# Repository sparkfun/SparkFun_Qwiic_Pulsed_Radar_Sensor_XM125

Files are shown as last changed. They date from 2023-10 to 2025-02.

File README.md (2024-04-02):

SparkFun Pulsed Coherent Radar Sensor - Acconeer XM125 (Qwiic)
========================================

SparkFun Pulsed Coherent Radar Sensor – Acconeer XM125 (Qwiic) (https://www.sparkfun.com/products/24540)

[*SparkFun Pulsed Coherent Radar Sensor – Acconeer XM125 (Qwiic) (SEN-24540)*](https://www.sparkfun.com/products/24540)

Forget ultrasonic and infrared sensors; the SparkFun Qwiic Pulsed Coherent Radar Sensor - Acconeer XM125 brings powerful 60 GHz radar technology to your projects. This sensor isn't limited to surface detection; it can see through walls, cabinets, and even pockets (depending on the material), making it perfect for unique applications. Measure distances with millimeter precision, detect motion, the speed of an object, or even gestures!

The XM125 boasts an impressive range of up to 20 meters, allowing you to create long-range sensing projects. The actual measurable distance is dependent on the object size, shape, dielectric properties, and lens (e.g. water level measurements up to 20 meters with lens utilization, human presence detection up to 7 meters with lens-free utilization). Despite its power, the sensor has remarkably low in power consumption, which is ideal for battery-powered applications. The real magic lies in the sensor's ability to do more than measure distance; the XM125 can differentiate between stationary objects and moving targets using pulsed coherent radar. This means you can sense an object's presence and how fast something is moving!

We've included a USB type-C connector, ESD protection diodes on the USB data lines, and a CH340C USB-to-serial converter to connect the XM125 directly to your computer's COM port. Power is regulated down for the XM125 with the AP2112K 3.3V/600mA and RT9080 1.8V/600mA voltage regulators. Buttons for reset and boot are included when resetting the module or setting the board into bootloader mode. Utilizing our handy Qwiic system, no soldering is required to connect it to the rest of your system. However, we still have broken out 0.1in.-spaced pins if you prefer a breadboard.

We've written an Arduino library when the I<sup>2</sup>C presence or distance detection firmware is loaded onto the XM125 module. With the I<sup>2</sup>C presence detection firmware, you can sense when an object is moving in an environment and how far away it is from the sensor. You can detect slow and fast movements with the inter-presence and intra-presence scores, respectively. The I<sup>2</sup>C distance detection firmware is similar to the presence detector by providing distance measurements. However, distance detection will provide information when it detects objects within range. The distance detection firmware can also adjust the sensor's threshold and sensitivity. The read range can also be configured to a certain distance away with either firmware.

Acconeer has also developed a visualization tool written in Python that demonstrates data collection in real time. The [Acconeer Exploration Tool](https://github.com/acconeer/acconeer-python-exploration) is an incredible resource, especially when starting out with the XM125 module to debug and explore the sensor's capabilities. This allows you to fine-tune the sensor for your application. For example, it will graph distance or presence sensing, giving you a count of the number of sweeps, which communication port data is being sent through, and much more. It will also guide you to the optimal sensor settings and help you fine-tune the data processing for your final product implementation. The tool supports Windows and Linux and requires Python version 3.8 or later. This tool is available through their GitHub Repository. Head on over and take a look!

With the SparkFun Qwiic Pulsed Coherent Radar Sensor, a world of new project possibilities opens up. Imagine creating presence detection systems for smart homes and security applications, parking space occupancy detection, gesture recognition interfaces for unique user control, level measurement (for example, in tanks or waste containers), through-wall imaging systems for search and rescue, or even advanced robotics with object avoidance and navigation.

Repository Contents
-------------------

* **.github/workflows** - YAML files used for GitHub Actions and GitHub Pages/mkdocs
* **/Firmware** - Firmware for the XM125 module
* **/Hardware** - Eagle design files (.brd, .sch)
  * **/Production** - Production panel files (.brd)
* **/docs** - Online documentation files
  * **/assets** - Folder containing all the file assets used for product documentation
    * **/board_files** - Copy of design files used for product documentation
    * **/component_documentation** - Datasheets and manuals for hardware components
    * **/img** - Images for product documentation
  * **/github** - Files stating how to contribute and filing issues used for product documentation
  * **/javascript** - Folder containing custom javascript used for product documentation
  * **/stylesheet** - Folder containing CSS files used for product documentation
* **/overrides** - Customization files used for product documentation
  * **/.icons** - Icons used for GitHub used for product documentation
  * **./partials** - Used for product documentation

Documentation
--------------
* **[Library](https://github.com/sparkfun/SparkFun_Qwiic_XM125_Arduino_Library)** - Arduino library for the SparkFun Qwiic Pulsed Coherent Radar Sensor - XM125.
* **[Hookup Guide](https://docs.sparkfun.com/SparkFun_Qwiic_Pulsed_Radar_Sensor_XM125)** - Basic hookup guide for the SparkFUn Qwiic Pulsed Coherent Radar Sensor - XM125.

Product Versions
----------------
* [SEN-24540](https://www.sparkfun.com/products/24540) - Initial Release

Version History
---------------
* V1.0 - Intial Release

License Information
-------------------

This product is _**open source**_! 

Please review the LICENSE.md file for license information. 

If you have any questions or concerns on licensing, please contact technical support on our [SparkFun forums](https://forum.sparkfun.com/viewforum.php?f=152).

Distributed as-is; no warranty is given.

- Your friends at SparkFun.

_<COLLABORATION CREDIT>_

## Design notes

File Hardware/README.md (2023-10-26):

SparkFun <PRODUCT NAME> Design Files
=====================================

The .sch and .brd files hare are Eagle CAD schematic and PCB design files from SparkFun Electronics.
A freeware version of Autodesk Eagle can be found [here](https://www.autodesk.com/products/eagle/free-download).

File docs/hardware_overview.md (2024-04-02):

In this section, we will highlight the hardware and pins that are broken out on the SparkFun Pulsed Coherent Radar Sensor - XM125 (Qwiic). For more information, check out our [Resources and Going Further](../resources/) for the XM125 Module and the A121 Pulsed Coherent Radar Sensor.

<div style="text-align: center;">
  <table>
    <tr style="vertical-align:middle;">
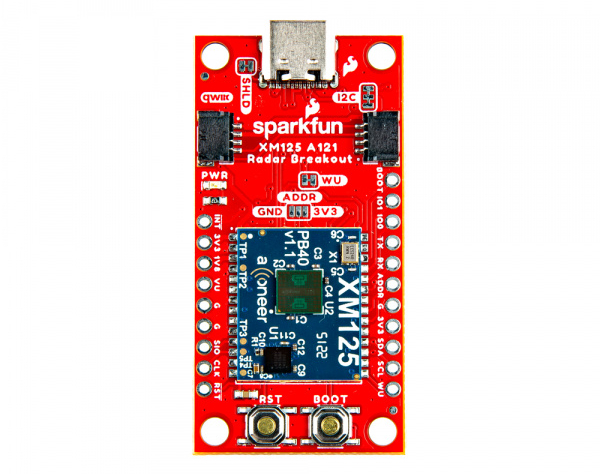
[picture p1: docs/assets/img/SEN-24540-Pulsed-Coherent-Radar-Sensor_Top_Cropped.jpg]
Top View
     <td style="text-align: center; vertical-align: middle; border: solid 1px #cccccc;"></td>
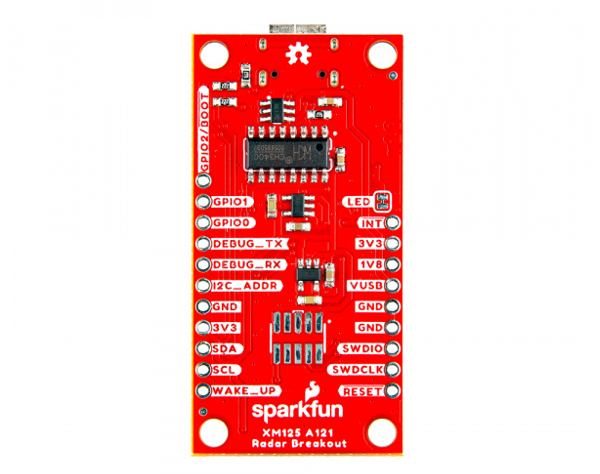
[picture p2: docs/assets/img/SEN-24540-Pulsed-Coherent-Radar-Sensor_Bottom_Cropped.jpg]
Bottom View
     <td style="text-align: center; vertical-align: middle; border: solid 1px #cccccc;"></td>
    </tr>
    <tr style="vertical-align:middle;">
     <td style="text-align: center; vertical-align: middle; border: solid 1px #cccccc;"><i>Top View</i></td>
     <td style="text-align: center; vertical-align: middle; border: solid 1px #cccccc;"><i>Bottom View</i></td>
    </tr>
  </table>
</div>

### XM125 Module

The board breaks out the Acconeer XM125 module with some application circuits.

<div style="text-align: center;">
  <table>
    <tr style="vertical-align:middle;">
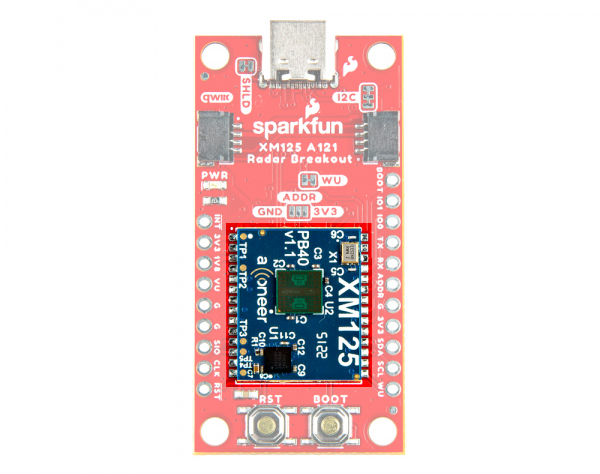
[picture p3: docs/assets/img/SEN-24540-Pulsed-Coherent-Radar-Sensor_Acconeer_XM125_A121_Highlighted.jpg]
Acconeer XM125 Module
     <td style="text-align: center; vertical-align: middle; border: solid 1px #cccccc;"></td>
    </tr>
    <tr style="vertical-align:middle;">
     <td style="text-align: center; vertical-align: middle; border: solid 1px #cccccc;"><i>Acconeer XM125 Module</i></td>
    </tr>
  </table>
</div>

Below are a few specifications from the datasheet.

* Acconeer XM125 Module
    * A121
        * 60GHz Pulsed Coherent Radar (PCR)
        * Integrated Baseband, RF Front-End and Antenna in Package
        * Detect Distance, Speed, Motion, and Objects up to 20 Meters**&#42;** Away
        * Millimeter Precise Readings
        * Low Power Consumption
    * STMicroelectronics STM32L431CBY6
        * 32-bit Arm&reg; Cortex&reg; M4 MCU
        * Clock Speed: 80 MHz
        * Flash: 128kB
        * RAM: 68kB

!!! note "*Note"
    The actual measurable distance is dependent on the object size, shape, dielectric properties, and lens (e.g. water level measurements up to 20 meters with lens utilization, human presence detection up to 7 meters with lens-free utilization).

For users using the XM125 module to detect objects through a material (especially for those placing the board in an enclosure), you may want to check out [Acconeer's Hardware and Physical Integration Guideline PCR Sensors A111 & A121 User Guide](../assets/component_documentation/Hardware-integration-guideline.pdf).

<div style="text-align: center"><a href="../assets/component_documentation/Hardware-integration-guideline.pdf" class="md-button">Acconeer's Hardware and Physical Integration Guideline PCR Sensors A111 & A121 User Guide</a></div>

!!! note
    Due to the higher frequencies, pulsed coherent radar sensors may be regulated in certain countries. Be sure to check local regulations before use.

### Power

There are a variety of power and power-related nets broken out to the USB connector, Qwiic connectors and plated through holes. **5V** power from the USB C Connector or PTH is regulated down to _3.3V_ with the AP2112K 3.3V/600mA voltage regulator. The voltage is further regulated down to _1.8V_ with the RT9080 1.8V/600mA voltage regulator. The logic levels for the XM125 is **3.3V** for the I/O pins.

* **VU** / **VUSB** &mdash; Power from the USB C connector's VBUS provides power to the V_BUS. The V_USB net is also connected to the edge PTH pin labeled as **VU** on the top of the board and **VUSB** on the bottom of the board. This is also connected to the input of the 3.3V voltage regulator. Make sure that power you provide to this pin does not exceed 6 volts.
* **3V3** &mdash; This connects to the 3.3V net. Both sides of the board includes a 3.3V pin (labeled as 3V3). The output of the AP2112K 3.3V voltage regulator and input of the RT9080 1.8V voltage regulator are connected to this net. 3.3V net can also be accessed through one of the Qwiic connector's pins. You should only provide a clean 3.3V power signal to those pins.
* **G** / **GND** &mdash; Of course, is the common, ground voltage (0V reference) for the system.

<div style="text-align: center;">
  <table>
    <tr style="vertical-align:middle;">
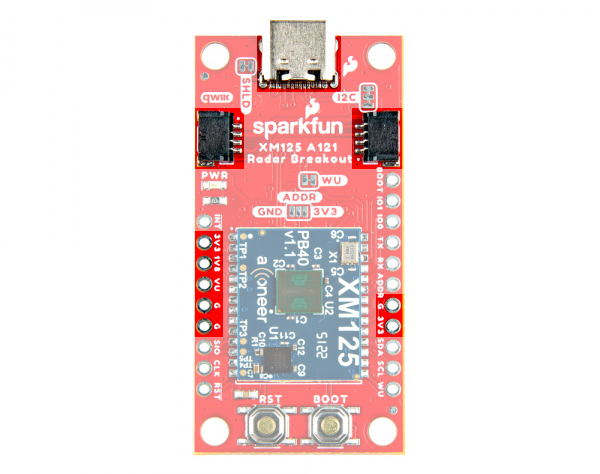
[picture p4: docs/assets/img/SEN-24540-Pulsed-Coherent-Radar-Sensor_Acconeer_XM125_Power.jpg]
Power from USB, Qwiic, and PTHs, Top View
     <td style="text-align: center; vertical-align: middle; border: solid 1px #cccccc;"></td>
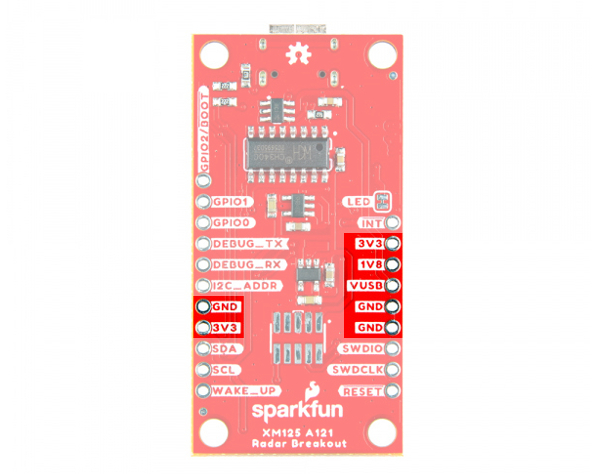
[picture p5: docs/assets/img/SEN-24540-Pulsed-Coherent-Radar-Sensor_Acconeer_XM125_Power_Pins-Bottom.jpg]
Power from PTHs, Bottom View
     <td style="text-align: center; vertical-align: middle; border: solid 1px #cccccc;"></td>
    </tr>
    <tr style="vertical-align:middle;">
     <td style="text-align: center; vertical-align: middle; border: solid 1px #cccccc;"><i>Power from USB, Qwiic, and PTHs <br />(Top View)</i></td>
     <td style="text-align: center; vertical-align: middle; border: solid 1px #cccccc;"><i>Power from PTHs <br />(Bottom View)</i></td>
    </tr>
  </table>
</div>

### CH340C USB-to-Serial Converter

ON the back of the board is a built-in CH340 USB-to-serial converter to connect the XM125's primary UART to a computer's USB port. This is useful for users viewing data, configuring the XM125, or updating firmware. ESD protection diodes are included between the USB C and the CH340C's USB data lines.

<div style="text-align: center;">
  <table>
    <tr style="vertical-align:middle;">
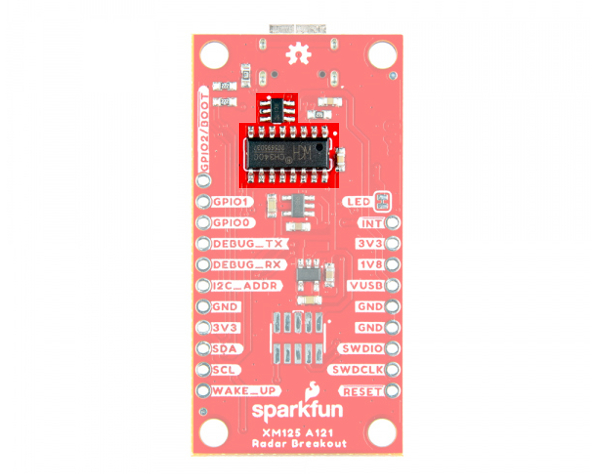
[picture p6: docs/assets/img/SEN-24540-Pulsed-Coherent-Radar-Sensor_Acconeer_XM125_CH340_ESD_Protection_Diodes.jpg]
CH340C Highlighted
     <td style="text-align: center; vertical-align: middle; border: solid 1px #cccccc;"></td>
    </tr>
    <tr style="vertical-align:middle;">
     <td style="text-align: center; vertical-align: middle; border: solid 1px #cccccc;"><i>TVS Diodes, and CH340 Highlighted</i></td>
    </tr>
  </table>
</div>

### UARTs

The board has two UARTs. The primary UART (not highlighted in the image below) is connected internally to the CH340C USB-to-Serial converter. There is also a debugging UART that is broken out on the edge of the board.

* **TX** / **DEBUG_TX** &mdash; TX out for debugging
* **RX** / **DEBUG_RX** &mdash; RX in for debugging

<div style="text-align: center;">
  <table>
    <tr style="vertical-align:middle;">
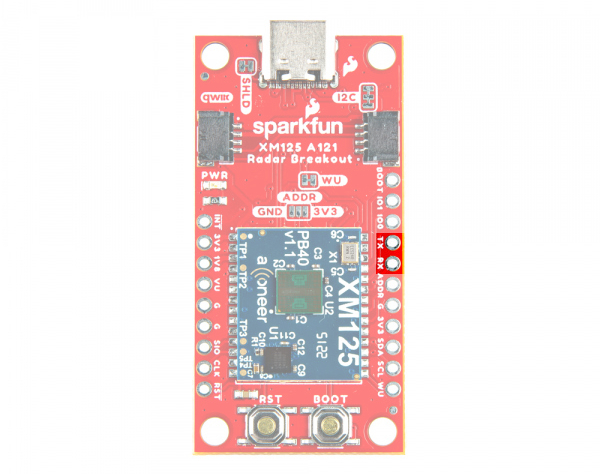
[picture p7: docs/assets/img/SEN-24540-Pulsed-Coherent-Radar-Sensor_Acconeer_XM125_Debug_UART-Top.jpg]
Debugging UART Pins, Top View
     <td style="text-align: center; vertical-align: middle; border: solid 1px #cccccc;"></td>
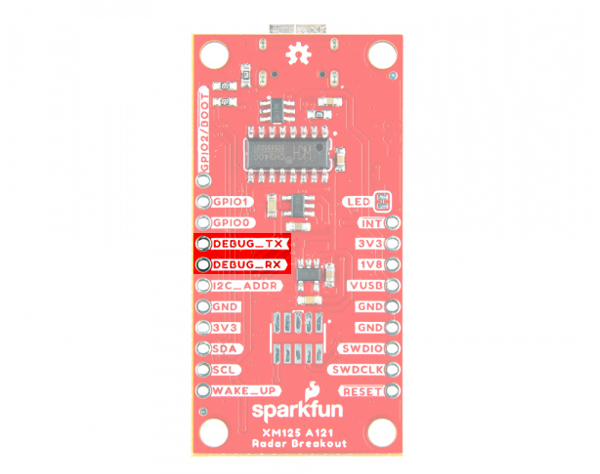
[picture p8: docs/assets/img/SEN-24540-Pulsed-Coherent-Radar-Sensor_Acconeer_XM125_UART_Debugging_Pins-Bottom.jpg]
Debugging UART Pins, Bottom View
     <td style="text-align: center; vertical-align: middle; border: solid 1px #cccccc;"></td>
    </tr>
    <tr style="vertical-align:middle;">
     <td style="text-align: center; vertical-align: middle; border: solid 1px #cccccc;"><i>Debugging UART Pins <br />(Top View)</i></td>
     <td style="text-align: center; vertical-align: middle; border: solid 1px #cccccc;"><i>Debugging UART Pins <br />(Bottom View)</i></td>
    </tr>
  </table>
</div>

!!! note
    To enable or disable UART logging, you will need to call the function after resetting the XM125 in the `setup()` function (i.e. `radarSensor.setPresenceCommand(SFE_XM125_PRESENCE_RESET_MODULE);`). Make sure to call the `distanceEnableUartLogs()`, `distanceDisableUartLogs()`, `presenceEnableUartLogs()`, or `presenceDisableUartLogs()` function before applying the configuration using the `radarSensor.setPresenceCommand(SFE_XM125_PRESENCE_APPLY_CONFIGURATION)`. The functions correspond the firmware for the presence and distance detection firmware, respectively.

### Qwiic and I<sup>2</sup>C

There are two PTHs labeled **SDA** and **SCL** on one side of the board. These are the I<sup>2</sup>C data and clock lines and are connected to two 2.2k&ohm; pull-up resistors. We also conveniently added a GND and 3.3V pin on one side should you decide to daisy chain additional I<sup>2</sup>C devices to the PTH. Similarly, you can use either of the Qwiic connectors to provide power and send data through I<sup>2</sup>C. The [Qwiic ecosystem](https://www.sparkfun.com/qwiic) is made for fast prototyping by removing the need for soldering. All you need to do is plug a Qwiic cable into the Qwiic connector and voila!

* **SDA** &mdash; I<sup>2</sup>C data
* **SCL** &mdash; I<sup>2</sup>C clock

<div style="text-align: center;">
  <table>
    <tr style="vertical-align:middle;">
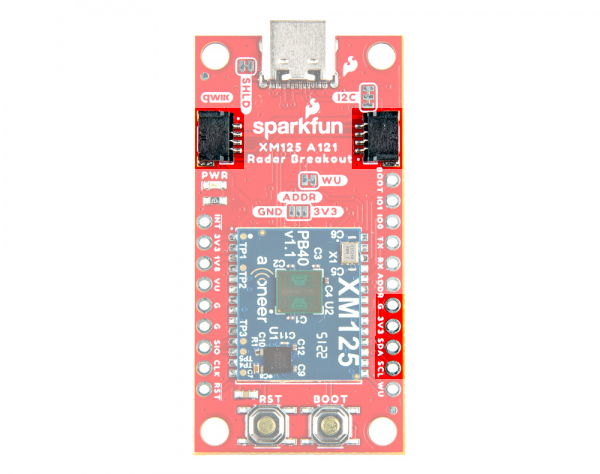
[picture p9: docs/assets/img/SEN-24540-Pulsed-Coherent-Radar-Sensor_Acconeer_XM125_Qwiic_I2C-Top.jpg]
I2C Pins and Qwiic Connectors, Top View
     <td style="text-align: center; vertical-align: middle; border: solid 1px #cccccc;"></td>
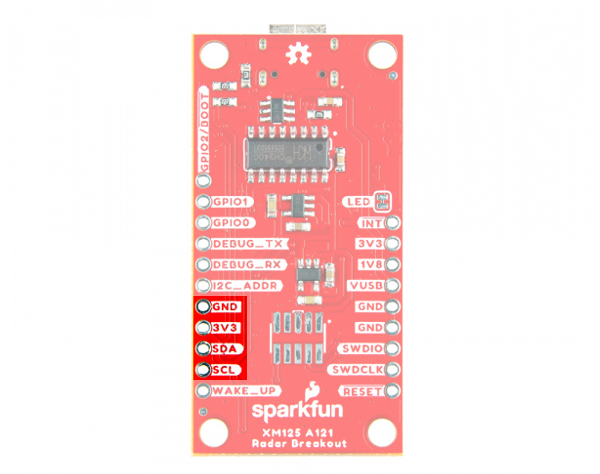
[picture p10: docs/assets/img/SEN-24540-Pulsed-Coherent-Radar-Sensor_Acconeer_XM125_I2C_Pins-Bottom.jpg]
I2C Pins, Bottom View
     <td style="text-align: center; vertical-align: middle; border: solid 1px #cccccc;"></td>
    </tr>
    <tr style="vertical-align:middle;">
     <td style="text-align: center; vertical-align: middle; border: solid 1px #cccccc;"><i>I2C and Qwiic Connectors <br />(Top View)</i></td>
     <td style="text-align: center; vertical-align: middle; border: solid 1px #cccccc;"><i>I2C Pins <br />(Bottom View)</i></td>
    </tr>
  </table>
</div>

The default address of the XM125 is set to **0x52**.

### Reset and Boot Buttons

We included two low profile buttons for reset and bootloader.

* **RST** / <b><span STYLE="text-decoration:overline">RST</span></b> / <b><span STYLE="text-decoration:overline">RESET</span></b> &mdash; Pressing down on the reset button will connect the pin to ground and reset the XM125. This is also broken out to a PTH on the edge of the board.
* **BOOT** / <b>GPIO2/<span STYLE="text-decoration:overline">BOOT</span></b> &mdash; Pressing down on the boot button will connect the pin to 3.3V. This will put it into bootloader mode when the XM125 is starting up. This is also broken out to a PTH on the edge of the board.  The alternative function of this pin is also used as a general purpose I/O. This can be configurable for different functions. At the time of writing, GPIO2 is not functional with the current firmware. The functionality is to be implemented in the future.

<div style="text-align: center;">
  <table>
    <tr style="vertical-align:middle;">
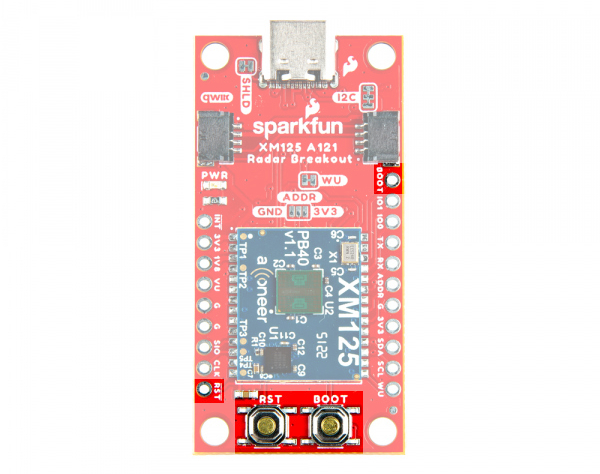
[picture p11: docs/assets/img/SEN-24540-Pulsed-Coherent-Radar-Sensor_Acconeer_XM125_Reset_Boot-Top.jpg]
Reset and Boot Pins and Buttons, Top View
     <td style="text-align: center; vertical-align: middle; border: solid 1px #cccccc;"></td>
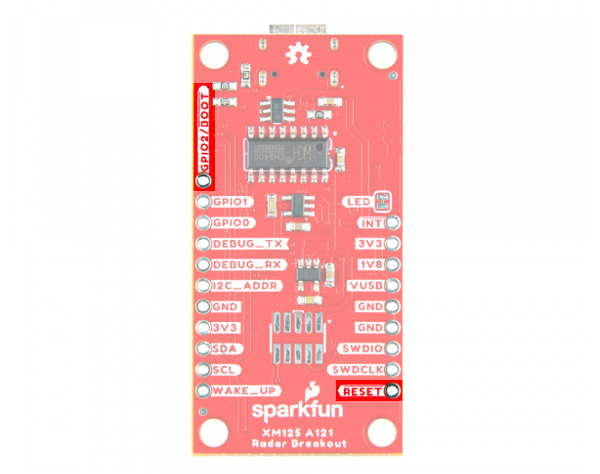
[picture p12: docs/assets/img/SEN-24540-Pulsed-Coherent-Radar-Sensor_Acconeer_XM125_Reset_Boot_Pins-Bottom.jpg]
Reset and Boot Pins , Bottom View
     <td style="text-align: center; vertical-align: middle; border: solid 1px #cccccc;"></td>
    </tr>
    <tr style="vertical-align:middle;">
     <td style="text-align: center; vertical-align: middle; border: solid 1px #cccccc;"><i>Reset and Boot Pins and Buttons <br />(Top View)</i></td>
     <td style="text-align: center; vertical-align: middle; border: solid 1px #cccccc;"><i>Reset and Boot Pins <br />(Bottom View)</i></td>
    </tr>
  </table>
</div>

!!! note
    We included low profile buttons on the board to reduce the amount of reflections when using the XM125.

### SWD Pins

The edge of the board includes the SWDIO and SWDCLK programming pins. On the back of the board, there is a 2x5 SWD footprint to solder a [SMD 2x5 header](https://www.sparkfun.com/products/22890). This is available for users that want to debug and flash the XM125's STM32L431 using a programmer.

* **SWDIO** &mdash; Serial wire debug I/O.
* **SWDCLK** &mdash; Serial wire debug clock.

<div style="text-align: center;">
  <table>
    <tr style="vertical-align:middle;">
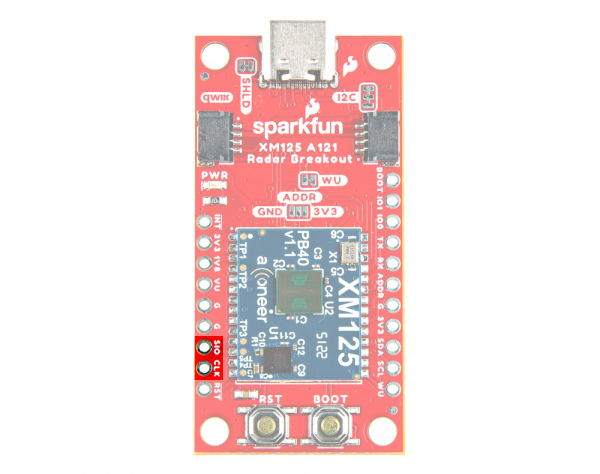
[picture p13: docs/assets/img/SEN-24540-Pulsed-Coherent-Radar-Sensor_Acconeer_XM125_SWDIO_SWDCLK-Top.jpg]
     <td style="text-align: center; vertical-align: middle; border: solid 1px #cccccc;"></td>
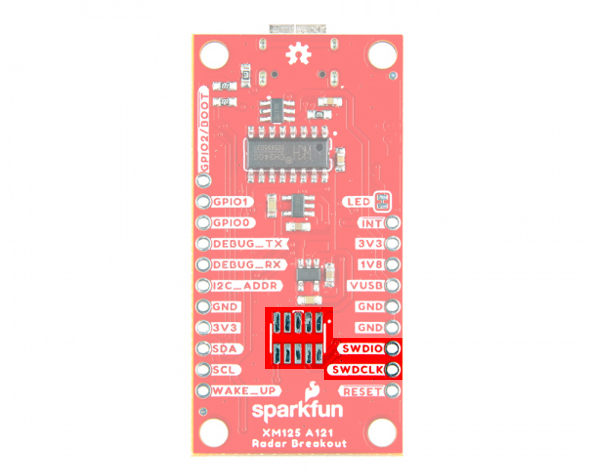
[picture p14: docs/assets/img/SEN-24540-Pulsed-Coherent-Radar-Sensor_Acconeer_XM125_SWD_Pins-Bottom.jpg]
SWD Pins, Bottom View
     <td style="text-align: center; vertical-align: middle; border: solid 1px #cccccc;"></td>
    </tr>
    <tr style="vertical-align:middle;">
     <td style="text-align: center; vertical-align: middle; border: solid 1px #cccccc;"><i>SWD Pins <br />(Top View)</i></td>
     <td style="text-align: center; vertical-align: middle; border: solid 1px #cccccc;"><i>SWD Pins <br />(Bottom View)</i></td>
    </tr>
  </table>
</div>

### Broken Out Pins

Below are the other pins broken out:

* **<span STYLE="text-decoration:overline">INT</span>** &mdash; Interrupt output pin. This pin could be used to send an interrupt from the XM125 to a host microcontroller.
* **GPIO1** &mdash; General purpose I/O. This can be configurable for different functions. At the time of writing, GPIO1 are not functional with the current firmware. The functionality is to be implemented in the future.
* **GPIO0** &mdash; General purpose I/O. This can be configurable for different functions. This pin is currently only functional with the presence detector firmware, specifically the _i2c_presence_detector.bin_ .
* **I2C_ADDR** &mdash; This pin is used to configure the I<sup>2</sup>C Address. This is also connected to the three way jumper labeled as ADDR. The functionality is to be implemented in the future.
* **WU** / **WAKE_UP** &mdash; This pin is used to set the XM125 in low power mode. This is connected to the WU jumper and 3.3V. To toggle low power mode using a microcotrller, you will need to cut the WU jumper and solder the pin to a microcontroller's GPIO pin. Setting the pin high will wake the XM125 up from low power mode.

<div style="text-align: center;">
  <table>
    <tr style="vertical-align:middle;">
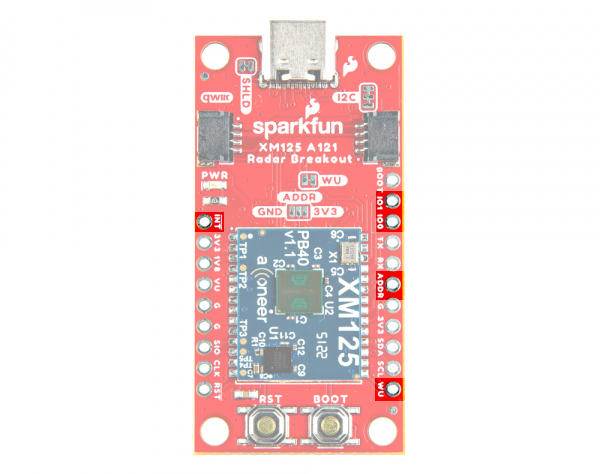
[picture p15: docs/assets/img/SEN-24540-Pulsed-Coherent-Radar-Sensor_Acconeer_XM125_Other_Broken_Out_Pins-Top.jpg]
SWD Pins, Top View
     <td style="text-align: center; vertical-align: middle; border: solid 1px #cccccc;"></td>
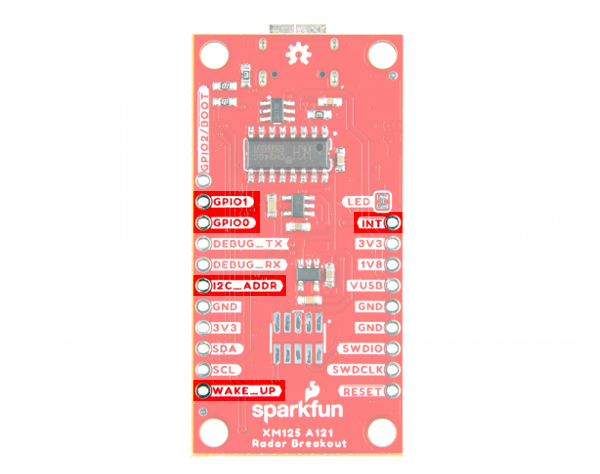
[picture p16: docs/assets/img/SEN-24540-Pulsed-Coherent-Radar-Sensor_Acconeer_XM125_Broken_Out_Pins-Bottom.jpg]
SWD Pins, Bottom View
     <td style="text-align: center; vertical-align: middle; border: solid 1px #cccccc;"></td>
    </tr>
    <tr style="vertical-align:middle;">
     <td style="text-align: center; vertical-align: middle; border: solid 1px #cccccc;"><i>SWD Pins <br />(Top View)</i></td>
     <td style="text-align: center; vertical-align: middle; border: solid 1px #cccccc;"><i>SWD Pins <br />(Bottom View)</i></td>
    </tr>
  </table>
</div>

### LED

The board includes the following status LED as indicated in the image below.

* **PWR** &mdash; Indicates when there is 3.3V available.

<div style="text-align: center;">
  <table>
    <tr style="vertical-align:middle;">
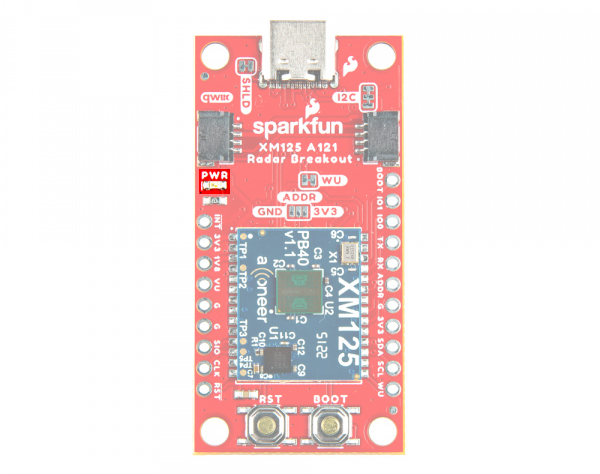
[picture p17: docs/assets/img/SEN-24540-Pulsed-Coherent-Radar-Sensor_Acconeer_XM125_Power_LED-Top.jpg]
LED Highlighted
     <td style="text-align: center; vertical-align: middle; border: solid 1px #cccccc;"></td>
    </tr>
    <tr style="vertical-align:middle;">
     <td style="text-align: center; vertical-align: middle; border: solid 1px #cccccc;"><i>LED Highlighted</i></td>
    </tr>
  </table>
</div>

### Jumpers

!!!note
    If this is your first time working with jumpers, check out the [How to Work with Jumper Pads and PCB Traces](https://learn.sparkfun.com/tutorials/how-to-work-with-jumper-pads-and-pcb-traces/all) tutorial for more information.

There are jumper pads on the top and bottom of the board.

* **SHLD** &mdash; This jumper is located on the top of the board and connects the USB Type C connector's shield pin to GND. By default, this is closed. Cut this to isolate the USB Type C connector's shield pin.
* **I2C** &mdash; This three way jumper is located on the top of the board and labeled **I2C**. By default, this three way jumper is closed. This jumper is connected to two pull-up resistors on the I<sup>2</sup>C data and clock lines. For users that have multiple Qwiic-enabled devices with pull-up resistors enabled, the parallel equivalent resistance will create too strong of a pull-up for the bus to operate correctly. As a general rule of thumb, [disable all but one pair of pull-up resistors](https://learn.sparkfun.com/tutorials/i2c/all#i2c-at-the-hardware-level) if multiple devices are connected to the bus.
* **WU** &mdash; This jumper is located on the top of the board. By default, this jumper is closed. This jumper connects 3.3V with the wake up pin. Cut this trace to enter low power mode.
* **ADDR** &mdash; This three way jumper is located on the top of the board and labeled **ADDR**. By default, this three-way jumper is open. This jumper is used to adjust the I<sup>2</sup>C address of the XM125 module. Adding a solder blob between the center and the pad on either side will change the default address. The functionality is to be implemented in the future.
* **LED** &mdash; This jumper is located on the bottom of the board and connects the LED to 3.3V. Cut this jumper to disable the LED.

<div style="text-align: center;">
  <table>
    <tr style="vertical-align:middle;">
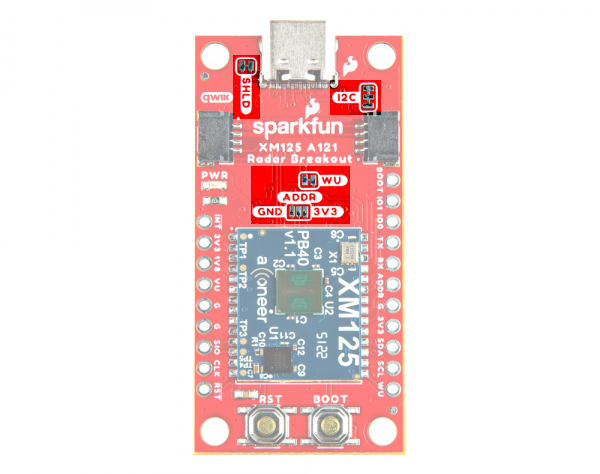
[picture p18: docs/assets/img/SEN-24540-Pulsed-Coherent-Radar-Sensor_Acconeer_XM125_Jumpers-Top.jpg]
Jumpers Highlighted, Top Side
     <td style="text-align: center; vertical-align: middle; border: solid 1px #cccccc;"></td>
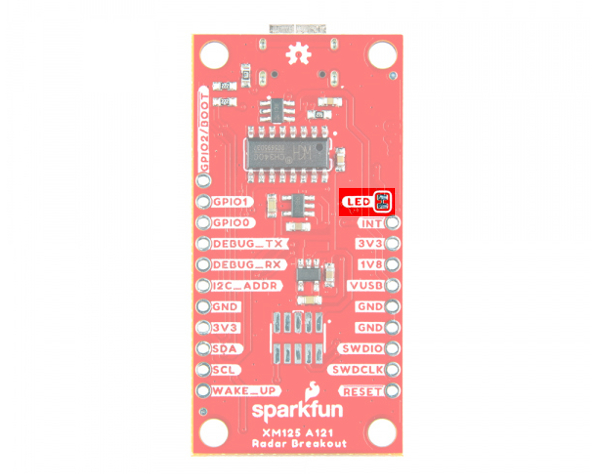
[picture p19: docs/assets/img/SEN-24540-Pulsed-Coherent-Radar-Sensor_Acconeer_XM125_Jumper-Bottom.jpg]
Jumpers Highlighted, Bottom Side
     <td style="text-align: center; vertical-align: middle; border: solid 1px #cccccc;"></td>
    </tr>
    <tr style="vertical-align:middle;">
     <td style="text-align: center; vertical-align: middle; border: solid 1px #cccccc;"><i>MEAS PTH Highlighted - Top View</i></td>
     <td style="text-align: center; vertical-align: middle; border: solid 1px #cccccc;"><i>Jumpers Highlighted Highlighted - Bottom View</i></td>
    </tr>
  </table>
</div>

### Board Dimensions

The board is 1.0" x 2.0" (25.4mm x 50.8mm). There are 4x mounting holes by each corner of the board for 4-40 screws and standoffs.

<div style="text-align: center;">
  <table>
    <tr style="vertical-align:middle;">
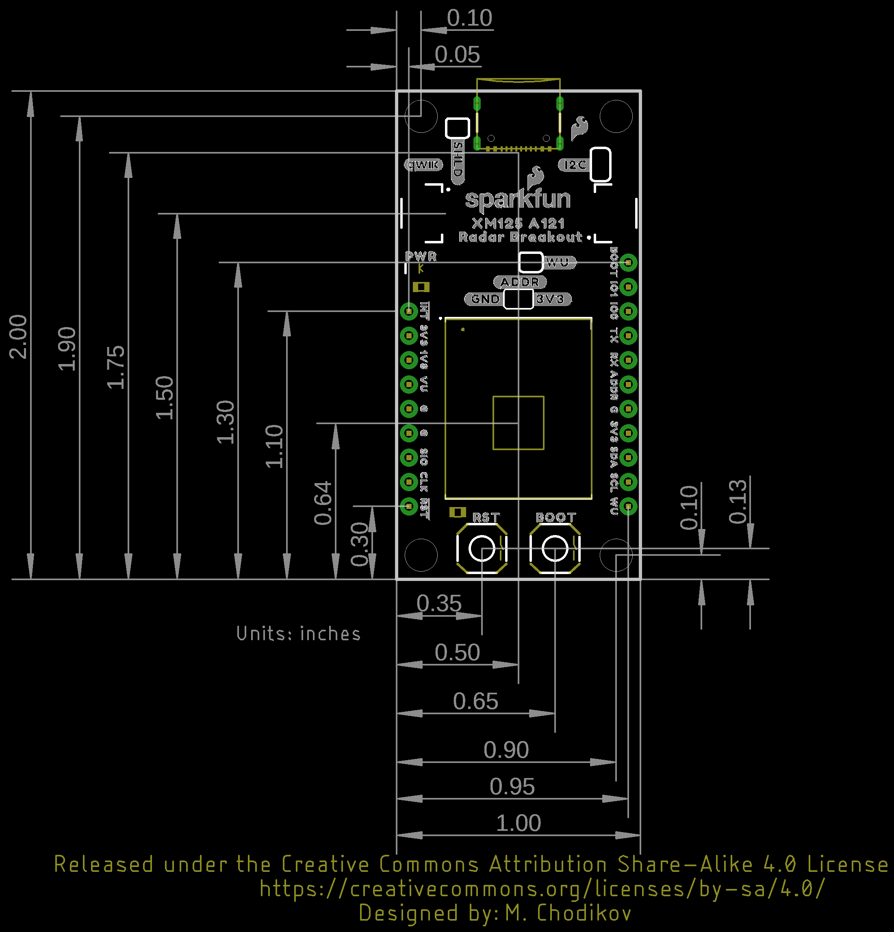
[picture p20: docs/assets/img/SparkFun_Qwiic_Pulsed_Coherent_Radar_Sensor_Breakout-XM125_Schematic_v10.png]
Board Dimensions
     <td style="text-align: center; vertical-align: middle; border: solid 1px #cccccc;"></td>
    </tr>
    <tr style="vertical-align:middle;">
     <td style="text-align: center; vertical-align: middle; border: solid 1px #cccccc;"><i>Board Dimensions</i></td>
    </tr>
  </table>
</div>

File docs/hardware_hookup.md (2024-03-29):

In this section, we'll go over how to connect to the SparkFun Pulsed Coherent Radar Sensor - Acconeer XM125 (Qwiic). Depending on your application, you can connect the board directly to your computer.  For embedded application, you can also connect the board to the IoT RedBoard - ESP32.

### USB to SparkFun Pulsed Coherent Radar Sensor

For users that simply want to connect to the board via USB, you will just need to insert a USB C cable into the USB connector. Then connect the other end to your computer's USB port.

<div style="text-align: center;">
  <table>
    <tr style="vertical-align:middle;">
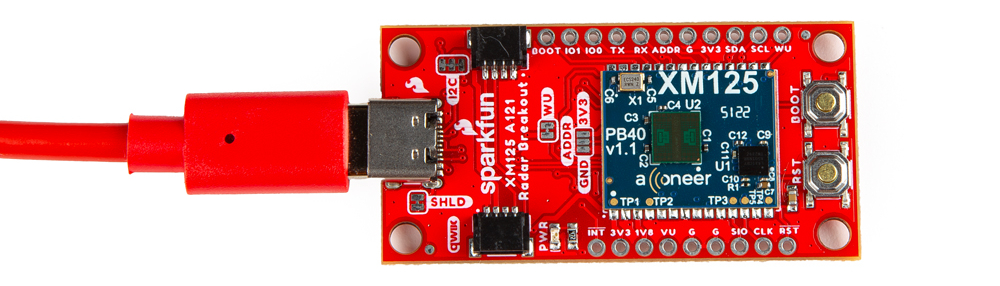
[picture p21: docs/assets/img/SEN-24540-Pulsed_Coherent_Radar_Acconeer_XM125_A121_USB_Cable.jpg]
USB Cable Inserted into Pulsed Coherent Radar Sensor
     <td style="text-align: center; vertical-align: middle;"></td>
    </tr>
  </table>
</div>

### Connecting a USB and Qwiic Cable

!!! note
    We recommend using the IoT RedBoard - ESP32 for the scope of this tutorial.

For this example, we will use the IoT RedBoard - ESP32 and its associated cable. Connecting the boards with a Qwiic cable is very simple. Plug a Qwiic cable between the RedBoard IoT and the SparkFun Pulsed Coherent Radar Sensor. If you're going to be soldering to the through hole pins, then just attach lines to power, ground, and the I<sup>2</sup>C data lines to the microcontroller of your choice. To power and program the IoT RedBoard - ESP32, users will just need to insert the Type C side of the cable to the development board. The other end will connect to a computer's USB port.

<div style="text-align: center;">
  <table>
    <tr style="vertical-align:middle;">
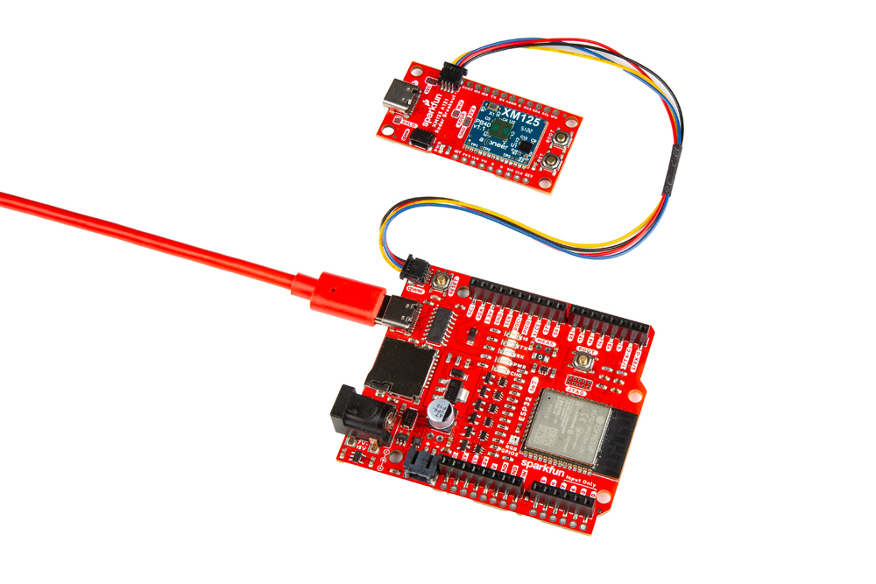
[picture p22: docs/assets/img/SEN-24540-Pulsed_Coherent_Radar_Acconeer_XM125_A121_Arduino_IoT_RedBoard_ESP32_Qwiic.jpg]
USB Cable Inserted into IoT RedBoard - ESP32 and Qwiic cable between the IoT RedBoard and SparkFun Pulsed Coherent Radar Sensor
     <td style="text-align: center; vertical-align: middle;"></td>
    </tr>
  </table>
</div>

!!! note
    For users that are testing the XM125 to detect objects from across the room, you may want to consider using a [3rd hand](https://www.sparkfun.com/products/19944) to hold the board up.

### Connecting via PTH

For temporary connections to the PTHs, you could use IC hooks to test out the pins. However, you'll need to solder headers or wires of your choice to the board for a secure connection. You can choose between a combination of [header pins and jumper wires](https://learn.sparkfun.com/tutorials/how-to-solder-through-hole-soldering/all), or [stripping wire and soldering the wire](https://learn.sparkfun.com/tutorials/working-with-wire/all) directly to the board.

<div class="grid cards hide col-4" markdown>

-   <a href="https://learn.sparkfun.com/tutorials/how-to-solder-through-hole-soldering/all">
      <figure markdown>
        How to Solder: Through Hole Soldering
      </figure>
    </a>

    ---

    <a href="https://learn.sparkfun.com/tutorials/how-to-solder-through-hole-soldering/all">
      <b>How to Solder: Through Hole Soldering</b>
    </a>
<!-- ----------WHITE SPACE BETWEEN GRID CARDS---------- -->

-   <a href="https://learn.sparkfun.com/tutorials/working-with-wire/all">
      <figure markdown>
        Working with Wire
      </figure>
    </a>

    ---

    <a href="https://learn.sparkfun.com/tutorials/working-with-wire/all">
      <b>Working with Wire</b>
    </a>
<!-- ----------WHITE SPACE BETWEEN GRID CARDS---------- -->
</div>

It is recommended to have a low profile when connecting headers or wires to the SparkFun Pulsed Coherent Radar Sensor to limit the amount of reflections. For users connecting IC hooks, we recommend placing them flush with the board or hooking them from the bottom side. Below is an example of the IC hooks connected from the sides when measuring GPIO0.

<div style="text-align: center;">
  <table>
    <tr style="vertical-align:middle;">
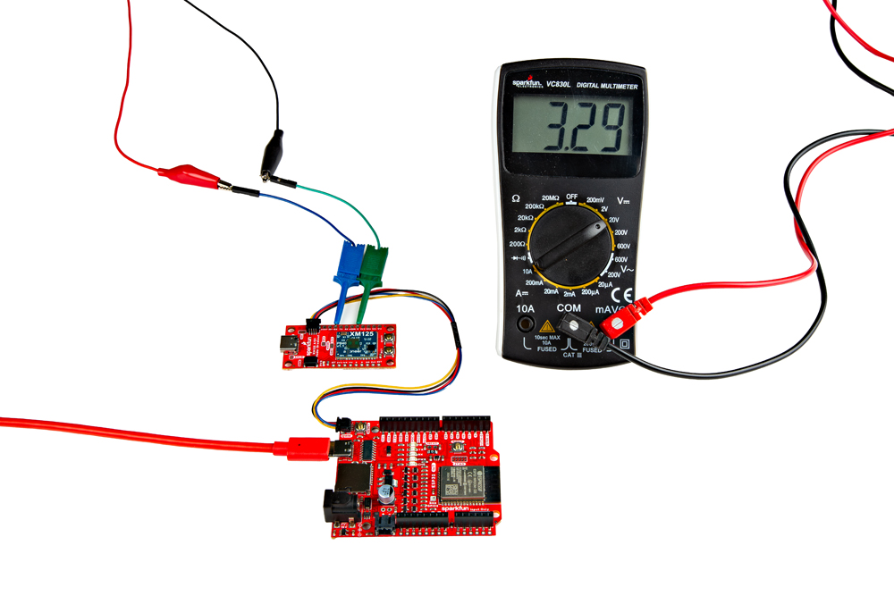
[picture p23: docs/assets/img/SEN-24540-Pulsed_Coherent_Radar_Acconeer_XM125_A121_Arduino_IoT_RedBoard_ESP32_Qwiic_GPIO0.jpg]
IC Hooks Connected to PTH from the Side
     <td style="text-align: center; vertical-align: middle;"></td>
    </tr>
  </table>
</div>

For users soldering to the board, make sure that there are no headers or wires protruding in front of the sensor. The image below shows straight header pins being soldered to the PTHs. For users that are using the breadboard, we recommend using [jumper wires](https://www.sparkfun.com/products/124) that are close to the board rather than having them protruding in front of the sensor.

<div style="text-align: center;">
  <table>
    <tr style="vertical-align:middle;">
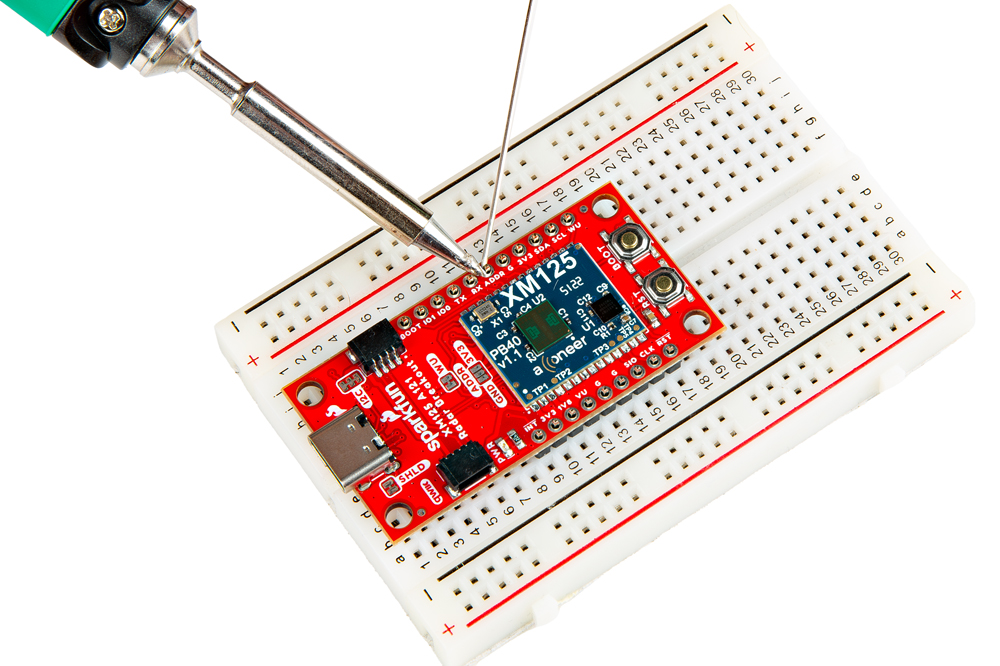
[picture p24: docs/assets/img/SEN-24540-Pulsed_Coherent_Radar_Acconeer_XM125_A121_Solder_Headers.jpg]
Soldering Headers to Board
     <td style="text-align: center; vertical-align: middle;"></td>
    </tr>
  </table>
</div>

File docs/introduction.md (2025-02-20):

The [SparkFun Qwiic Pulsed Coherent Radar Sensor features Acconeer's XM125 module](https://www.sparkfun.com/products/24540) and adds powerful 60 GHz radar technology to your projects. This sensor isn't limited to surface detection; it can see through walls, cabinets, and even pockets (depending on the material), making it perfect for unique applications. Measure distances with millimeter precision, detect motion, the speed of an object, or even gestures!

<center>
<div class="grid cards" style="width:500px;" markdown>

-   <a href="https://www.sparkfun.com/products/24540">
      <figure markdown>
        SparkFun Qwiic Pulsed Coherent Radar Sensor - Acconeer XM125
      </figure>
    </a>

    ---

    <a href="https://www.sparkfun.com/products/24540">
      <b>SparkFun Qwiic Pulsed Coherent Radar Sensor - Acconeer XM125</b>
      <br />
      SEN-24540
      <br />
      <center>[Purchase from SparkFun :fontawesome-solid-cart-plus:](https://www.sparkfun.com/products/24540){ .md-button .md-button--primary }</center>
    </a>
</div>
</center>

<div style="text-align: center;">
  <iframe width="560" height="315" src="https://www.youtube.com/embed/BdbWGezCCSg?si=iPh1UjlKv02k81HY" title="YouTube video player" frameborder="0" allow="accelerometer; autoplay; clipboard-write; encrypted-media; gyroscope; picture-in-picture; web-share" referrerpolicy="strict-origin-when-cross-origin" allowfullscreen></iframe>
</div>

The XM125 boasts an impressive range of up to 20 meters, allowing you to create long-range sensing projects. The actual measurable distance is dependent on the object size, shape, dielectric properties, and lens (e.g. water level measurements up to 20 meters with lens utilization, human presence detection up to 7 meters with lens-free utilization). Despite its power, the sensor has remarkably low in power consumption, which is ideal for battery-powered applications. The real magic lies in the sensor's ability to do more than measure distance. The XM125 can differentiate between stationary objects and moving targets using pulsed coherent radar. This means you can sense an object's presence and how fast it is moving.

In this tutorial, we'll go over the hardware and how to hookup the breakout board. We will also go over a few basic Arduino examples to get started!

### Required Materials

To follow along with this tutorial, you will need the following materials at a minimum. You may not need everything though depending on what you have. Add it to your cart, read through the guide, and adjust the cart as necessary.

* 1x [Reversible USB A to C Cable - 0.8m [CAB-15425]](https://www.sparkfun.com/products/15425)
* 1x [SparkFun IoT RedBoard - ESP32 Development Board [WRL-19177]](https://www.sparkfun.com/products/19177)
* 1x [Flexible Qwiic Cable - 100mm [PRT-17259]](https://www.sparkfun.com/products/17259)
* 1x [SparkFun Pulsed Coherent Radar Sensor - Acconeer XM125 (Qwiic) [SEN-24540]](https://www.sparkfun.com/products/24540)

<div class="grid cards hide col-4" markdown>

<!-- ----------WHITE SPACE BETWEEN PRODUCTS---------- -->
-   <a href="https://www.sparkfun.com/products/15425">
      <figure markdown>
        Reversible USB A to C Cable - 0.8m
      </figure>
    </a>

    ---

    <a href="https://www.sparkfun.com/products/15425">
      <b>Reversible USB A to C Cable - 0.8m</b>
      <br />
      CAB-15425
    </a>
<!-- ----------WHITE SPACE BETWEEN PRODUCTS---------- -->
-   <a href="https://www.sparkfun.com/products/19177">
      <figure markdown>
        SparkFun IoT RedBoard - ESP32 Development Board
      </figure>
    </a>

    ---

    <a href="https://www.sparkfun.com/products/19177">
      <b>SparkFun IoT RedBoard - ESP32 Development Board</b>
      <br />
      WRL-19177
    </a>
<!-- ----------WHITE SPACE BETWEEN PRODUCTS---------- -->
-   <a href="https://www.sparkfun.com/products/17259">
      <figure markdown>
        Flexible Qwiic Cable - 100mm
      </figure>
    </a>

    ---

    <a href="https://www.sparkfun.com/products/17259">
      <b>Flexible Qwiic Cable - 100mm</b>
      <br />
      PRT-17259
    </a>
<!-- ----------WHITE SPACE BETWEEN PRODUCTS---------- -->
-   <a href="https://www.sparkfun.com/products/24540">
      <figure markdown>
        SparkFun Qwiic Pulsed Coherent Radar Sensor - Acconeer XM125 (Qwiic)
      </figure>
    </a>

    ---

    <a href="https://www.sparkfun.com/products/24540">
      <b>SparkFun Qwiic Pulsed Coherent Radar Sensor - Acconeer XM125 (Qwiic)</b>
      <br />
      SEN-24540
    </a>
<!-- ----------WHITE SPACE BETWEEN PRODUCTS---------- -->
</div>

### Tools &nbsp;_(Optional)_

You will need a soldering iron, solder, and [general soldering accessories](https://www.sparkfun.com/categories/49) for a secure connection when using the plated through holes. You may also need a hobby knife to modify the jumpers.

<!--
* [PINECIL Soldering Iron Kit [TOL-24063]](https://www.sparkfun.com/products/24063)
* [Solder Lead Free - 15-gram Tube [TOL-9163]](https://www.sparkfun.com/products/9163)
* [Flush Cutters - Xcelite [TOL-14782]](https://www.sparkfun.com/products/14782)
* [Hook-Up Wire - Assortment (Stranded, 22 AWG) [PRT-11375]](https://www.sparkfun.com/products/11375)
* [Wire Stripper - 20-30 AWG Solid (22-32 AWG Stranded) [TOL-22263]](https://www.sparkfun.com/products/22263)
* [Magnetic Third-Hand Kit [TOL-19944](https://www.sparkfun.com/products/19944)]
* [Hobby Knife [TOL-09200]](https://www.sparkfun.com/products/9200)
* [Multimeter [TOL-12966]](https://www.sparkfun.com/products/12966)
* [Banana to Alligator Cable [CAB-00509](https://www.sparkfun.com/products/509)
* [Segger J-Link EDU Mini [PGM-24078]](https://www.sparkfun.com/products/24078)
-->

<div class="grid cards hide col-4" markdown>

-   <a href="https://www.sparkfun.com/products/24063">
      <figure markdown>
        PINECIL Soldering Iron Kit
      </figure>
    </a>

    ---

    <a href="https://www.sparkfun.com/products/24063">
      <b>PINECIL Soldering Iron Kit</b>
      <br />
      TOL-24063
    </a>
<!-- ----------WHITE SPACE BETWEEN PRODUCTS---------- -->
-   <a href="https://www.sparkfun.com/products/9163">
      <figure markdown>
        Solder Lead Free - 15-gram Tube
      </figure>
    </a>

    ---

    <a href="https://www.sparkfun.com/products/9163">
      <b>Solder Lead Free - 15-gram Tube</b>
      <br>
      TOL-09163
    </a>
<!-- ----------WHITE SPACE BETWEEN PRODUCTS---------- -->
-   <a href="https://www.sparkfun.com/products/11375">
      <figure markdown>
        Hook-Up Wire - Assortment (Stranded, 22 AWG)
      </figure>
    </a>

    ---

    <a href="https://www.sparkfun.com/products/11375">
      <b>Hook-Up Wire - Assortment (Stranded, 22 AWG)</b>
      <br />
      PRT-11375
    </a>
<!-- ----------WHITE SPACE BETWEEN PRODUCTS---------- -->
-   <a href="https://www.sparkfun.com/products/24771">
      <figure markdown>
        Wire Strippers - 20-30 AWG
      </figure>
    </a>

    ---

    <a href="https://www.sparkfun.com/products/24771">
      <b>Wire Strippers - 20-30 AWG</b>
      <br />
      TOL-24771
    </a>
<!-- ----------WHITE SPACE BETWEEN PRODUCTS---------- -->
-   <a href="https://www.sparkfun.com/products/14782">
      <figure markdown>
        Flush Cutters - Xcelite
      </figure>
    </a>

    ---

    <a href="https://www.sparkfun.com/products/14782">
      <b>Flush Cutters - Xcelite</b>
      <br />
      TOL-14782
    </a>
<!-- ----------WHITE SPACE BETWEEN PRODUCTS---------- -->

-   <a href="https://www.sparkfun.com/products/19944">
      <figure markdown>
        Magnetic Third-Hand Kit
      </figure>
    </a>

    ---

    <a href="https://www.sparkfun.com/products/19944">
      <b>Magnetic Third-Hand Kit</b>
      <br />
      TOL-19944
    </a>
<!-- ----------WHITE SPACE BETWEEN PRODUCTS---------- -->

-   <a href="https://www.sparkfun.com/products/9200">
      <figure markdown>
        Hobby Knife
      </figure>
    </a>

    ---

    <a href="https://www.sparkfun.com/products/9200">
      <b>Hobby Knife</b>
      <br />
      TOL-09200
    </a>
<!-- ----------WHITE SPACE BETWEEN PRODUCTS---------- -->

-   <a href="https://www.sparkfun.com/products/12966">
      <figure markdown>
        Digital Multimeter - Basic
      </figure>
    </a>

    ---

    <a href="https://www.sparkfun.com/products/12966">
      <b>Digital Multimeter - Basic</b>
      <br />
      TOL-12966
    </a>
<!-- ----------WHITE SPACE BETWEEN PRODUCTS---------- -->

-   <a href="https://www.sparkfun.com/products/509">
      <figure markdown>
        Banana to Alligator Cable
      </figure>
    </a>

    ---

    <a href="https://www.sparkfun.com/products/509">
      <b>Banana to Alligator Cable</b>
      <br />
      CAB-00509
    </a>
<!-- ----------WHITE SPACE BETWEEN PRODUCTS---------- -->

-   <a href="https://www.sparkfun.com/products/24078">
      <figure markdown>
        Segger J-Link EDU Mini
      </figure>
    </a>

    ---

    <a href="https://www.sparkfun.com/products/24078">
      <b>Segger J-Link EDU Mini</b>
      <br />
      PGM-24078
    </a>
<!-- ----------WHITE SPACE BETWEEN PRODUCTS---------- -->
</div>

!!! note
    For advanced users, the [Acconeer's XM125 Software User Guide](../assets/component_documentation/XM125%20Software%20User%20Guide.pdf) recommends using a Segger J-Link debug probe. They list the J-Link BASE Compact or an ST-Link debugger. For users that are using the XM125 module for hobby or educational use, you can also use the Segger J-Link EDU Mini. The J-Link EDU Mini is a stripped-down, budget-friendly model of the J-Link debug probe created for educational use. Even with its reduced size, it maintains the J-Link features.

### Prototyping Accessories &nbsp;_(Optional)_

For users connecting to the PTHs, you will need the following prototyping accessories. You could use IC hooks for a temporary connection depending on your setup and what you have available. Of course, you will want to the solder header pins for a secure connection. Below are a few prototyping accessories that you may want to consider.

<!--
* [Breadboard - Self-Adhesive (White) [PRT-12002]](https://www.sparkfun.com/products/12002)
* [IC Hook with Pigtail [CAB-09741]](https://www.sparkfun.com/products/9741)
* [Break Away Headers - Straight [PRT-00116]](https://www.sparkfun.com/products/116)
* [Female Headers [PRT-00115]](https://www.sparkfun.com/products/115)
* [Jumper Wires Premium 6" M/M Pack of 10 [PRT-08431]](https://www.sparkfun.com/products/8431)
* [Jumper Wire Kit - 140pcs [PRT-00124](https://www.sparkfun.com/products/124)
-->

<div class="grid cards hide col-4" markdown>
<!-- ----------WHITE SPACE BETWEEN PRODUCTS---------- -->
-   <a href="https://www.sparkfun.com/products/12002">
      <figure markdown>
        Breadboard - Self-Adhesive (White)
      </figure>
    </a>

    ---

    <a href="https://www.sparkfun.com/products/12002">
      <b>Breadboard - Self-Adhesive (White)</b>
      <br />
      PRT-12002
    </a>
<!-- ----------WHITE SPACE BETWEEN PRODUCTS---------- -->
-   <a href="https://www.sparkfun.com/products/9741">
      <figure markdown>
        IC Hook with Pigtail
      </figure>
    </a>

    ---

    <a href="https://www.sparkfun.com/products/9741">
      <b>IC Hook with Pigtail</b>
      <br>
      CAB-09741
    </a>
<!-- ----------WHITE SPACE BETWEEN PRODUCTS---------- -->
-   <a href="https://www.sparkfun.com/products/116">
      <figure markdown>
        Break Away Headers - Straight
      </figure>
    </a>

    ---

    <a href="https://www.sparkfun.com/products/116">
      <b>Break Away Headers - Straight</b>
      <br />
      PRT-00116
    </a>
<!-- ----------WHITE SPACE BETWEEN PRODUCTS---------- -->
-   <a href="https://www.sparkfun.com/products/115">
      <figure markdown>
        Female Headers
      </figure>
    </a>

    ---

    <a href="https://www.sparkfun.com/products/115">
      <b>Female Headers</b>
      <br />
      PRT-00115
    </a>
<!-- ----------WHITE SPACE BETWEEN PRODUCTS---------- -->
-   <a href="https://www.sparkfun.com/products/22890">
      <figure markdown>
        Header - 2x5 Pin 1.27mm SMD Unshrouded (JTAG)
      </figure>
    </a>

    ---

    <a href="https://www.sparkfun.com/products/22890">
      <b>Header - 2x5 Pin 1.27mm SMD Unshrouded (JTAG)</b>
      <br />
      PRT-22890
    </a>
<!-- ----------WHITE SPACE BETWEEN PRODUCTS---------- -->
-   <a href="https://www.sparkfun.com/products/8431">
      <figure markdown>
        Jumper Wires Premium 6
      <br />
      PRT-08431
    </a>
<!-- ----------WHITE SPACE BETWEEN PRODUCTS---------- -->
-   <a href="https://www.sparkfun.com/products/124">
      <figure markdown>
        Jumper Wire Kit - 140pcs
      </figure>
    </a>

    ---

    <a href="https://www.sparkfun.com/products/124">
      <b>Jumper Wire Kit - 140pcs</b>
      <br />
      PRT-00124
    </a>
<!-- ----------WHITE SPACE BETWEEN PRODUCTS---------- -->
</div>

### Suggested Reading

If you aren't familiar with the Qwiic Connection System, we recommend reading [here for an overview](https://www.sparkfun.com/qwiic).

<div style="text-align: center">
  <table style="border-style:none">
    <tr>
     <td style="text-align: center; vertical-align: middle;">
     <div style="text-align: center"><a href="https://www.sparkfun.com/qwiic">Qwiic Connection System Click to learn more about the Qwiic Connection System!</a>
     </div>
    </td>
    </tr>
    <tr>
      <td style="text-align: center; vertical-align: middle;"><div style="text-align: center"><i><a href="https://www.sparkfun.com/qwiic">Qwiic Connection System</a></i></div></td>
    </tr>
  </table>
</div>

If you aren’t familiar with the following concepts, we also recommend checking out a few of these tutorials before continuing.

<div class="grid cards hide col-4" markdown>
<!-- ----------WHITE SPACE BETWEEN GRID CARDS---------- -->
-   <a href="https://learn.sparkfun.com/tutorials/i2c">
      <figure markdown>
        I2C
      </figure>
    </a>

    ---

    <a href="https://learn.sparkfun.com/tutorials/i2c">
      <b>I2C</b>
    </a>
<!-- ----------WHITE SPACE BETWEEN GRID CARDS---------- -->
-   <a href="https://learn.sparkfun.com/tutorials/how-to-work-with-jumper-pads-and-pcb-traces/introduction">
      <figure markdown>
        How to Work with Jumper Pads and PCB Traces
      </figure>
    </a>

    ---

    <a href="https://learn.sparkfun.com/tutorials/how-to-work-with-jumper-pads-and-pcb-traces/introduction">
      <b>How to Work with Jumper Pads and PCB Traces</b>
    </a>
<!-- ----------WHITE SPACE BETWEEN GRID CARDS---------- -->
-   <a href="https://learn.sparkfun.com/tutorials/how-to-solder-through-hole-soldering">
      <figure markdown>
        How to Solder: Through-Hole Soldering
      </figure>
    </a>

    ---

    <a href="https://learn.sparkfun.com/tutorials/how-to-solder-through-hole-soldering">
      <b>How to Solder: Through-Hole Soldering</b>
    </a>
<!-- ----------WHITE SPACE BETWEEN GRID CARDS---------- -->
-   <a href="https://learn.sparkfun.com/tutorials/installing-arduino-ide">
      <figure markdown>
        Installing Arduino IDE
      </figure>
    </a>

    ---

    <a href="https://learn.sparkfun.com/tutorials/installing-arduino-ide">
      <b>Installing Arduino IDE</b>
    </a>
<!-- ----------WHITE SPACE BETWEEN GRID CARDS---------- -->
-   <a href="https://learn.sparkfun.com/tutorials/installing-board-definitions-in-the-arduino-ide">
      <figure markdown>
        Installing Board Definitions in the Arduino IDE
      </figure>
    </a>

    ---

    <a href="https://learn.sparkfun.com/tutorials/installing-board-definitions-in-the-arduino-ide">
      <b>Installing Board Definitions in the Arduino IDE</b>
    </a>
<!-- ----------WHITE SPACE BETWEEN GRID CARDS---------- -->
-   <a href="https://learn.sparkfun.com/tutorials/iot-redboard-esp32-development-board-hookup-guide">
      <figure markdown>
        IoT RedBoard ESP32 Development Board Hookup Guide
      </figure>
    </a>

    ---

    <a href="https://learn.sparkfun.com/tutorials/iot-redboard-esp32-development-board-hookup-guide">
      <b>IoT RedBoard ESP32 Development Board Hookup Guide</b>
    </a>
<!-- ----------WHITE SPACE BETWEEN GRID CARDS---------- -->
</div>

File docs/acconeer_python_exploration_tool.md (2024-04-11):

Before you are able to use the Exploration Tool with the XM125, you will also need to flash the appropriate firmware (e.g. the **acc_exploration_server_a121.bin**). You can use the [instructions outlined earlier with the STM32CubeProgrammer](../flashing_firmware_xm125). You can also use Acconeer's Exploration Tool to flash firmware as well.

### Installing XM125 Firmware with the Exploration Tool

As explained earlier, each application requires a specific firmware to be flashed on the XM125. By default, the presence detection firmware (i.e. _i2c_presence_detector.bin_) is loaded on the SparkFun Pulsed Coherent Radar Sensor - Acconeer XM125 (Qwiic). For users that are interested in loading other firmware, we recommend heading over Acconeer's developer site to download the latest firmware. At the time of writing, this should be located under **Developer Tools & Support** > **A121 Docs & Software** > **XM125 / XE125** > **Acconeer XM125 A121 (SDK for XM125)**.

<div style="text-align: center"><a href="https://developer.acconeer.com/home/a121-docs-software/xm125-xe125/" class="md-button">Download the XM125 Firmware!</a></div>

!!! note
    You will need an account to download the firmware.  Make sure to register for an account and sign in to download the XM125 firmware.

### Flashing Firmware

Open the Acconeer Exploration Tool. You'll be presented with two options. For the scope of this tutorial, you will select the **A121**.

<div style="text-align: center;">
  <table>
    <tr style="vertical-align:middle;">
     <td style="text-align: center; vertical-align: middle; border: solid 1px #cccccc;"><a href="../assets/img/Python_Exploration_Tool_Select_A121.JPG">Select A121 on the Acconeer Exploration Tool</a></td>
    </tr>
  </table>
</div>

Connect a USB between the SparkFun Pulsed Coherent Radar Sensor - Acconeer XM125 (Qwiic) and your computer.

<div style="text-align: center;">
  <table>
    <tr style="vertical-align:middle;">
     <td style="text-align: center; vertical-align: middle; border: solid 1px #cccccc;"><a href="../assets/img/SEN-24540-Pulsed_Coherent_Radar_Acconeer_XM125_A121_USB_Cable.jpg">USB Cable Inserted into Pulsed Coherent Radar Sensor</a></td>
    </tr>
  </table>
</div>

Select the **Flash** tab from the side navigation bar.  

<div style="text-align: center;">
  <table>
    <tr style="vertical-align:middle;">
     <td style="text-align: center; vertical-align: middle; border: solid 1px #cccccc;"><a href="../assets/img/Acconeer_Exploration_Tool_Flash_Firmware_Tab.JPG">Flash Firmware Tab</a></td>
    </tr>
  </table>
</div>

Select the firmware to flash to the SparkFun Pulsed Coherent Radar Sensor - Acconeer XM125 by clicking on the **Browse** button. In this case, you will need to head to: .. > **acconeer_xm125_a121-v1_5_0** > **xm125** > **out**. The version number will change depending on when you downloaded the firmware. Select **acc_exploration_server_a121.bin**.

<div style="text-align: center;">
  <table>
    <tr style="vertical-align:middle;">
     <td style="text-align: center; vertical-align: middle; border: solid 1px #cccccc;"><a href="../assets/img/Select_XM125_Firmware_acc_exploration_server_a121.JPG">Select Acconeer Exploration Server A121 Firmware</a></td>
    </tr>
  </table>
</div>

Select **Serial**. Then select the COM port that the SparkFun Pulsed Coherent Radar Sensor - Acconeer XM125 enumerated to. In this case it was **COM22 ()**. The COM port with the parenthesis will most likely be the COM port. From the drop down menu, select **XM125**.

<div style="text-align: center;">
  <table>
    <tr style="vertical-align:middle;">
     <td style="text-align: center; vertical-align: middle; border: solid 1px #cccccc;"><a href="../assets/img/Flash_XM125_Firmware_acc_exploration_server_a121_Python_Exploration_Tool.JPG">Flash Acconeer Exploration Server A121 Firmware</a></td>
    </tr>
  </table>
</div>

You will need to set the XM125 in bootloader mode.

- Press and hold the BOOT button.
- Press the RST button while still holding down the BOOT button.
- Release the RST button.
- After a short moment, release the BOOT button.

<div style="text-align: center;">
  <table>
    <tr style="vertical-align:middle;">
     <td style="text-align: center; vertical-align: middle; border: solid 1px #cccccc;"><a href="../assets/img/SEN-24540-Pulsed_Coherent_Radar_Acconeer_XM125_A121_Boot_Mode-1.jpg">Press and hold BOOT Button</a></td>
     <td style="text-align: center; vertical-align: middle; border: solid 1px #cccccc;"><a href="../assets/img/SEN-24540-Pulsed_Coherent_Radar_Acconeer_XM125_A121_Boot_Mode-2.jpg">Press Reset Button</a></td>
     <td style="text-align: center; vertical-align: middle; border: solid 1px #cccccc;"><a href="../assets/img/SEN-24540-Pulsed_Coherent_Radar_Acconeer_XM125_A121_Boot_Mode-1.jpg">Keep Holding Down BOOT Button</a></td>
     <td style="text-align: center; vertical-align: middle; border: solid 1px #cccccc;"><a href="../assets/img/SEN-24540-Pulsed_Coherent_Radar_Acconeer_XM125_A121_Boot_Mode-3.jpg">After a Short Moment, Release Boot Button</a></td>
   </tr>
  </table>
</div>

!!! note
    You will want to wait a short moment before releasing the BOOT button to give the XM125 a moment to recognize that the BOOT button is being held low. Releasing the RST button too fast after the XM125 resets may prevent the module from properly entering bootloader mode.

Click the **Flash** button to flash the firmware. After a few seconds, you should get a message: "Flashing done!"

<div style="text-align: center;">
  <table>
    <tr style="vertical-align:middle;">
     <td style="text-align: center; vertical-align: middle; border: solid 1px #cccccc;"><a href="../assets/img/Flash_XM125_Firmware_acc_exploration_server_a121_Python_Exploration_Tool_Done.JPG">Flashed Acconeer Exploration Server A121 Firmware</a></td>
    </tr>
  </table>
</div>

### Getting Started with the Exploration Tool

Click on **Stream** from the side navigation bar. Select **Serial**. Then select the COM port that the board enumerated to. In this case, it was **COM22 ()** just like when the board was flashed earlier with the Exploration Tool.

<div style="text-align: center;">
  <table>
    <tr style="vertical-align:middle;">
     <td style="text-align: center; vertical-align: middle; border: solid 1px #cccccc;"><a href="../assets/img/Acconeer_Exploratoin_Tool_A121_Connect_XM125_SparkFun.JPG">Connect to COM Port on the Acconeer Exploration Tool</a></td>
    </tr>
  </table>
</div>

Configure the COM port by clicking on the gear between the COM port and Connect button. A small window will pop up to configure the COM port. Make sure to deselect the **Auto-connect** and manually enter the baud rate: **115200**. You may get an error when starting a measurements. Close the window by clicking the **X** button. Then click the **Connect** button.

<div style="text-align: center;">
  <table>
    <tr style="vertical-align:middle;">
     <td style="text-align: center; vertical-align: middle; border: solid 1px #cccccc;"><a href="../assets/img/Acconeer_Exploration_Tool_XM125_Baud_Rate.JPG">Configure COM Port on the Acconeer Exploration Tool</a></td>
    </tr>
  </table>
</div>

There are several demos available with the Acconeer Exploration Tool. Let&apos;s check out the presence detector example. Click on the **Presence detector** button. Then click on the **Start Measurement** button. Try placing your hand over the sensor and then moving it away

<div style="text-align: center;">
  <table>
    <tr style="vertical-align:middle;">
     <td style="text-align: center; vertical-align: middle; border: solid 1px #cccccc;"><a href="../assets/img/SEN-24540-Pulsed_Coherent_Radar_Acconeer_XM125_A121_Hand_Near.jpg">Hand in front of XM125 and Close</a></td>
     <td style="text-align: center; vertical-align: middle; border: solid 1px #cccccc;"><a href="../assets/img/SEN-24540-Pulsed_Coherent_Radar_Acconeer_XM125_A121_Hand_Farther_Away.jpg">Hand in front of XM125 and Farther Away</a></td>
    </tr>
  </table>
</div>

You should see the presence distance values increase in the plot. From the history, I had moved my hand quickly away from the sensor resulting in the intra-presence score to increase. Then I moved it back and slowly moved it away resulting in the inter-presence score to increase. The  presence distance values would also be displayed in the bottom plot.

<div style="text-align: center;">
  <table>
    <tr style="vertical-align:middle;">
     <td style="text-align: center; vertical-align: middle; border: solid 1px #cccccc;"><a href="../assets/img/SparkFun_Acconeer_XM125_Exploration_Tool_Presense_Detector_Output.png">Output from XM125 with Presence Detector Example on Acconeer Exploration Tool</a></td>
    </tr>
  </table>
</div>

Let&apos;s check out the distance detector example. Click on the **Distance detector** button. Then click on the **Start Measurement** button. Placing my hand over the sensor and then moving it away, you should see the distance values increase in the plot. This was indicated by the four orange dots on the bottom graph.

<div style="text-align: center;">
  <table>
    <tr style="vertical-align:middle;">
     <td style="text-align: center; vertical-align: middle; border: solid 1px #cccccc;"><a href="../assets/img/SparkFun_Acconeer_XM125_Exploration_Tool_Distance_Detector_Output.png">Output from XM125 with Distance Detector Example on Acconeer Exploration Tool</a></td>
    </tr>
  </table>
</div>

Try checking out Acconeer's documentation for the Exploration tool and adjusting each value for your application. Or even place the sensor behind a wooden door or glass window to see if the sensor can detect your presence or distance from the sensor. There are also applications to measure breathing rate, detect parked cars, adjust the range of the presence detection into zones, measure tank levels, and measure speed!

<div style="text-align: center"><a href="https://docs.acconeer.com/en/latest/exploration_tool/algo/a121/index.html" class="md-button">Click Here to Browse Acconeer's Documentation for the Exploration Tool</a></div>

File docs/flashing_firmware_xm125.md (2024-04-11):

The XM125 uses different firmware for different applications. You will need to program the XM125 when using presence detection or distance detection. For users using the Arduino examples for presence detection, you can skip this section. Otherwise, follow the steps to flash the firmware for the distance detection or for those that are re-flashing the presence detection firmware.

### Downloading Firmware

!!! note
    Arduino examples 1-5 with the default firmware (i.e. _i2c_presence_detector.bin_) that is loaded on the SparkFun Pulsed Coherent Radar Sensor - Acconeer XM125 (Qwiic). For Arduino examples 6-9, you will need to load the distance detection firmware (i.e. _i2c_distance_detector.bin_)

Each application requires a specific firmware to be flashed on the XM125. By default, the presence detection firmware (i.e. _i2c_presence_detector.bin_) is loaded on the SparkFun Pulsed Coherent Radar Sensor - Acconeer XM125 (Qwiic). For users that are interested in loading other firmware, we recommend heading over Acconeer's developer site to download the latest firmware. At the time of writing, this should be located under **Developer Tools & Support** > **A121 Docs & Software** > **XM125 / XE125** > **Acconeer XM125 A121 (SDK for XM125)**.

<div style="text-align: center"><a href="https://developer.acconeer.com/home/a121-docs-software/xm125-xe125/" class="md-button">Download the XM125 Firmware!</a></div>

!!! note
    You will need an account to download the firmware.  Make sure to register for an account and sign in to download the XM125 firmware.

### Flashing Firmware

Open the STM32CubeProgrammer software.

<div style="text-align: center;">
  <table>
    <tr style="vertical-align:middle;">
     <td style="text-align: center; vertical-align: middle;"><a href="../assets/img/Open_STM32CubeProgrammer.JPG">screenshot SFM32CubeProgrammer</a></td>
    </tr>
  </table>
</div>

Connect a USB between the SparkFun Pulsed Coherent Radar Sensor - Acconeer XM125 (Qwiic) and your computer.

<div style="text-align: center;">
  <table>
    <tr style="vertical-align:middle;">
     <td style="text-align: center; vertical-align: middle;"><a href="../assets/img/SEN-24540-Pulsed_Coherent_Radar_Acconeer_XM125_A121_USB_Cable.jpg">USB Cable Inserted into Pulsed Coherent Radar Sensor</a></td>
    </tr>
  </table>
</div>

You will need to set the XM125 in bootloader mode.

- Press and hold the BOOT button.
- Press the RST button while still holding down the BOOT button.
- Release the RST button.
- After a short moment, release the BOOT button.

<div style="text-align: center;">
  <table>
    <tr style="vertical-align:middle;">
     <td style="text-align: center; vertical-align: middle; border: solid 1px #cccccc;><a href="../assets/img/SEN-24540-Pulsed_Coherent_Radar_Acconeer_XM125_A121_Boot_Mode-1.jpg">Press and hold BOOT Button</a></td>
     <td style="text-align: center; vertical-align: middle; border: solid 1px #cccccc;><a href="../assets/img/SEN-24540-Pulsed_Coherent_Radar_Acconeer_XM125_A121_Boot_Mode-2.jpg">Press Reset Button</a></td>
     <td style="text-align: center; vertical-align: middle; border: solid 1px #cccccc;><a href="../assets/img/SEN-24540-Pulsed_Coherent_Radar_Acconeer_XM125_A121_Boot_Mode-1.jpg">Keep Holding Down BOOT Button</a></td>
     <td style="text-align: center; vertical-align: middle; border: solid 1px #cccccc;><a href="../assets/img/SEN-24540-Pulsed_Coherent_Radar_Acconeer_XM125_A121_Boot_Mode-3.jpg">After a Short Moment, Release Boot Button</a></td>
   </tr>
  </table>
</div>

!!! note
    You will want to wait a short moment before releasing the BOOT button to give the XM125 a moment to recognize that the BOOT button is being held low. Releasing the RST button too fast after the XM125 resets may prevent the module from properly entering bootloader mode.

Select the COM port that the board enumerated to. In this case, it was COM10. The default UART configuration should already be set to the following:

    - 115200 baud
    - even parity
    - 8 data bits
    - 1 stop bit
    - no flow control

When ready, hit the **Connect** button.

<div style="text-align: center;">
  <table>
    <tr style="vertical-align:middle;">
     <td style="text-align: center; vertical-align: middle;"><a href="../assets/img/STM32CubeProgrammer_Connected.JPG">screenshot STM32CubeProgrammer Connected to board</a></td>
    </tr>
  </table>
</div>

Click the **Download** button (the second button on the left navigation bar). Then click on the **Browse** button to select the firmware that you would like to flash to the board.

<div style="text-align: center;">
  <table>
    <tr style="vertical-align:middle;">
     <td style="text-align: center; vertical-align: middle;"><a href="../assets/img/STM-32CubeProgrammer_Download_Button.JPG">screenshot STM32CubeProgrammer Download Tab</a></td>
    </tr>
  </table>
</div>

Since the firmware for the presence detection is already flashed to the board, we will flash the firmware for the distance detection (i.e. **i2c_distance_detector.bin**). Head to the folder where you downloaded and unzipped the firmware. In this case, you will need to head to: .. > **acconeer_xm125_a121-v1_5_0** > **xm125** > **out**. The version number will change depending on when you downloaded the firmware. Select **i2c_distance_detector.bin**.

<div style="text-align: center;">
  <table>
    <tr style="vertical-align:middle;">
     <td style="text-align: center; vertical-align: middle;"><a href="../assets/img/Select_XM125_Firmware.JPG">screenshot file selected</a></td>
    </tr>
  </table>
</div>

Enter the start address **0x8000000** to flash the firmware. Click on the **Start Programming** button to begin flashing the firmware. Once flashed, you should an output after a few seconds: "File Download Complete" with the progress bar filled to 100%.

<div style="text-align: center;">
  <table>
    <tr style="vertical-align:middle;">
     <td style="text-align: center; vertical-align: middle;"><a href="../assets/img/STM32CubeProgrammer_Flashed_Binary_SparkFun_Acconeer_XM125.JPG">screenshot successfully uploaded</a></td>
    </tr>
  </table>
</div>

!!! note
    Using the STM125CubeProgrammer is only one way to flash firmware to the XM125 using! You can also use the Acconeer Python Exploration Tool as well. For more information, check out the section on [Flashing Firmware with the Acconeer Exploration Tool](..\acconeer_python_exploration_tool\#flashing-firmware).

    <div style="text-align: center"><a href="..\acconeer_python_exploration_tool\#flashing-firmware" class="md-button">Flashing Firmware using the Acconeer Exploration Tool</a></div>

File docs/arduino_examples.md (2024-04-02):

Now that we have our library and board add-on installed, we can get start experimenting with the breakout board. For the scope of this tutorial, we will highlight one of the examples to get started. From there we will be able to build our own custom code to integrate the development board into a project.

## I<sup>2</sup>C Presence Detection Arduino Examples

The following examples will go over the presence detection examples over I<sup>2</sup>C . By default, the firmware for the I<sup>2</sup>C  presence detection will be loaded on the SparkFun Pulsed Coherent Radar Sensor. If you decide you uploaded a different firmware to the XM125 and decide to use the Presence Detection Arduino Examples, make sure to follow the [steps to reflash the **i2c_presence_detector.bin** back on the module](../flashing_firmware_xm125).

For more information about the Presence Detector over I<sup>2</sup>C, we recommend referring to Acconeer's documentation and the User Guide.

<div style="text-align: center"><a href="../assets/component_documentation/I2C%20Presence%20Detector%20User%20Guide.pdf" class="md-button">I2C Presence Detector User Guide</a></div>

### Example 1: Presence Basic Readings

This example reads the output from the XM125 when the presence sensing firmware is loaded to the module. Once the sensor is initialized, the example outputs the presence distance values (in millimeters) to a Serial Terminal. Head to the examples in the folder (located in **File** > **Examples** > **SparkFun XM125 Arduino Library** > **Example01PresenceBasicReadings**).

If you have not already, select your Board (in this case the **SparkFun ESP32 IoT RedBoard**), and associated COM port. Upload the code to the board and set the [Arduino Serial Monitor](https://learn.sparkfun.com/tutorials/terminal-basics/all#arduino-serial-monitor-windows-mac-linux) to **115200** baud.

You should see an output similar to the image below. When presence is detected, the sensor will provide presnce distance values in millimeters.

<div style="text-align: center;">
  <table>
    <tr style="vertical-align:middle;">
     <td style="text-align: center; vertical-align: middle; border: solid 1px #cccccc;"><a href="../assets/img/Arduino_Ex1_Output_Presence_Basic_Readings.JPG">Arduino Example 1 Output</a></td>
    </tr>
  </table>
</div>

In this case, I placed my hand in front of the sensor and moved it away.

<div style="text-align: center;">
  <table>
    <tr style="vertical-align:middle;">
     <td style="text-align: center; vertical-align: middle; border: solid 1px #cccccc;"><a href="../assets/img/SEN-24540-Pulsed_Coherent_Radar_Acconeer_XM125_A121_Hand_Near.jpg">Hand in front of XM125 and Close</a></td>
     <td style="text-align: center; vertical-align: middle; border: solid 1px #cccccc;"><a href="../assets/img/SEN-24540-Pulsed_Coherent_Radar_Acconeer_XM125_A121_Hand_Farther_Away.jpg">Hand in front of XM125 and Farther Away</a></td>
    </tr>
  </table>
</div>

Try placing something like a piece of cardboard in front of the sensor to see if the XM125 can still detect your presence. Or aim the sensor facing down toward a table and wave your arm or leg under the table to see if it can sense your movement. [Some materials are semi-transparent to 60GHz signals](https://docs.acconeer.com/en/latest/handbook/radar_principles.html#). Thus, it is possible to [detect reflecting objects behind a material such as an enclosure](https://docs.acconeer.com/en/latest/handbook/physical_integration.html), or sensing other objects behind walls or clothing!

<div style="text-align: center;">
  <table>
    <tr style="vertical-align:middle;">
     <td style="text-align: center; vertical-align: middle; border: solid 1px #cccccc;"><a href="../assets/img/SEN-24540-Pulsed_Coherent_Radar_Acconeer_XM125_A121_Sensing_Hand_Through_Glass-edit.jpg">Glass between the XM125 and a Hand</a></td>
    </tr>
  </table>
</div>

!!! note
    The XM125 is set to a minimum range of 30mm. You can adjust the range in Example 5: Presence Advanced Settings.

### Example 2: Presence GPIO0 Usage

This example reads the output from the XM125 when the presence sensing firmware is loaded to the module. Once the sensor is initialized, the example outputs the presence distance values (in millimeters) to a Serial Terminal similar to the first example. However, the SparkFun Pulsed Coherent Radar Sensor's GPIO0 will also be set HIGH whenever there is a presence detected. Head to the examples in the folder (located in **File** > **Examples** > **SparkFun XM125 Arduino Library** > **Example02_PresenceGPIO0Usage**).

If you have not already, select your Board (in this case the **SparkFun ESP32 IoT RedBoard**), and associated COM port. Upload the code to the board and set the [Arduino Serial Monitor](https://learn.sparkfun.com/tutorials/terminal-basics/all#arduino-serial-monitor-windows-mac-linux) to **115200** baud.

You should see an output similar to the image below. In this case, I placed my hand in front of the sensor and moved it away just like the previous example. However, GPIO0 will also be set HIGH whenever a presence is detected.

<div style="text-align: center;">
  <table>
    <tr style="vertical-align:middle;">
     <td style="text-align: center; vertical-align: middle; border: solid 1px #cccccc;"><a href="../assets/img/Arduino_Ex2_Output_Presence_GPIO0_Usage.JPG">Output Example 2</a></td>
    </tr>
  </table>
</div>

Try using IC hooks or soldering to the PTHs to connect to GPIO0 and GND. Then use a multimeter to measure the pin whenever a pin is HIGH. You should see a voltage of about 3.3V whenever the pin is HIGH and 0V whenever the pin is LOW.

<div style="text-align: center;">
  <table>
    <tr style="vertical-align:middle;">
     <td style="text-align: center; vertical-align: middle;"><a href="../assets/img/SEN-24540-Pulsed_Coherent_Radar_Acconeer_XM125_A121_Arduino_IoT_RedBoard_ESP32_Qwiic_GPIO0_Hand_Detected.jpg">Multimeter Connected to GPIO0 and GND measuring about 3.3V indicating that the presence of my hand is detected</a></td>
    </tr>
  </table>
</div>

!!! note
    It is recommended to have a low profile when connecting to the GPIO SparkFun Pulsed Coherent Radar Sensor to limit the amount of reflections. For users connecting IC hooks, we recommend placing them flush with the board or hooking them from the bottom side. For users soldering to the board, make sure that there are no wires protruding in front of the sensor.

### Example 3: Presence Serial Plotter

This example reads the output from the XM125 when the presence sensing firmware is loaded to the module. Once the sensor is initialized, the example outputs the presence distance values (in millimeters) to a Serial Terminal similar to the first example. However, only the values are printed for each line. This makes it easier for the Arduino Serial Plotter to graph the values. Head to the examples in the folder (located in **File** > **Examples** > **SparkFun XM125 Arduino Library** > **Example03_PresenceSerialPlotter**).

If you have not already, select your Board (in this case the **SparkFun ESP32 IoT RedBoard**), and associated COM port. Upload the code to the board. Then open the [Arduino Serial Monitor](https://learn.sparkfun.com/tutorials/terminal-basics/all#arduino-serial-monitor-windows-mac-linux) at **115200** baud, you should see only the values printed. When opening the Arduino Serial Plotter at **115200** baud, you should see the values plotted in the window.

You should see an output similar to the images below. In this case, I placed my hand in front of the sensor and moved it away just like the previous examples.

<div style="text-align: center;">
  <table>
    <tr style="vertical-align:middle;">
     <td style="text-align: center; vertical-align: middle; border: solid 1px #cccccc;"><a href="../assets/img/Arduino_Ex3_Output_Presence_Serial_Plotter_Values.jpg">Output Example 3 through Serial Monitor</a></td>
     <td style="text-align: center; vertical-align: middle; border: solid 1px #cccccc;"><a href="../assets/img/Arduino_Ex3_Output_Presence_Serial_Plotter.JPG">Output Example 3 through Serial Plotter</a></td>
    </tr>
  </table>
</div>

### Example 4: Presence Advanced Readings

This example reads the output from the XM125 when the presence sensing firmware is loaded to the module. Once the sensor is initialized, the example outputs the presence distance values (in millimeters) to a Serial Terminal similar to the first example. However, you will also get the intra-presence score and the inter-presence score. The intra-presence score measures the amount of fast motion detected. The inter-presence score measures the amount of slow motion detected. Head to the examples in the folder (located in **File** > **Examples** > **SparkFun XM125 Arduino Library** > **Example04_PresenceAdvancedReadings**).

If you have not already, select your Board (in this case the **SparkFun ESP32 IoT RedBoard**), and associated COM port. Upload the code to the board. Then open the [Arduino Serial Monitor](https://learn.sparkfun.com/tutorials/terminal-basics/all#arduino-serial-monitor-windows-mac-linux) at **115200** baud.

You should see an output similar to the image below. You should see the three different values printed. In this case, I placed my hand in front of the sensor and moved it quickly away from the sensor. Notice that the intra-presence score was higher than the inter-presence score since my hand was moving quickly away from the sensor.

<div style="text-align: center;">
  <table>
    <tr style="vertical-align:middle;">
     <td style="text-align: center; vertical-align: middle; border: solid 1px #cccccc;"><a href="../assets/img/Arduino_Ex4_Output_Presence_Advanced_Readings_Intra-Presence_Fast_Motion.jpg">Output Example 4 with Intra-Presence Score High</a></td>
    </tr>
  </table>
</div>

Moving my hand back in front of the sensor, let's try moving it slowly away from the sensor. You should see an output similar to the image below. Notice that the inter-presence score was higher this time since my hand was moving slowly away.

<div style="text-align: center;">
  <table>
    <tr style="vertical-align:middle;">
     <td style="text-align: center; vertical-align: middle; border: solid 1px #cccccc;""><a href="../assets/img/Arduino_Ex4_Output_Presence_Advanced_Readings_Inter-Presence_Slow_Motion.jpg">Output Example 4 with Inter-Presence Score High</a></td>
    </tr>
  </table>
</div>

### Example 5: Presence Advanced Settings

This example reads the output from the XM125 when the presence sensing firmware is loaded to the module. Once the sensor is initialized, the example outputs the presence distance values (in millimeters) to a Serial Terminal similar to the first example. However, the range for presence sensing can be adjusted in this example. Head to the examples in the folder (located in **File** > **Examples** > **SparkFun XM125 Arduino Library** > **Example05_PresenceAdvancedSettings**).

If you have not already, select your Board (in this case the **SparkFun ESP32 IoT RedBoard**), and associated COM port. Upload the code to the board. Then open the [Arduino Serial Monitor](https://learn.sparkfun.com/tutorials/terminal-basics/all#arduino-serial-monitor-windows-mac-linux) at **115200** baud.

You should see an output similar to the image below. To test the presence detection over a longer range, I had a friend stand in front of the sensor before moving away. The difference between this and the first example is the ability to configure the ranges for the minimum and maximum presence distance, respectively `beginReading` and `endReading`. By default, the "start" presence distance range is set to **300mm** while the "end" presence distance range is set to **2500mm**. This example sets the range between `300` mm and `7000` mm.

<div style="text-align: center;">
  <table>
    <tr style="vertical-align:middle;">
     <td style="text-align: center; vertical-align: middle; border: solid 1px #cccccc;"><a href="../assets/img/Arduino_Ex5_Output_Presence_Advanced_Settings_300mm_7000mm.jpg">Output Example 5</a></td>
    </tr>
  </table>
</div>

Try adjusting the values `beginReading` and `endReading`. After uploading, try moving outside of the range. You will notice that the values change to a certain value when a presence is not detected.

!!! note
    The A121 sensor on the XM125 is advertised as measuring up to 20 meters. The actual measurable distance is dependent on the object size, shape, dielectric properties, and lens (e.g. water level measurements up to 20 meters with lens utilization, human presence detection up to 7 meters with lens-free utilization).

## I<sup>2</sup>C  Distance Detection Arduino Examples

The following examples will go over the distance detection examples over I<sup>2</sup>C . The firmware for the I<sup>2</sup>C  distance detection is not loaded on the SparkFun Pulsed Coherent Radar Sensor. Make sure to follow the steps to flash the **i2c_distance_detector.bin** before proceeding to Arduino Example 6-9.

<div style="text-align: center"><a href="../flashing_firmware_xm125" class="md-button">Install the XM125 Firmware!</a></div>

For more information about the  Distance Detector over I<sup>2</sup>C, we recommend referring to Acconeer's documentation and the User Guide.

<div style="text-align: center"><a href="../assets/component_documentation/I2C%20Distance%20Detector%20User%20Guide.pdf" class="md-button">I2C Distance Detector User Guide</a></div>

### Example 6: Distance Basic Readings

This example reads the output from the XM125 when the distance sensing firmware is loaded to the module. Once the sensor is initialized, the example outputs the distance values (in millimeters) and their estimated reflective strengths to a Serial Terminal. Head to the examples in the folder (located in **File** > **Examples** > **SparkFun XM125 Arduino Library** > **Example06_DistanceBasicReadings**).

If you have not already, select your Board (in this case the **SparkFun ESP32 IoT RedBoard**), and associated COM port. Upload the code to the board. Then open the [Arduino Serial Monitor](https://learn.sparkfun.com/tutorials/terminal-basics/all#arduino-serial-monitor-windows-mac-linux) at **115200** baud.

You should see an output similar to the image below. Similar to the presence examples, the following outputs the distance and strength of an object that is detected within the peaks. Again, a hand was placed close to the sensor before moving away from the XM125.

<div style="text-align: center;">
  <table>
    <tr style="vertical-align:middle;">
     <td style="text-align: center; vertical-align: middle; border: solid 1px #cccccc;"><a href="../assets/img/Arduino_Ex6_Output_Distance_Basic_Readings.jpg">Output Example 6</a></td>
    </tr>
  </table>
</div>

### Example 7: Distance Threshold Settings

This example reads the output from the XM125 when the distance sensing firmware is loaded to the module. Once the sensor is initialized, the example outputs the distance values (in millimeters) and their estimated reflective strengths to a Serial Terminal similar to example 6. The example goes further by setting the XM125's distance amplitude, strength, fixed amplitude, and sensitivity thresholds. Head to the examples in the folder (located in **File** > **Examples** > **SparkFun XM125 Arduino Library** > **Example07_DistanceThresholdSettings**).

If you have not already, select your Board (in this case the **SparkFun ESP32 IoT RedBoard**), and associated COM port. Upload the code to the board. Then open the [Arduino Serial Monitor](https://learn.sparkfun.com/tutorials/terminal-basics/all#arduino-serial-monitor-windows-mac-linux) at **115200** baud.

You should see an output similar to the image below. The output will be similar to the example 6.

<div style="text-align: center;">
  <table>
    <tr style="vertical-align:middle;">
     <td style="text-align: center; vertical-align: middle; border: solid 1px #cccccc;"><a href="../assets/img/Arduino_Ex7_Output_Distance_Threshold_Settings.jpg">Output Example 7</a></td>
    </tr>
  </table>
</div>

### Example 8: Distance Serial Plotter

This example reads the output from the XM125 when the distance sensing firmware is loaded to the module. Once the sensor is initialized, the example outputs the distance values (in millimeters) from peak 0 and peak 1 onto the Arduino Serial Plotter. Head to the examples in the folder (located in **File** > **Examples** > **SparkFun XM125 Arduino Library** > **Example08_DistanceSerialPlotter**).

If you have not already, select your Board (in this case the **SparkFun ESP32 IoT RedBoard**), and associated COM port. Upload the code to the board. Then open the [Arduino Serial Monitor](https://learn.sparkfun.com/tutorials/terminal-basics/all#arduino-serial-monitor-windows-mac-linux) at **115200** baud.

You should see an output similar to the image below. In this case, the XM125 detected a mesh chair with a coat.

<div style="text-align: center;">
  <table>
    <tr style="vertical-align:middle;">
     <td style="text-align: center; vertical-align: middle; border: solid 1px #cccccc;"><a href="../assets/img/Arduino_Ex8_Output_Distance_Serial_Plotter_Chair-1.jpg">Output Example 8 through Serial Monitor</a></td>
     <td style="text-align: center; vertical-align: middle; border: solid 1px #cccccc;"><a href="../assets/img/Arduino_Ex8_Output_Distance_Serial_Plotter_Chair-2.jpg">Output Example 8 through Serial Plotter</a></td>
    </tr>
  </table>
</div>

Walking behind the chair, the XM125 was able to detect both the chair and when I was standing behind it.

<div style="text-align: center;">
  <table>
    <tr style="vertical-align:middle;">
     <td style="text-align: center; vertical-align: middle; border: solid 1px #cccccc;"><a href="../assets/img/Arduino_Ex8_Output_Distance_Serial_Plotter_Chair_Person-1.jpg">Output Example 8 through Serial Monitor with Sensor Detecting Chair and Person</a></td>
     <td style="text-align: center; vertical-align: middle; border: solid 1px #cccccc;"><a href="../assets/img/Arduino_Ex8_Output_Distance_Serial_Plotter_Chair_Person-2.jpg">Output Example 8 through Serial Plotter with Sensor Detecting Chair and Person</a></td>
    </tr>
  </table>
</div>

!!! note
    For those that are interested in viewing more than `distancePeak0` and `distancePeak1`, you will need to create the distance variables, read the PeakX distance, and add a `Serial.print();` for each distance variable similar to Arduino example 6. Make sure to also add a comma between each distance value so that the comma separated value (CSV) can be graphed on the Arduino Serial Plotter. Make sure to also have the last distance value printed as `Serial.println();`

### Example 9: Distance Advanced Settings

This example reads the output from the XM125 when the distance sensing firmware is loaded to the module. Once the sensor is initialized, the example outputs the distance values (in millimeters) and their estimated reflective strengths to a Serial Terminal similar to example 6. However, the range for distance sensing can be adjusted in this example. Head to the examples in the folder (located in **File** > **Examples** > **SparkFun XM125 Arduino Library** > **Example09_DistanceAdvancedSettings**).

If you have not already, select your Board (in this case the **SparkFun ESP32 IoT RedBoard**), and associated COM port. Upload the code to the board. Then open the [Arduino Serial Monitor](https://learn.sparkfun.com/tutorials/terminal-basics/all#arduino-serial-monitor-windows-mac-linux) at **115200** baud.

You should see an output similar to the image below. The difference between this and the example 6 is the ability to configure the ranges for the minimum and maximum distance, respectively `beginReading` and `endReading`. This is similar to example 5, but for the distance detection firmware. By default, the "start" distance range is set to **300mm** while the "end" distance range is set to **2500mm**. This example sets the range between `300` mm and `7000` mm.

<div style="text-align: center;">
  <table>
    <tr style="vertical-align:middle;">
     <td style="text-align: center; vertical-align: middle; border: solid 1px #cccccc;"><a href="../assets/img/Arduino_Ex9_Output_Distance_Advanced_Settings.jpg">Output Example 9</a></td>
    </tr>
  </table>
</div>

!!! note
    The A121 sensor on the XM125 is advertised as measuring up to 20 meters. The actual measurable distance is dependent on the object size, shape, dielectric properties, and lens (e.g. water level measurements up to 20 meters with lens utilization, human presence detection up to 7 meters with lens-free utilization).

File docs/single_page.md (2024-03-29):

---
hide:
  - navigation
  - toc
icon: fontawesome/solid/scroll
---

# Introduction
--8<-- "./docs/introduction.md"

# Hardware Overview
--8<-- "./docs/hardware_overview.md"

# Hardware Hookup
--8<-- "./docs/hardware_hookup.md"

# Installing the Arduino Library
--8<-- "./docs/arduino_library.md"

# Installing the STM32CubeProgrammer
--8<-- "./docs/installing_stm32cubeprogrammer.md"

# Flashing Firmware to the XM125
--8<-- "./docs/flashing_firmware_xm125.md"

# Arduino Examples
--8<-- "./docs/arduino_examples.md"

# Installing the Acconeer Python Exploration Tool
--8<-- "./docs/installing_acconeer_python_exploration_tool.md"

# Getting Started with the Acconeer Python Exploration Tool
--8<-- "./docs/acconeer_python_exploration_tool.md"

# Troubleshooting
--8<-- "./docs/troubleshooting.md"

# Resources
--8<-- "./docs/resources.md"

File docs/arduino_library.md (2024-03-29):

!!! arduino
    This example assumes you are using the latest version of the Arduino IDE on your desktop. If this is your first time using the Arduino IDE, library, or board add-on, please review the following tutorials.

    - [Installing the Arduino IDE](https://learn.sparkfun.com/tutorials/installing-arduino-ide)
    - [Installing Board Definitions in the Arduino IDE](https://learn.sparkfun.com/tutorials/installing-board-definitions-in-the-arduino-ide)
    - [Installing an Arduino Library](https://learn.sparkfun.com/tutorials/installing-an-arduino-library)

!!! note
    If you've never connected an CH340 device to your computer before, you may need to install drivers for the USB-to-serial converter. Check out our section on "[How to Install CH340 Drivers](https://learn.sparkfun.com/tutorials/how-to-install-ch340-drivers)" for help with the installation.

    - [How to Install CH340 Drivers](https://learn.sparkfun.com/tutorials/how-to-install-ch340-drivers/all)

SparkFun has written a library to work with the Acconeer XM125. You can obtain this library through the Arduino Library Manager by searching for "**SparkFun XM125**". Find the one written by SparkFun Electronics and install the latest version. Users who prefer to manually install the library can get it from the [GitHub Repository](https://github.com/sparkfun/SparkFun_Qwiic_XM125_Arduino_Library) or download the .ZIP by clicking the button below:

<div style="text-align: center"><a href="https://github.com/sparkfun/SparkFun_Qwiic_XM125_Arduino_Library/archive/refs/heads/main.zip" class="md-button">SparkFun XM125 A121 Arduino Library (ZIP)</a></div>

!!! note
    The SparkFun Qwiic XM125 Arduino Library uses the [SparkFun Toolkit](https://github.com/sparkfun/SparkFun_Toolkit) as a dependency. This should automatically download when installing  the library using the Arduino Library Manager. For users that are installing the XM125 library manually, make sure to download the SparkFun Toolkit as well. At the time of writing, we were using the following Arduino Libraries, firmware binaries, board add-ons.

     * Arduino Libraries
        * **SparkFun Qwiic XM125 Arduino Library v1.0.1**
        * **SparkFun Toolkit v0.9.1**
    * **Acconeer XM125 A121 v1.5.0** (i.e. SDK for XM125)
        * **i2c_presence_detector.bin**
        * **i2c_distance_detector.bin**
     * Board Definitions
        * **esp32 by Espressif v2.0.14** for the IoT RedBoard - ESP32.

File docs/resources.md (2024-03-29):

Now that you've successfully got your SparkFun Qwiic Pulsed Coherent Radar Sensor - XM125 up and running, it's time to incorporate it into your own project! With the SparkFun Qwiic Pulsed Coherent Radar Sensor, a world of [new project possibilities opens up](https://www.youtube.com/playlist?list=PLBXaD001iDmso2nj85R1iG7AShSYgcL0D). Imagine creating [presence detection systems](https://youtu.be/FttqEQLtVjQ?si=3scS9GtrTXE14HRb) for smart homes and security applications, [parking space occupancy detection](https://youtu.be/eNrfKaf3-3M?si=Vd9gIerkROAwhe-8), [gesture recognition interfaces](https://youtu.be/B3PrZ9erRug?si=0yjV2oetz_55DQW8) for [unique user control](https://youtu.be/bdTiTBzNvdQ?si=IpGVmbYIA616S8G5), [level measurement](https://youtu.be/MOlUlXCcesk?si=11bgIfvXdHoJx8F3) (for example, in tanks or [waste containers](https://youtu.be/uCZ_tKMUFNY?si=QVmMA5Gs1RwXbH9k)), [through-wall](https://youtu.be/RMisp_MbW-A?si=3XWUdU5shkHbTw4M) imaging systems for search and rescue, or even [advanced robotics with object avoidance and navigation](https://youtu.be/6Q1rqRHQ6BA?si=JSd-GgLQ1UCQuRe_).

For more information, check out the resources below:

**SparkFun Resources**

* [Schematic (PDF)](../assets/board_files/SparkFun_Qwiic_Pulsed_Coherent_Radar_Sensor_Breakout-XM125_Schematic_v10.pdf)
* [Eagle Files (ZIP)](../assets/board_files/SparkFun_Qwiic_Pulsed_Coherent_Radar_Sensor_Breakout-XM125_v10.zip)
* [Board Dimensions (PNG)](../assets/img/SparkFun_Qwiic_Pulsed_Coherent_Radar_Sensor_Breakout-XM125_Schematic_v10.png)
* [Arduino Library](https://github.com/sparkfun/SparkFun_Qwiic_XM125_Arduino_Library)
* [GitHub Hardware Repo](https://github.com/sparkfun/SparkFun_Qwiic_Pulsed_Radar_Sensor_XM125)
* [SFE Product Showcase](https://www.youtube.com/watch?v=BdbWGezCCSg)

**Acconeer Resources**

* Datasheets
    * [XM125](../assets/component_documentation/XM125_datasheet-3133248.pdf)
    * [A121](../assets/component_documentation/A121%20datasheet.pdf)
* User Guides
    * [Hardware and Physical Integration Guideline PCR Sensors A111 & A121](../assets/component_documentation/Hardware-integration-guideline.pdf)
    * [A121 Presence Detector](../assets/component_documentation/A121%20Presence%20Detector%20User%20Guide.pdf)
    * [I2C Presence Detector](../assets/component_documentation/I2C%20Presence%20Detector%20User%20Guide.pdf)
    * [A121 Distance Detector](../assets/component_documentation/A121%20Distance%20Detector%20User%20Guide.pdf)
    * [I2C Distance Detector](../assets/component_documentation/I2C%20Distance%20Detector%20User%20Guide.pdf)
    * [XM125 Software](../assets/component_documentation/XM125%20Software%20User%20Guide.pdf)
* [Acconeer Getting Started Guide](https://docs.acconeer.com/en/latest/)
    * [Handbook](https://docs.acconeer.com/en/latest/handbook/index.html)
    * [Exploration Tool](https://docs.acconeer.com/en/latest/exploration_tool/index.html)
* [Acconeer Python Exploration Tool](https://github.com/acconeer/acconeer-python-exploration)
* [STMicroelectronics STM32CubeProgrammer Software](https://www.st.com/en/development-tools/stm32cubeprog.html)
* [XM125 Firmware](https://developer.acconeer.com/home/a121-docs-software/xm125-xe125/)

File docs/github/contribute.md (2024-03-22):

# Contribute: Help Fix our Mistake!
Spot something wrong? Feel free to contribute our open-source design and documentation. 

## Improve our Documentation
All of this documentation can be modified by you! Please help us make it better.

* These pages are contained in the [`docs` folder of the SparkFun Qwiic Pulsed Coherent Radar Sensor - XM125 repository](https://github.com/sparkfun/SparkFun_Qwiic_Pulsed_Radar_Sensor_XM125/tree/main/docs).

### Submit a Correction
1. Fork this repo
2. Add your corrections or improvements to the markdown file
3. File a pull request with your changes, and enjoy making the ~~words~~ ~~worlds~~ world a better place.
    * Once received, the documentation specialist will automatically be notified.
    * We will review your suggested improvements to make sure they are correct and fit within our documentation standards.

## Improve our Hardware Design
All of our designs are open-source! Please help us make it better.

* Our board design files are contained in the [`Hardware` folder of the SparkFun Qwiic Pulsed Coherent Radar Sensor - XM125](https://github.com/sparkfun/SparkFun_Qwiic_Pulsed_Radar_Sensor_XM125/tree/main/Hardware).

### Submit a Design Improvement
1. Fork this repo
2. Add your design improvements
3. File a pull request with your changes, and enjoy making the ~~words~~ ~~worlds~~ world a better place.
    * Once received, the engineer in charge of the original design will automatically be notified.
    * We will review your suggested improvements, if they are within our board design standards and meet our product design requirements, we will flag these changes for our next board revision. *(Please note, that even if your suggestion is accepted, these changes may not be immediate. We may have to cycle through our current product inventory first.)*

## Contributors
Let's provided some recognition to the contributors for this project!

GitHub Contributors Image
<br>


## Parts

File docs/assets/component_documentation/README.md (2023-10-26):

SparkFun Documentation
=======================

This directory should include any necessary datasheets, example number crunching, etc.

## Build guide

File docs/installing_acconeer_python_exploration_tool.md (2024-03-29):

Acconeer has developed a GUI called the Exploration Tool to test the XM125 and fine-tune its settings for your project needs. The tool supports Windows and Linux and requires Python version 3.8 or later. The Acconeer's Exploration Tool is located in the [GitHub repository](https://github.com/acconeer/acconeer-python-exploration) below.

<div style="text-align: center"><a href="https://github.com/acconeer/acconeer-python-exploration" class="md-button">GitHub Repo: Acconeer Exploration Tool</a></div>

For more information about the Exploration Tool with the XM125 module, we recommend checking out [Acconeer's documentation](https://docs.acconeer.com/en/latest/exploration_tool/index.html). You will find information about installing the python tool for your OS, configuring the XM125 module, and reference applications for the A121. In this tutorial, we will briefly go over how to get started with the Exploration Tool.

<div style="text-align: center"><a href="https://docs.acconeer.com/en/latest/exploration_tool/index.html" class="md-button">Acconeer Docs: Exploration Tool</a></div>

!!! note
    The SparkFun Pulsed Coherent Radar Sensor - Acconeer XM125 uses the CH340 USB-to-serial converter as opposed to the CP210x that is linked in Acconeer's tutorials. You may need to install drivers for the USB-to-serial converter. Check out our section on "[How to Install CH340 Drivers](https://learn.sparkfun.com/tutorials/how-to-install-ch340-drivers)" for help with the installation.

!!! note
    The Acconeer Exploration Tool may run slower than expected when using the SparkFun Pulsed Coherent Radar Sensor - Acconeer XM125 with the software.

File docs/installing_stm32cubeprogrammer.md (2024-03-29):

In addition to the Arduino IDE, you may need to install the STM32CubeProgrammer as well. This software is needed to flash different firmware on the XM125.

Head over to STMicroelectronics, click on the **Get Software** button. This will scroll down to the bottom of the page. Select the STM32CubeProgrammer for your OS to install. After downloading, unzip the STM32CubeProgrammer and click on the installer. Follow the prompts to install the software.

<div style="text-align: center"><a href="https://www.st.com/en/development-tools/stm32cubeprog.html" class="md-button">Download the STM32Cube Programmer Here!</a></div>

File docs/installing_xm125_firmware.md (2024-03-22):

The XM125 uses different firmware for different applications. You will need to program the XM125 when using presence detection or distance detection. For users using the Arduino examples for presence detection, you can skip this section. Otherwise, follow the steps to flash the firmware for the distance detection or for those that are re-flashing the presence detection firmware.

### Installing STM32CubeProgrammer

Head over to STMicroelectronics, click on the **Get Software** button. This will scroll down to the bottom of the page. Select the STM32CubeProgrammer for your OS to install. After downloading, unzip the the STM32CubeProgrammer and click on the installer. Follow the prompts to install the software.

<div style="text-align: center"><a href="https://www.st.com/en/development-tools/stm32cubeprog.html" class="md-button">Download the STM32Cube Programmer Here!</a></div>

### Downloading Firmware

!!! note
    Arduino examples 1-5 with the default firmware (i.e. _i2c_presence_detector.bin_) that is loaded on the SparkFun Pulsed Coherent Radar Sensor - Acconeer XM125 (Qwiic). For Arduino examples 6-9, you will need to load the distance detection firmware (i.e. _i2c_distance_detector.bin_)

Each application requires a specific firmware to be flashed on the XM125. By default, the presence detection firmware (i.e. _i2c_presence_detector.bin_) is loaded on the SparkFun Pulsed Coherent Radar Sensor - Acconeer XM125 (Qwiic). For users that are interested in loading other firmware, we recommend heading over Acconeer's developer site to download the latest firmware. At the time of writing, this should be located under **Developer Tools & Support** > **A121 Docs & Software** > **XM125 / XE125**> **Acconeer XM125 A121 (SDK for XM125)**.

<div style="text-align: center"><a href="https://developer.acconeer.com/home/a121-docs-software/xm125-xe125/" class="md-button">Download the XM125 Firmware!</a></div>

!!! note
    You will need an account to download the firmware.  Make sure to register for an account and sign in to download the XM125 firmware.

### Flashing Firmware

Open the STM32CubeProgrammer software.

<div style="text-align: center;">
  <table>
    <tr style="vertical-align:middle;">
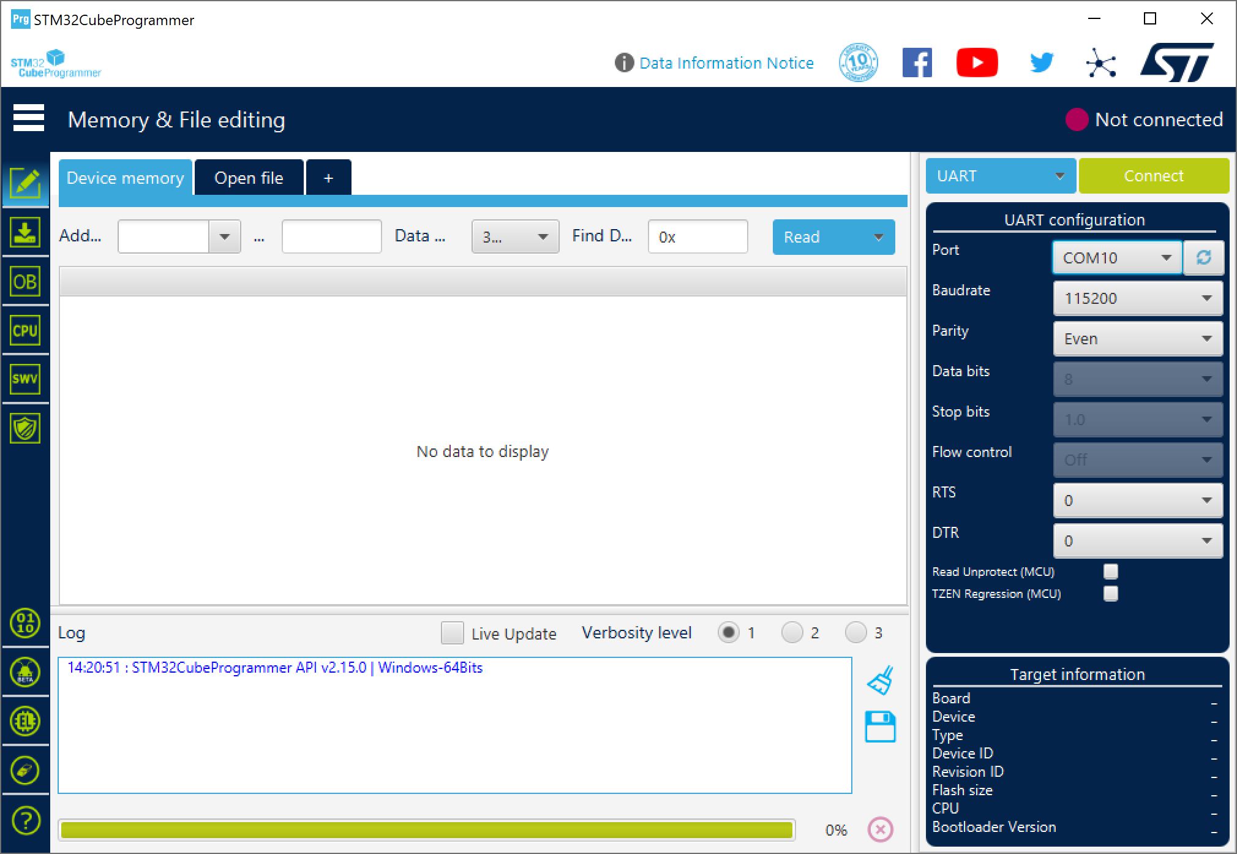
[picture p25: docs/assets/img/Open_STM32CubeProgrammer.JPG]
screenshot SFM32CubeProgrammer
     <td style="text-align: center; vertical-align: middle;"></td>
    </tr>
  </table>
</div>

Connect a USB between the SparkFun Pulsed Coherent Radar Sensor - Acconeer XM125 (Qwiic) and your computer.

<div style="text-align: center;">
  <table>
    <tr style="vertical-align:middle;">
     <td style="text-align: center; vertical-align: middle;"><a href="../assets/img/SEN-24540-Pulsed_Coherent_Radar_Acconeer_XM125_A121_USB_Cable.jpg">USB Cable Inserted into Pulsed Coherent Radar Sensor</a></td>
    </tr>
  </table>
</div>

You will need to set the XM125 in bootloader mode.

- Press and hold the BOOT button.
- Press the RST button while still holding down the BOOT button.
- Release the RST button.
- After a short moment, release the BOOT button.

<div style="text-align: center;">
  <table>
    <tr style="vertical-align:middle;">
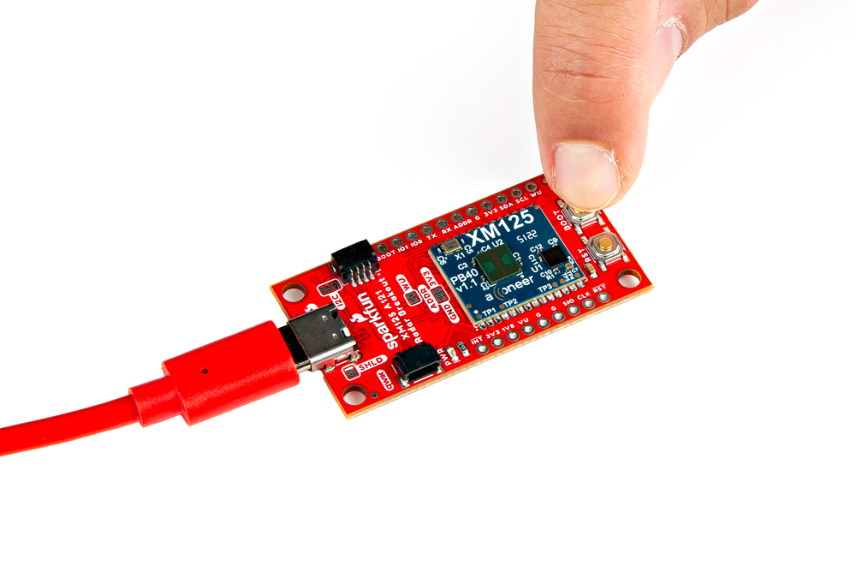
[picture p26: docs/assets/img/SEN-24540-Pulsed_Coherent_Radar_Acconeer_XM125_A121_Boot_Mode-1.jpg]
Press and hold BOOT Button
     <td style="text-align: center; vertical-align: middle; border: solid 1px #cccccc;></td>
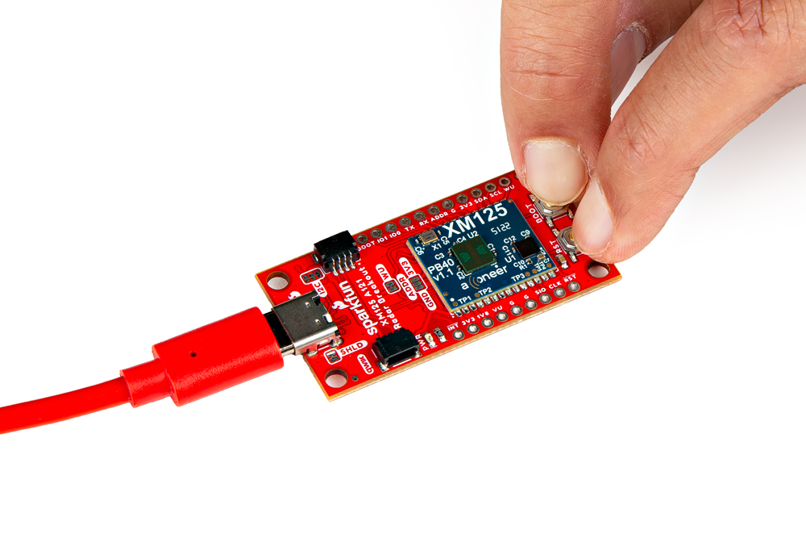
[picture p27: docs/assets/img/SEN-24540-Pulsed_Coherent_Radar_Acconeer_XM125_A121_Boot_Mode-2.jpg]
Press Reset Button
     <td style="text-align: center; vertical-align: middle; border: solid 1px #cccccc;></td>
     <td style="text-align: center; vertical-align: middle; border: solid 1px #cccccc;><a href="../assets/img/SEN-24540-Pulsed_Coherent_Radar_Acconeer_XM125_A121_Boot_Mode-1.jpg">Keep Holding Down BOOT Button</a></td>
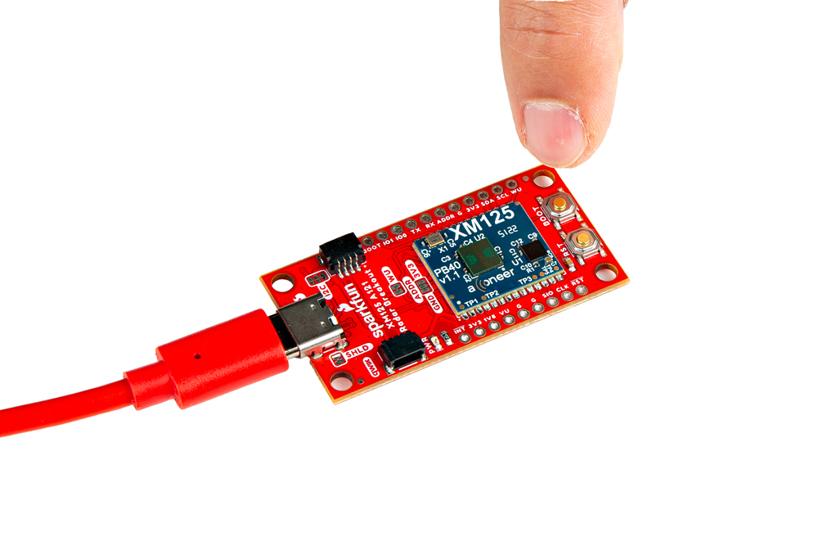
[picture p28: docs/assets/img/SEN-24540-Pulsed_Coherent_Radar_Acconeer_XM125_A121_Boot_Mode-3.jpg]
After a Short Moment, Release Boot Button
     <td style="text-align: center; vertical-align: middle; border: solid 1px #cccccc;></td>
   </tr>
  </table>
</div>

!!! note
    You will want to wait a short moment before releasing the BOOT button to give the XM125 a moment to recognize that the BOOT button is being held low. Releasing the RST button too fast after the XM125 resets may prevent the module from properly entering bootloader mode.

Select the COM port that the board enumerated to. In this case, it was COM10. The default UART configuration should already be set to the following:

    - 115200 baud
    - even parity
    - 8 data bits
    - 1 stop bit
    - no flow control

When ready, hit the **Connect** button.

<div style="text-align: center;">
  <table>
    <tr style="vertical-align:middle;">
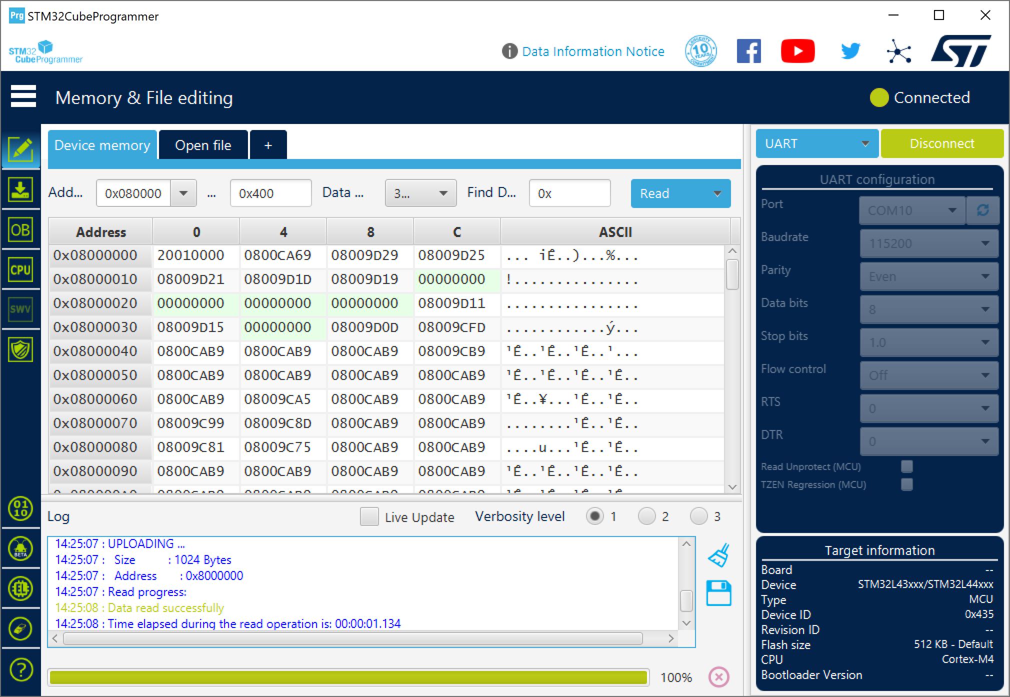
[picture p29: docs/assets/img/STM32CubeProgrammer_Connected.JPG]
screenshot STM32CubeProgrammer Connected to board
     <td style="text-align: center; vertical-align: middle;"></td>
    </tr>
  </table>
</div>

Click the **Download** button (the second button on the left navigation bar). Then click on the **Browse** button to select the firmware that you would like to flash to the board.

<div style="text-align: center;">
  <table>
    <tr style="vertical-align:middle;">
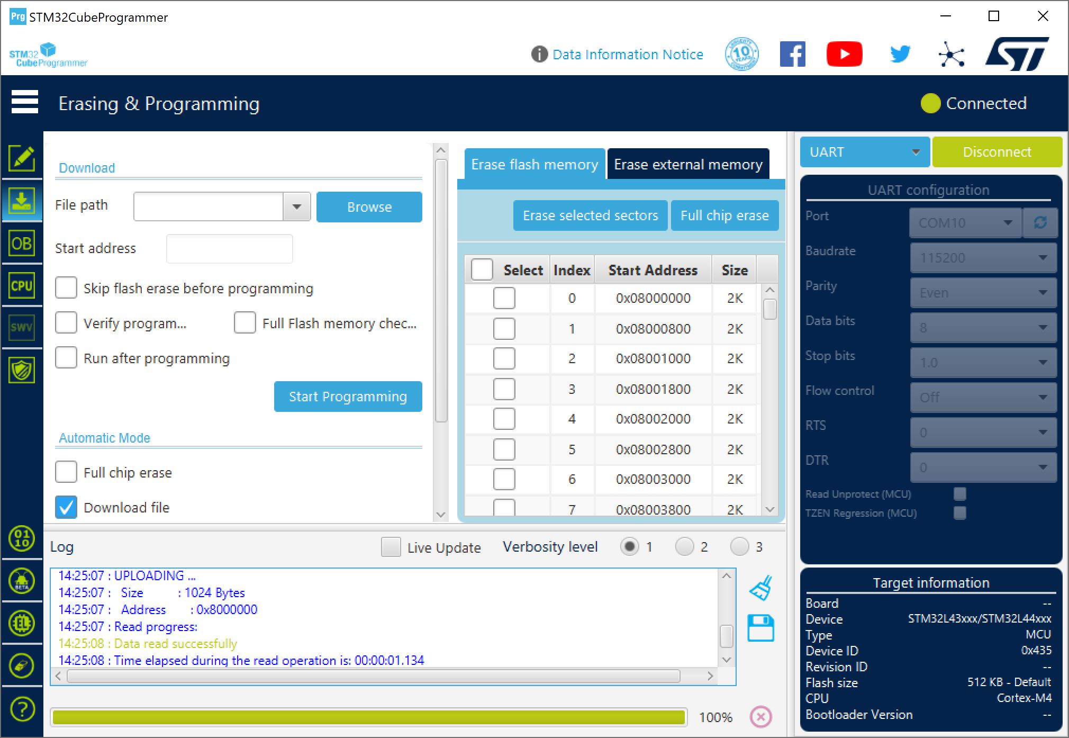
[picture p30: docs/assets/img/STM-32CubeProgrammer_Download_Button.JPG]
screenshot STM32CubeProgrammer Download Tab
     <td style="text-align: center; vertical-align: middle;"></td>
    </tr>
  </table>
</div>

Since the firmware for the presence detection is already flashed to the board, we will flash the firmware for the distance detection (i.e. **i2c_distance_detector.bin**). Head to the folder where you downloaded and unzipped the firmware.

<div style="text-align: center;">
  <table>
    <tr style="vertical-align:middle;">
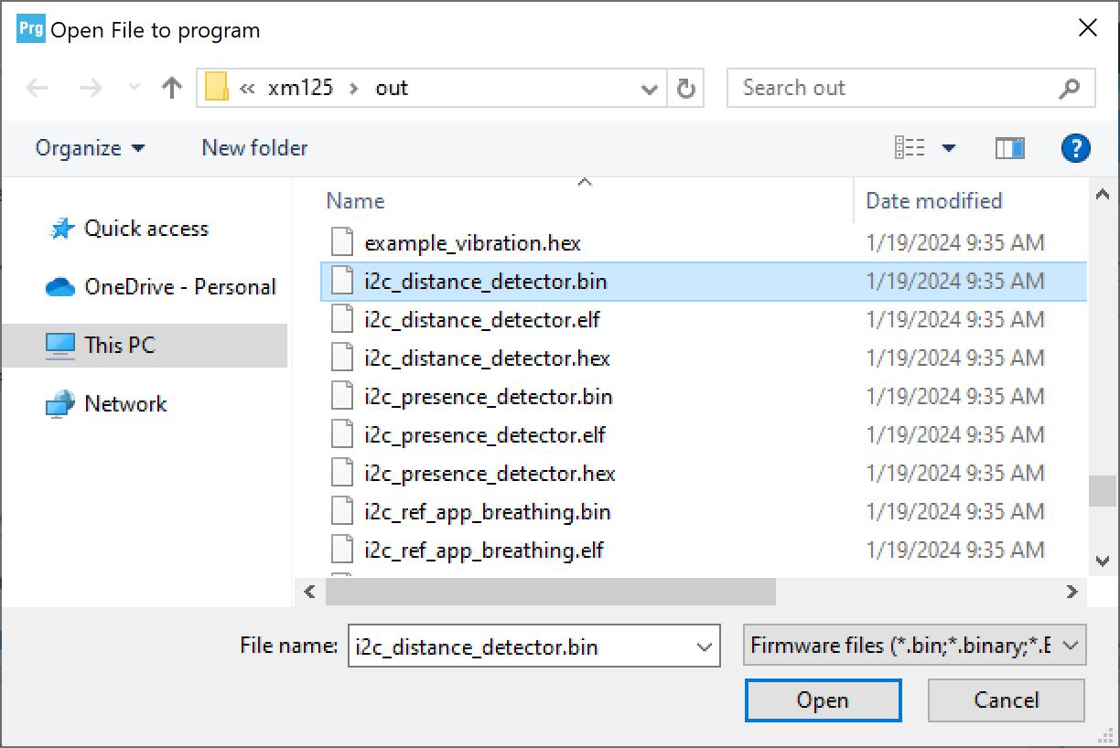
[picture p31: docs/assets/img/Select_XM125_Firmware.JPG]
screenshot file selected
     <td style="text-align: center; vertical-align: middle;"></td>
    </tr>
  </table>
</div>

Enter the start address **0x8000000** to flash the firmware. Click on the **Start Programming** button to begin flashing the firmware. Once flashed, you should an output after a few seconds: "File Download Complete" with the progress bar filled to 100%.

<div style="text-align: center;">
  <table>
    <tr style="vertical-align:middle;">
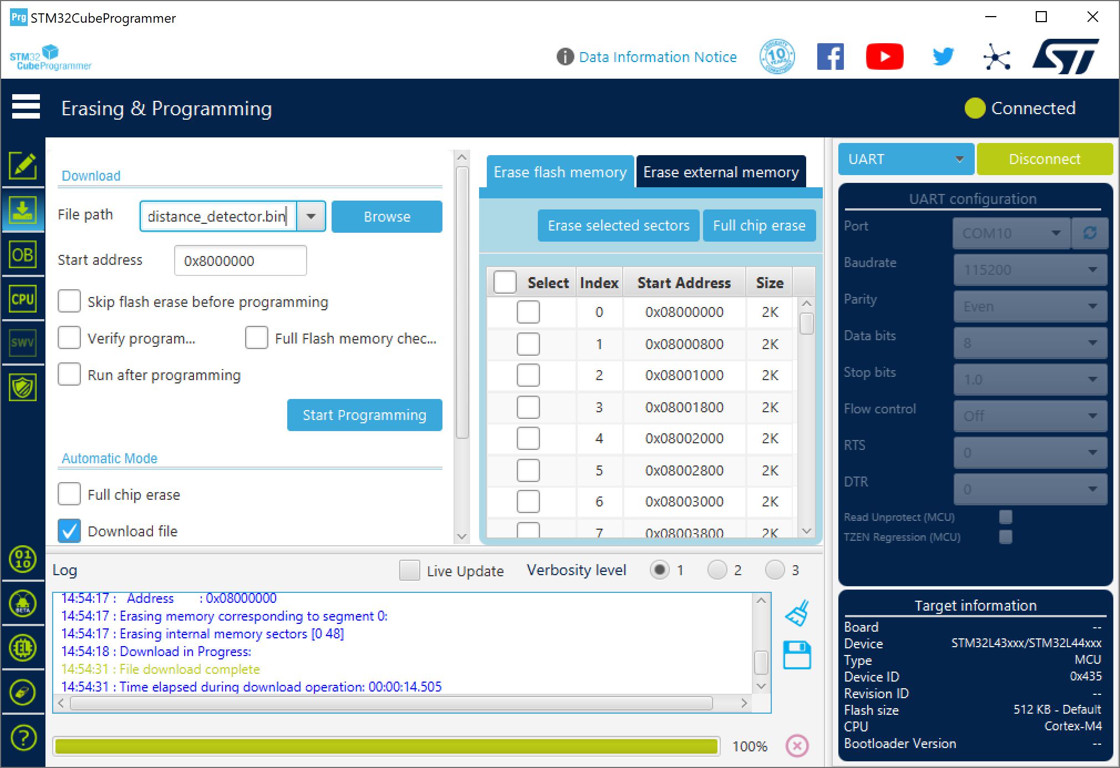
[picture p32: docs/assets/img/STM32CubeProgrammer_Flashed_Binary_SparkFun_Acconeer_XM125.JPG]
screenshot successfully uploaded
     <td style="text-align: center; vertical-align: middle;"></td>
    </tr>
  </table>
</div>

!!! Troubleshooting
    If you have problems uploading to the board, the board may not be set to Bootloader Mode.

    <div style="text-align: center;">
      <table>
        <tr style="vertical-align:middle;">
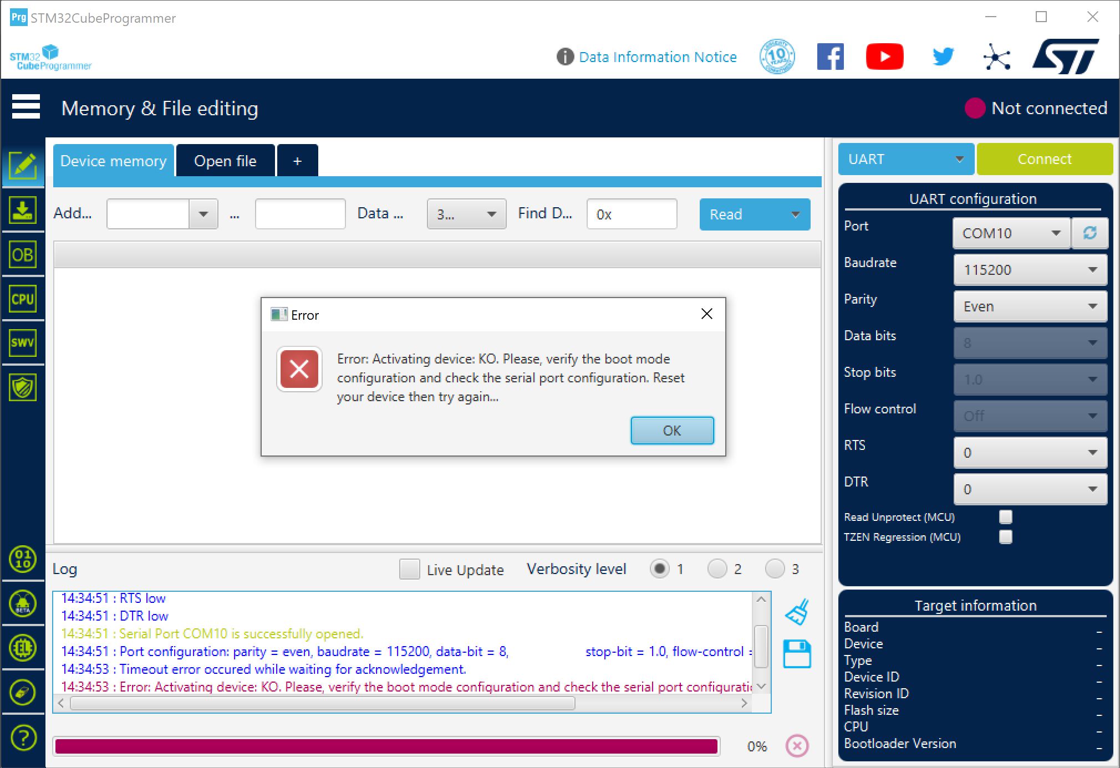
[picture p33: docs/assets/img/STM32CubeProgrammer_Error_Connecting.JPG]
Error Connecting SparkFun PCR Sensor Acconeer XM125 A121
         <td style="text-align: center; vertical-align: middle;"></td>
        </tr>
      </table>
    </div>

    Try checking the following before attempting to flash the board again.

    - Click on the refresh button next to the COM port in the STM32CubeProgrammer.
    - Check that you are selecting the correct COM port.
    - Unplugging and replugging the board back to your computer
    - Ensure that the CH340 drivers are installed on your computer.
    - Follow the steps outlined earlier to set the board in Bootloader Mode

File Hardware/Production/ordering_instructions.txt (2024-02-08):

panel size, 169x116mm
PCB thickness, 1.6mm
number of layers, 2
soldermask color, Red
silkscreen color, White
oz copper, 1oz
finish, HASL lead free
stencils, top+bottom
pcs per panel, 12
min trace width, 0.2540mm / 0.0100in
min drill size, 0.3048mm / 0.0120in

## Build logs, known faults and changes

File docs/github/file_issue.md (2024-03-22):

# Did we make a mistake?

Spot something wrong? Please let us know. 

!!! attention
    This is not where customers should seek assistance on a product. If you require technical assistance or have questions about a product that is not working as expected, please head over to the [SparkFun Technical Assistance](https://www.sparkfun.com/technical_assistance) page for some initial troubleshooting.
    <center>
    [SparkFun Technical Assistance Page](https://www.sparkfun.com/technical_assistance){ .md-button .md-button--primary }
    </center>

    If you can't find what you need there, you'll need a [Forum Account](https://forum.sparkfun.com/ucp.php?mode=register) to search product forums and post questions.

## Discrepancies in the Documentation

All of this documentation can be modified by you! Please help us make it better.

* The documentation files for these pages are contained in the [`docs` folder of the SparkFun Qwiic Pulsed Coherent Radar Sensor - XM125 repository](https://github.com/sparkfun/SparkFun_Qwiic_Pulsed_Radar_Sensor_XM125/tree/main/docs).

### Spot something wrong?
If a section of the documentation is incorrect, please [open an issue](https://github.com/sparkfun/SparkFun_Qwiic_Pulsed_Radar_Sensor_XM125/issues) and let us know.

### Do you have a suggested correction?
1. With a GitHub account, fork this repo
2. Add your correction(s) or improvement(s) to the markdown file(s)
3. File a pull request with your changes, and enjoy making the ~~words~~ ~~worlds~~ world a better place.
    * Once received, the documentation specialist will automatically be notified.
    * We will review your suggested improvement(s) to make sure they are correct and fit within our documentation standards.

## Problems in the Hardware Design

All of our designs are open-source! Please help us make it better.

* Our board design files are contained in the [`Hardware` folder of the SparkFun Qwiic Pulsed Coherent Radar Sensor - XM125 repository](https://github.com/sparkfun/SparkFun_Qwiic_Pulsed_Radar_Sensor_XM125/tree/main/Hardware).

### Does something not make sense?
If part of the design is confusing, please [open an issue](https://github.com/sparkfun/SparkFun_Qwiic_Pulsed_Radar_Sensor_XM125/issues) and let us know.

### Did we forget to include an important function of the board?
* Please keep in mind that we may intentionally exclude certain functions of the board to meet our product design requirements. *(For example, our Qwiic Micro boards are intended to fit on a small board layout and only use I<sup>2</sup>C communication; therefore, we may not have the SPI and interrupt pins available for users.)*
* If part of the board's functionality is missing, please [open an issue](https://github.com/sparkfun/SparkFun_Qwiic_Pulsed_Radar_Sensor_XM125/issues) and file a feature request.

### Do you wish to contribute directly to improving the board design?
1. With a GitHub account, Fork this repo
2. Add your design improvement(s)
3. File a pull request with your changes, and enjoy making the ~~words~~ ~~worlds~~ world a better place.
    * Once received, the engineer in charge of the original design will automatically be notified.
    * We will review your suggested improvement(s), if they are within our board design standards and meet our product design requirements, we will flag these changes for our next board revision. *(Please note, that even if your suggestion is accepted, these changes may not be immediate. We may have to cycle through our current product inventory first.)*

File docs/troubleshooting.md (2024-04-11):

### General Troubleshooting Help

!!! note
    <span class="glyphicon glyphicon-question-sign" aria-hidden="true"></span>
        <strong> Not working as expected and need help? </strong> <br /><br />

    If you need technical assistance and more information on a product that is not working as you expected, we recommend heading on over to the <a href="https://www.sparkfun.com/technical_assistance">SparkFun Technical Assistance</a> page for some initial troubleshooting. <br /><br />

    <div style="text-align: center"><a href="https://www.sparkfun.com/technical_assistance" target="sfe_technical_assistance" class="md-button">SparkFun Technical Assistance Page</a></div>

    If you don't find what you need there, <a href="https://support.acconeer.com/support/home">Acconeer's Support Forum</a> or our <a href="https://forum.sparkfun.com/">SparkFun Forums</a> are a great place to find and ask for help. <br /><br />

    <div style="text-align: center"><a href="https://support.acconeer.com/support/home" class="md-button">Acconeer's Support Forum</a>&nbsp;&nbsp;&nbsp;<a href="https://forum.sparkfun.com/" class="md-button md-button--primary">SparkFun Forums</a></div>

### Issue Flashing Firmware

If you have problems uploading to the board, the board may not be set to Bootloader Mode. You will see the following error with flashing firmware using either the STM32CubeProgrammer.

<div style="text-align: center;">
  <table>
    <tr style="vertical-align:middle;">
     <td style="text-align: center; vertical-align: middle;"><a href="../assets/img/STM32CubeProgrammer_Error_Connecting.JPG">Error Connecting SparkFun PCR Sensor Acconeer XM125 A121</a></td>
    </tr>
  </table>
</div>

For users using the Acconeer Exploration Tool, you may see the following error when flashing firmware.

<div style="text-align: center;">
  <table>
    <tr style="vertical-align:middle;">
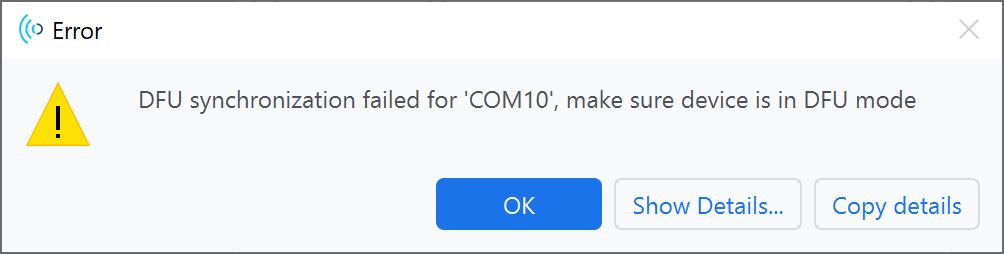
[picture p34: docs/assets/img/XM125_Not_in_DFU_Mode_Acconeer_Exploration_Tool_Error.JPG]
Error Connecting SparkFun PCR Sensor Acconeer XM125 A121
     <td style="text-align: center; vertical-align: middle;"></td>
    </tr>
  </table>
</div>

Try checking the following before attempting to flash the board again.

- If you are using the STM32CubeProgrammer, click on the refresh button next to the COM port.
- Check that you are selecting the correct COM port.
- Unplugging and replugging the board back to your computer.
- Ensure that the CH340 drivers are installed on your computer.
- Follow the steps outlined earlier to set the board in Bootloader Mode.
- If you have the Arduino IDE also open and had connected the board to the software, make sure to close the software before connecting the XM125 to the STM32CubeProgrammer or Acconeer Exploration Tool.

### Issue 1 Connecting to the Acconeer Exploration Tool

If you receive the following error when trying to connect the XM125 to the Acconeer Exploration Tool, the problem may be due to the COM port's configuration.

``` bash
Failed to connect:
recv timeout
```

<div style="text-align: center;">
  <table>
    <tr style="vertical-align:middle;">
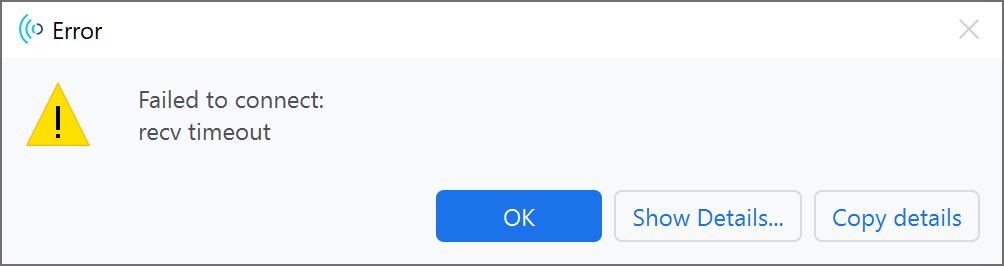
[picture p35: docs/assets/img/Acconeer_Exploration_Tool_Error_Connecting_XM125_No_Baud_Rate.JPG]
Error Connecting SparkFun PCR Sensor Acconeer XM125 A121 with Acconeer Exploration Tool
     <td style="text-align: center; vertical-align: middle;"></td>
    </tr>
  </table>
</div>

When clicking on the "**Show Details...**" button, you may see the following detailed error:

``` bash
Traceback (most recent call last):
  File "C:\Users\...\portable_exploration_tool\tools\python-3.9.10-embed-amd64\lib\site-packages\acconeer\exptool\app\new\backend\_model.py", line 75, in connect_client
    self.client = client_factory()
  File "C:\Users\...\portable_exploration_tool\tools\python-3.9.10-embed-amd64\lib\site-packages\acconeer\exptool\a121\_core\communication\client.py", line 50, in open
    return super().open(
  File "C:\Users\...\portable_exploration_tool\tools\python-3.9.10-embed-amd64\lib\site-packages\acconeer\exptool\_core\communication\client.py", line 87, in open
    return subclass.open(  # type: ignore[no-any-return, attr-defined]
  File "C:\Users\...\portable_exploration_tool\tools\python-3.9.10-embed-amd64\lib\site-packages\acconeer\exptool\a121\_core\communication\exploration_client.py", line 91, in open
    return cls(client_info=client_info)
  File "C:\Users\...\portable_exploration_tool\tools\python-3.9.10-embed-amd64\lib\site-packages\acconeer\exptool\a121\_core\communication\exploration_client.py", line 115, in __init__
    self._server_info = self._retrieve_server_info()
  File "C:\Users\...\portable_exploration_tool\tools\python-3.9.10-embed-amd64\lib\site-packages\acconeer\exptool\a121\_core\communication\exploration_client.py", line 139, in _retrieve_server_info
    system_info_response = self._server_stream.wait_for_message(messages.SystemInfoResponse)
  File "C:\Users\...\portable_exploration_tool\tools\python-3.9.10-embed-amd64\lib\site-packages\acconeer\exptool\_core\communication\message_stream.py", line 64, in wait_for_message
    for message in self._stream:
  File "C:\Users\...\portable_exploration_tool\tools\python-3.9.10-embed-amd64\lib\site-packages\acconeer\exptool\_core\communication\message_stream.py", line 83, in _get_stream
    self._error_callback(e)
  File "C:\Users\...\portable_exploration_tool\tools\python-3.9.10-embed-amd64\lib\site-packages\acconeer\exptool\a121\_core\communication\exploration_client.py", line 135, in _close_before_reraise
    raise exception
  File "C:\Users\...\portable_exploration_tool\tools\python-3.9.10-embed-amd64\lib\site-packages\acconeer\exptool\_core\communication\message_stream.py", line 81, in _get_stream
    header_in_bytes = self._link.recv_until(self.protocol.end_sequence)
  File "C:\Users\...\portable_exploration_tool\tools\python-3.9.10-embed-amd64\lib\site-packages\acconeer\exptool\_core\communication\links\serial_link.py", line 155, in recv_until
    raise LinkError("recv timeout")
acconeer.exptool._core.communication.links.buffered_link.LinkError: recv timeout

During handling of the above exception, another exception occurred:

Traceback (most recent call last):
  File "C:\Users\...\portable_exploration_tool\tools\python-3.9.10-embed-amd64\lib\site-packages\acconeer\exptool\app\new\backend\_backend.py", line 161, in process_program
    model.execute_task(task)
  File "C:\Users\...\portable_exploration_tool\tools\python-3.9.10-embed-amd64\lib\site-packages\acconeer\exptool\app\new\backend\_model.py", line 51, in execute_task
    builtin_task(**kwargs)
  File "C:\Users\...\portable_exploration_tool\tools\python-3.9.10-embed-amd64\lib\site-packages\acconeer\exptool\app\new\backend\_model.py", line 87, in connect_client
    raise HandledException(msg)
acconeer.exptool.app.new._exceptions.HandledException: Failed to connect:
recv timeout
```

In this case, the COM port did not have a baud rate. Make sure to manually enter the COM port's baud rate and set it to **115200** baud.

### Issue 2 Connecting to the Acconeer Exploration Tool

If you receive the following error when trying to connect the XM125 to the Acconeer Exploration Tool, the problem might be due to another program that is already connected to the COM port.

``` bash
could not open port 'COM10': PermissionError(13, 'Access is denied.', None, 5)
```

<div style="text-align: center;">
  <table>
    <tr style="vertical-align:middle;">
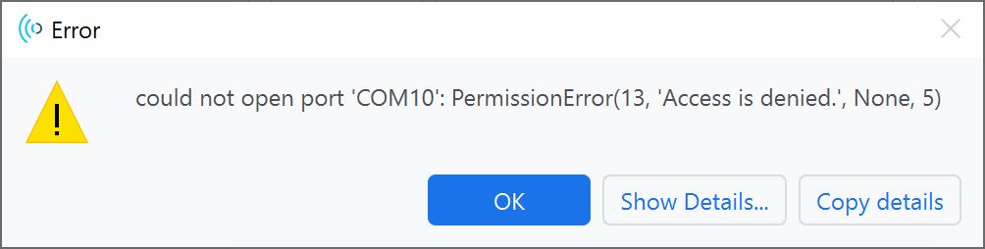
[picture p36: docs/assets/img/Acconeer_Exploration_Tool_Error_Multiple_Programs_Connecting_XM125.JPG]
Error Connecting SparkFun PCR Sensor Acconeer XM125 A121 with Acconeer Exploration Tool
     <td style="text-align: center; vertical-align: middle;"></td>
    </tr>
  </table>
</div>

When clicking on the "**Show Details...**" button, you may see the following detailed error:

``` bash
Traceback (most recent call last):
  File "C:\Users\...\portable_exploration_tool\tools\python-3.9.10-embed-amd64\lib\site-packages\acconeer\exptool\app\new\backend\_model.py", line 75, in connect_client
    self.client = client_factory()
  File "C:\Users\...\portable_exploration_tool\tools\python-3.9.10-embed-amd64\lib\site-packages\acconeer\exptool\a121\_core\communication\client.py", line 50, in open
    return super().open(
  File "C:\Users\...\portable_exploration_tool\tools\python-3.9.10-embed-amd64\lib\site-packages\acconeer\exptool\_core\communication\client.py", line 87, in open
    return subclass.open(  # type: ignore[no-any-return, attr-defined]
  File "C:\Users\...\portable_exploration_tool\tools\python-3.9.10-embed-amd64\lib\site-packages\acconeer\exptool\a121\_core\communication\exploration_client.py", line 91, in open
    return cls(client_info=client_info)
  File "C:\Users\...\portable_exploration_tool\tools\python-3.9.10-embed-amd64\lib\site-packages\acconeer\exptool\a121\_core\communication\exploration_client.py", line 107, in __init__
    (self._link, self._client_info) = ensure_connected_link(self.client_info)
  File "C:\Users\...\portable_exploration_tool\tools\python-3.9.10-embed-amd64\lib\site-packages\acconeer\exptool\_core\communication\links\helpers.py", line 101, in ensure_connected_link
    link.connect()
  File "C:\Users\...\portable_exploration_tool\tools\python-3.9.10-embed-amd64\lib\site-packages\acconeer\exptool\_core\communication\links\serial_link.py", line 118, in connect
    self._ser.open()
  File "C:\Users\...\portable_exploration_tool\tools\python-3.9.10-embed-amd64\lib\site-packages\serial\serialwin32.py", line 64, in open
    raise SerialException("could not open port {!r}: {!r}".format(self.portstr, ctypes.WinError()))
serial.serialutil.SerialException: could not open port 'COM10': PermissionError(13, 'Access is denied.', None, 5)

During handling of the above exception, another exception occurred:

Traceback (most recent call last):
  File "C:\Users\...\portable_exploration_tool\tools\python-3.9.10-embed-amd64\lib\site-packages\acconeer\exptool\app\new\backend\_backend.py", line 161, in process_program
    model.execute_task(task)
  File "C:\Users\...\portable_exploration_tool\tools\python-3.9.10-embed-amd64\lib\site-packages\acconeer\exptool\app\new\backend\_model.py", line 51, in execute_task
    builtin_task(**kwargs)
  File "C:\Users\...\portable_exploration_tool\tools\python-3.9.10-embed-amd64\lib\site-packages\acconeer\exptool\app\new\backend\_model.py", line 87, in connect_client
    raise HandledException(msg)
acconeer.exptool.app.new._exceptions.HandledException: Failed to connect:
could not open port 'COM10': PermissionError(13, 'Access is denied.', None, 5)
```

Try the checking the following before attempting to connect to the board again.

- Check that you are selecting the correct COM port.
- Unplugging and replugging the board back to your computer.
- If you have the Arduino IDE or STM32CubeProgrammer also open and had previously connected to the COM port, make sure to close the software before connecting the XM125 to the Acconeer Exploration Tool.
- Close the instance of the Acconeer Exploration Tool and restart the program.

### Issue Starting Measurements with the Acconeer Exploration Tool

If you receive the following error when trying to begin measurements with the XM125 on the Acconeer Exploration Tool, the problem may be due to the COM port's configuration.

<pre><code class="language-bash">Cannot detach a recorder from a closed client

<b>Unhandled error - please file a bug</b>
</code></pre>

<div style="text-align: center;">
  <table>
    <tr style="vertical-align:middle;">
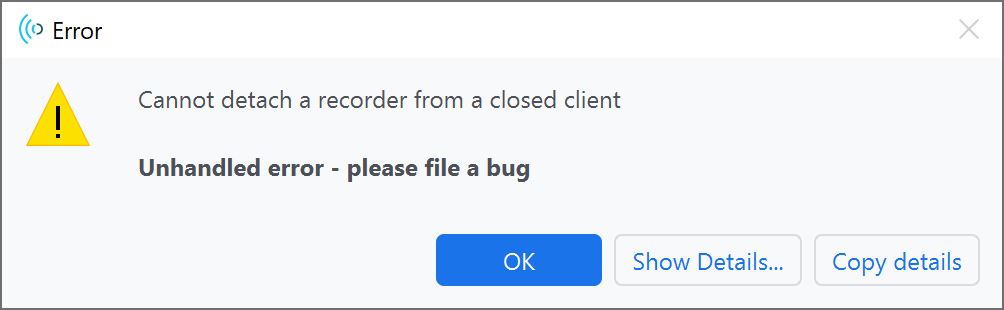
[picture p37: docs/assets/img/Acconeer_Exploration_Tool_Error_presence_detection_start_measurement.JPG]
Error Measuring with the SparkFun PCR Sensor Acconeer XM125 A121 on the Acconeer Exploration Tool
     <td style="text-align: center; vertical-align: middle;"></td>
    </tr>
  </table>
</div>

When clicking on the "**Show Details...**" button, you may see the following detailed error:

```bash
Traceback (most recent call last):
  File "C:\Users\...\portable_exploration_tool\tools\python-3.9.10-embed-amd64\lib\site-packages\acconeer\exptool\_core\communication\message_stream.py", line 86, in _get_stream
    header: dict[str, t.Any] = json.loads(header_in_bytes)
  File "json\__init__.py", line 346, in loads
  File "json\decoder.py", line 340, in decode
json.decoder.JSONDecodeError: Extra data: line 1 column 14 (char 13)

During handling of the above exception, another exception occurred:

Traceback (most recent call last):
  File "C:\Users\...\portable_exploration_tool\tools\python-3.9.10-embed-amd64\lib\site-packages\acconeer\exptool\a121\algo\_plugins\_a121.py", line 176, in start_session
    self._start_session(self._recorder)
  File "C:\Users\...\portable_exploration_tool\tools\python-3.9.10-embed-amd64\lib\site-packages\acconeer\exptool\a121\algo\presence\_detector_plugin.py", line 161, in _start_session
    self._detector_instance.start(recorder)
  File "C:\Users\...\portable_exploration_tool\tools\python-3.9.10-embed-amd64\lib\site-packages\acconeer\exptool\a121\algo\presence\_detector.py", line 247, in start
    self.estimated_frame_rate = estimate_frame_rate(self.client, self.session_config)
  File "C:\Users\...\portable_exploration_tool\tools\python-3.9.10-embed-amd64\lib\site-packages\acconeer\exptool\a121\algo\_utils.py", line 446, in estimate_frame_rate
    client.stop_session()
  File "C:\Users\...\portable_exploration_tool\tools\python-3.9.10-embed-amd64\lib\site-packages\acconeer\exptool\app\new\backend\_application_client.py", line 106, in stop_session
    result = self._wrapped_client.stop_session()
  File "C:\Users\...\portable_exploration_tool\tools\python-3.9.10-embed-amd64\lib\site-packages\acconeer\exptool\a121\_core\communication\exploration_client.py", line 294, in stop_session
    _ = self._server_stream.wait_for_message(
  File "C:\Users\...\portable_exploration_tool\tools\python-3.9.10-embed-amd64\lib\site-packages\acconeer\exptool\_core\communication\message_stream.py", line 64, in wait_for_message
    for message in self._stream:
  File "C:\Users\...\portable_exploration_tool\tools\python-3.9.10-embed-amd64\lib\site-packages\acconeer\exptool\_core\communication\message_stream.py", line 88, in _get_stream
    self._error_callback(RuntimeError(f"Cannot decode header {header_in_bytes!r}"))
  File "C:\Users\...\portable_exploration_tool\tools\python-3.9.10-embed-amd64\lib\site-packages\acconeer\exptool\a121\_core\communication\exploration_client.py", line 135, in _close_before_reraise
    raise exception
RuntimeError: Cannot decode header bytearray(b'"result_info":[[{"tick":35909,"data_saturated":false,"temperature":48,"calibration_needed":false,"frame_delayed":false}]],"status":"ok","payload_size":1280}\n')

During handling of the above exception, another exception occurred:

Traceback (most recent call last):
  File "C:\Users\...\portable_exploration_tool\tools\python-3.9.10-embed-amd64\lib\site-packages\acconeer\exptool\app\new\backend\_backend.py", line 161, in process_program
    model.execute_task(task)
  File "C:\Users\...\portable_exploration_tool\tools\python-3.9.10-embed-amd64\lib\site-packages\acconeer\exptool\app\new\backend\_model.py", line 56, in execute_task
    plugin_task(**kwargs)
  File "C:\Users\...\portable_exploration_tool\tools\python-3.9.10-embed-amd64\lib\site-packages\acconeer\exptool\a121\algo\_plugins\_a121.py", line 178, in start_session
    recorder = self.client.detach_recorder()
  File "C:\Users\...\portable_exploration_tool\tools\python-3.9.10-embed-amd64\lib\site-packages\acconeer\exptool\_core\communication\client.py", line 157, in detach_recorder
    raise ClientError("Cannot detach a recorder from a closed client")
acconeer.exptool._core.communication.client.ClientError: Cannot detach a recorder from a closed client
```
This is probably due to the COM port settings (i.e. you probably selected the "Auto-connect" checkbox). You will need to close the instance of the Acconeer Exploration Tool, unplug/replug the XM125 back to your computer, and manually enter the COM port's baud rate.

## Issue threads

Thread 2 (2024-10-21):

Missing file detected during build

Boussetta, 2024-10-21:
### Cannot build the projects
I have encountered 2 main issues.
The first is related to the toolchain path.

I have added to the `makefile` the following lines to resolve it:

```
GNU_INSTALL_ROOT := /path/to/gcc-arm-none-eabi-10.3-2021.10/bin
STM32CUBE_FW_L4_ROOT := /path/to/SparkFun_Qwiic_Pulsed_Radar_Sensor_XM125/Firmware/STM32CubeIDEProject

```
But then I still have a terminated build:

```
SparkFun_Qwiic_Pulsed_Radar_Sensor_XM125/Firmware/STM32CubeIDEProject/Drivers/CMSIS/Device/ST/STM32L4xx/Include/stm32l4xx.h:129:12: fatal error: stm32l431xx.h: No such file or directory
  129 |   #include "stm32l431xx.h"
      |            ^~~~~~~~~~~~~~~
compilation terminated.
```

I have checked the `makefile` as it's including the STM32L431xx files.
`CFLAGS += -DSTM32L431xx -DUSE_HAL_DRIVER`

in the `stm32l4xx.h` we have

```
#elif defined(STM32L431xx)
  #include "stm32l431xx.h"
```

but unfortunately these files are not available in the `STM32CubeIDEProject`

```
ls Firmware/STM32CubeIDEProject/Drivers/CMSIS/Device/ST/STM32L4xx/Include/
stm32l476xx.h
stm32l4xx.h
system_stm32l4xx.h
```
when selecting `CFLAGS += -DSTM32L476xx` that doesn't solve the issue as more file are not found in this case and I don't believe that it's appropriate to change the target `HAL` the Makefile to build  the project for the XM125.

### Steps to reproduce

1. `cd` path_to/ `SparkFun_Qwiic_Pulsed_Radar_Sensor_XM125/Firmware/A121 SDK for XM125/xm125`
2. `make all`

### Expected behavior
`Make all` under `SparkFun_Qwiic_Pulsed_Radar_Sensor_XM125/Firmware/A121 SDK for XM125/xm125` should be sufficient for building the project.

### Actual behavior
The makefile project build is failing

Boussetta, 2024-10-23:
Problem solved by linking the official `STM32CubeL4` SDK and using `gcc-arm-none-eabi-9-2020-q2` Solves the problem.
But still the SDK should be linked as a submodule with a note about the toolchain.

Closed 2024-10-23.

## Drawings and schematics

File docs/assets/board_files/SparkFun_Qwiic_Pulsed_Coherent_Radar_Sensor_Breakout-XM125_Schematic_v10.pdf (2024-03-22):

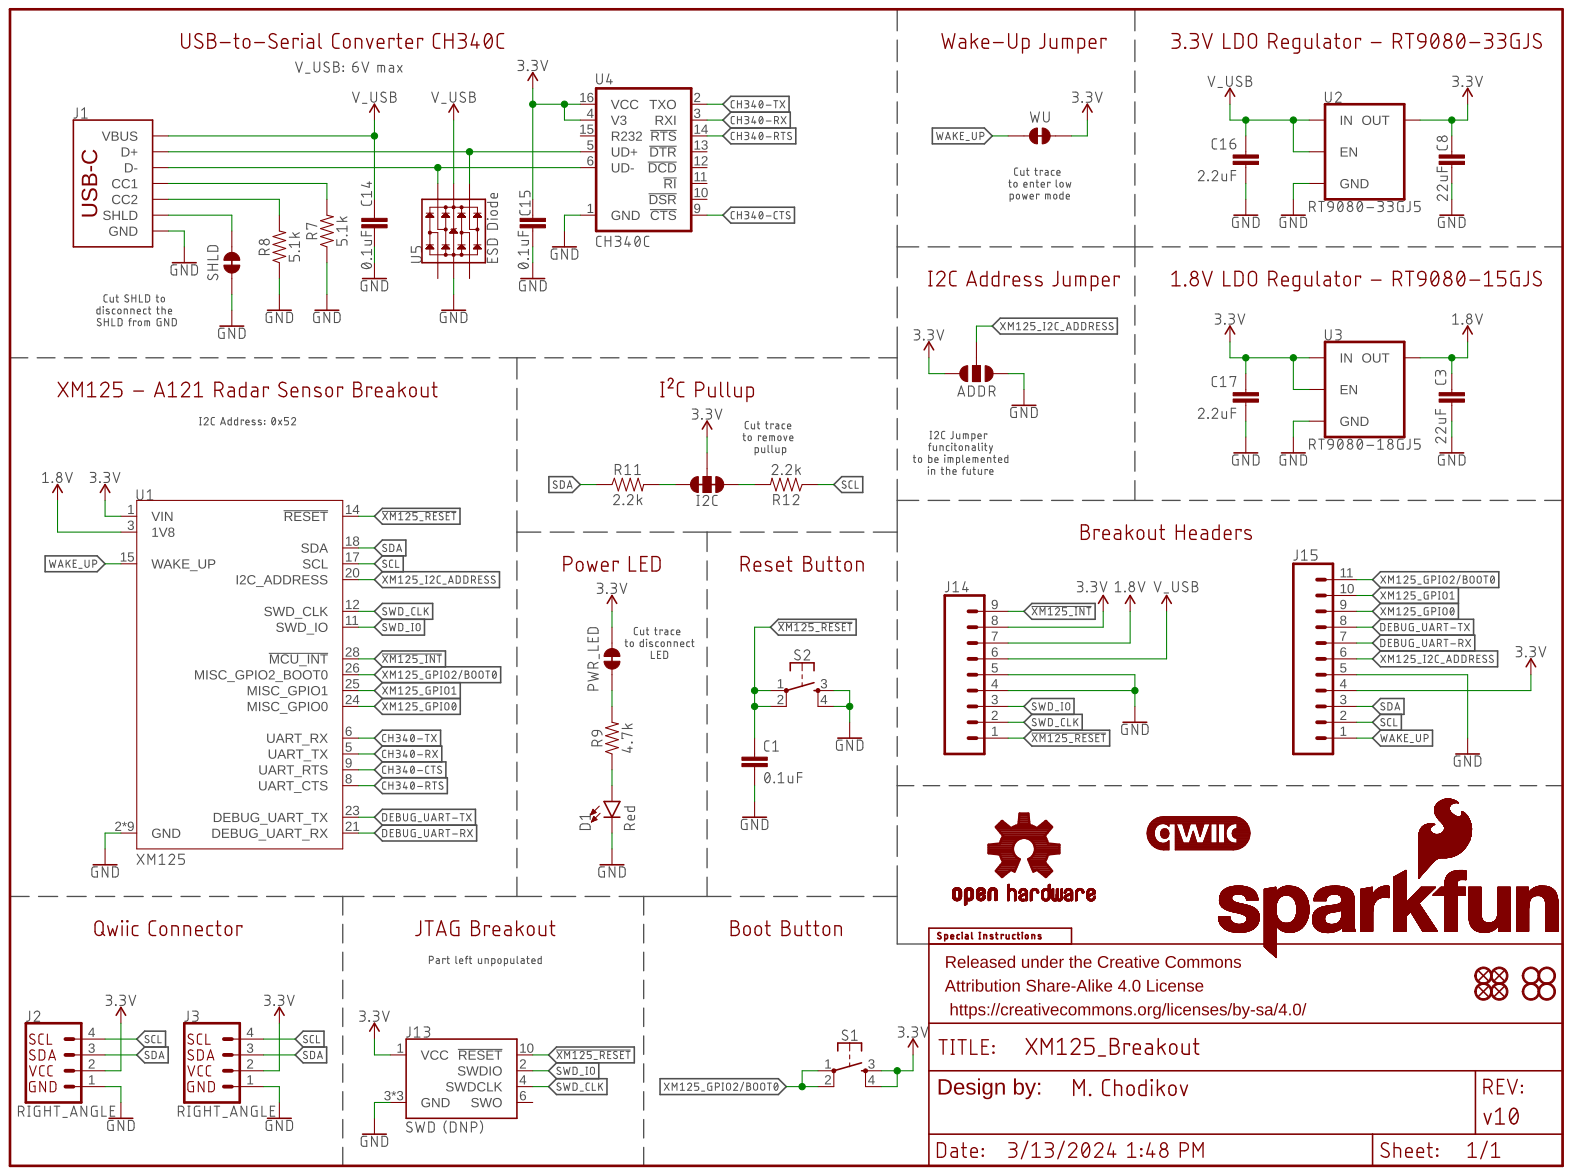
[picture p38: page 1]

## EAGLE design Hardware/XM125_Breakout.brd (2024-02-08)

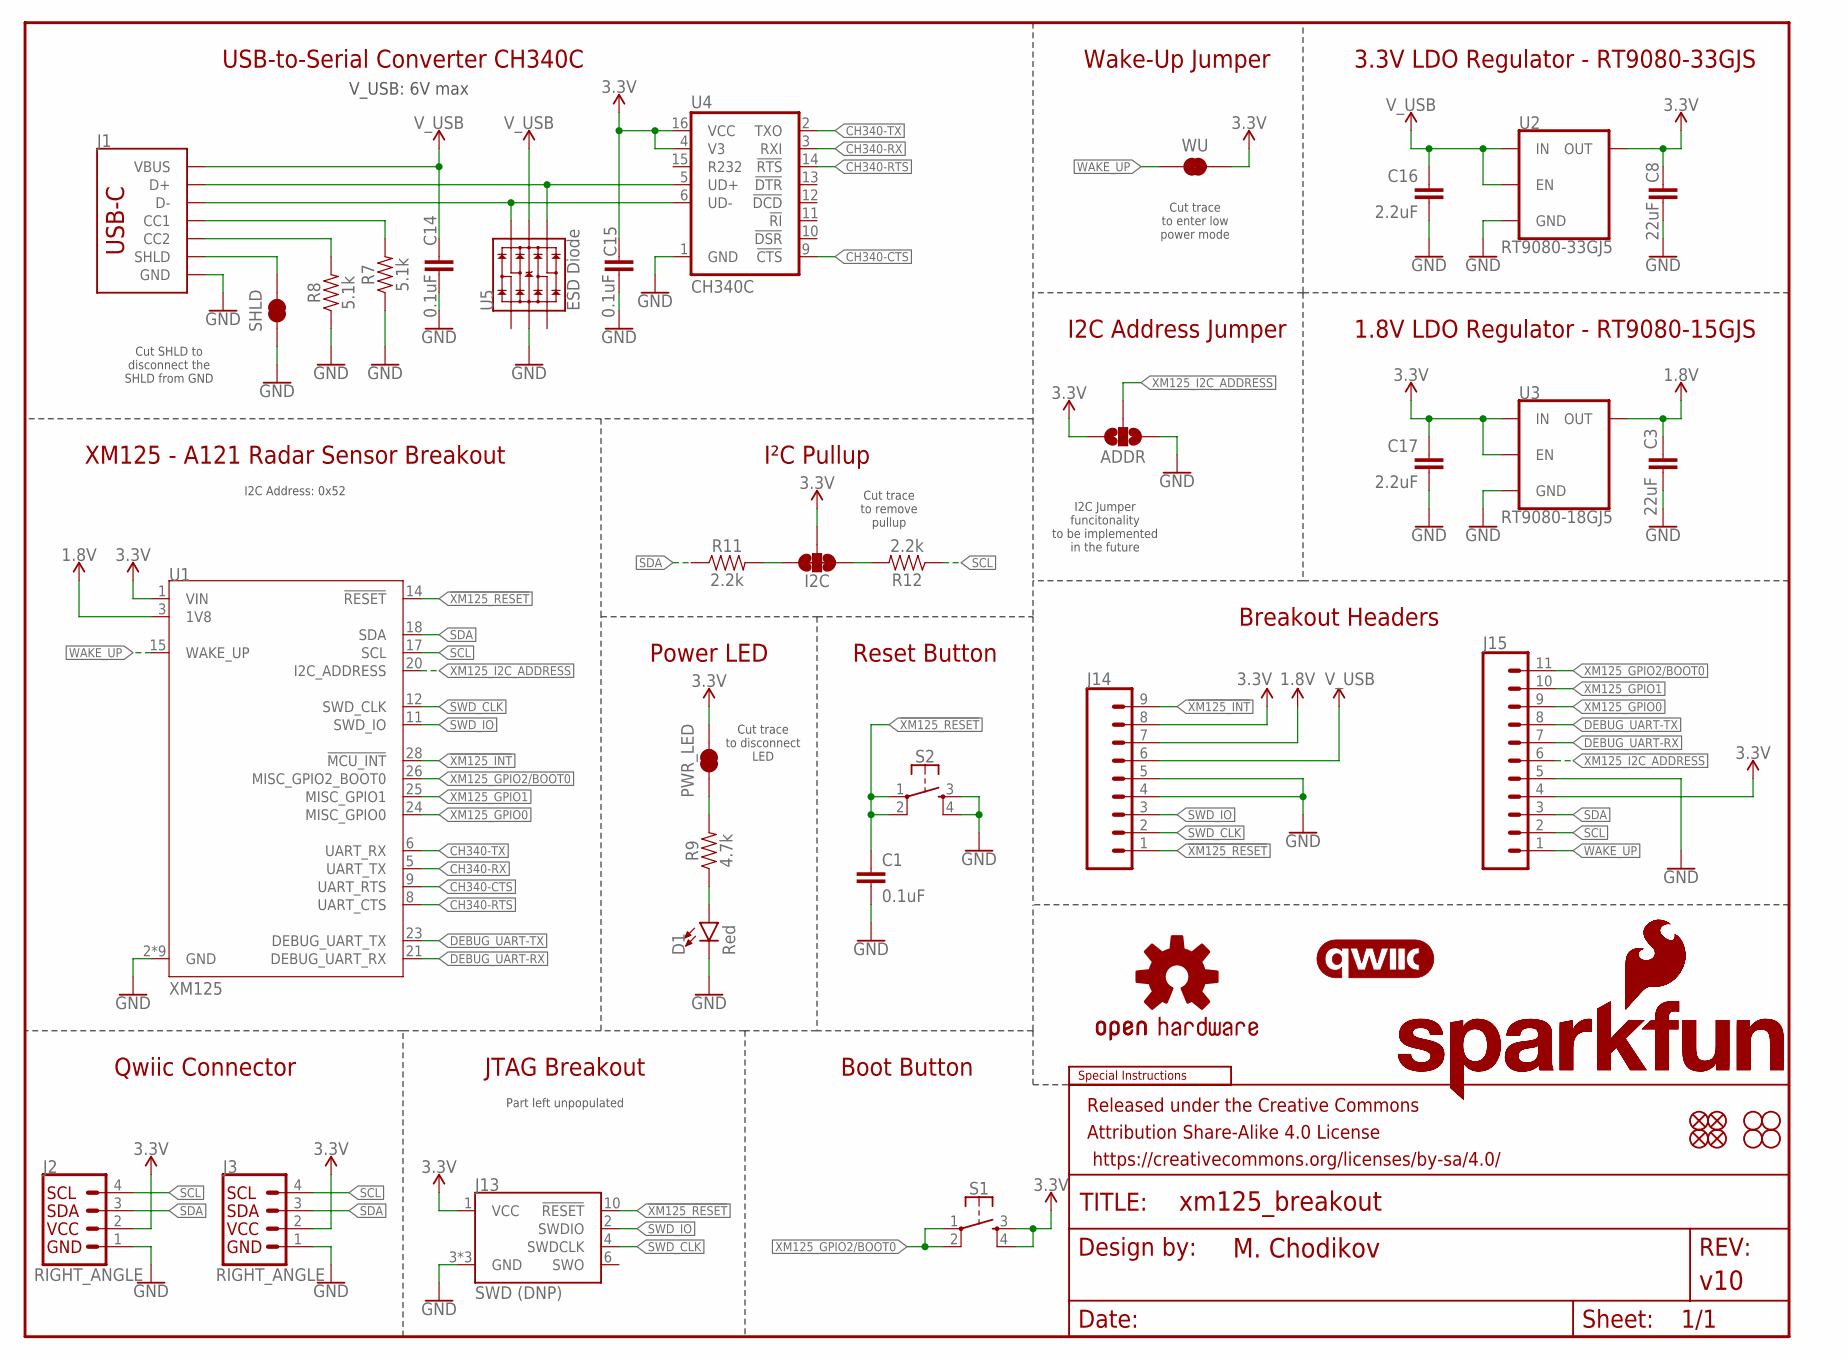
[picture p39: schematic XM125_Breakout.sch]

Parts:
ADDR: JUMPER-SMT_3_NO_SILK; SMT-JUMPER_3_NO_SILK
C1, C14, C15: 0.1uF; 0603
C3, C8: 22uF; 0603
C16, C17: 2.2uF; 0603
D1: Red; LED-0603
FD1, FD2, FD3, FD4: FIDUCIAL1X2; FIDUCIAL-1X2
FRAME2: FRAME-LETTER; CREATIVE_COMMONS
H1, H2, H3, H4: STAND-OFF
I2C: JUMPER-SMT_3_2-NC_TRACE_SILK; SMT-JUMPER_3_2-NC_TRACE_SILK
J1: USB_C_2-LAYER_PADS; USB-C-16P-2LAYER-PADS
J2, J3: RIGHT_ANGLE; JST04_1MM_RA
J13: SWD (DNP); 2X5-SMD-UNSHROUDED_DNP_NO_PASTE
J14: CONN_09NO_SILK; 1X09_NO_SILK
J15: CONN_111X11_NO_SILK; 1X11_NO_SILK
LOGO1: SPECIAL_INSTRUCTIONS-ORDERING; ORDERING_INSTRUCTIONS
LOGO2: QWIIC_LOGO_4MM; QWIIC_4MM
LOGO3, LOGO6: SFE_LOGO_NAME_FLAME.1_INCH; SFE_LOGO_NAME_FLAME_.1
LOGO4: OSHW-LOGOS; OSHW-LOGO-S
LOGO5: SFE_LOGO_FLAME.1_INCH; SFE_LOGO_FLAME_.1
PWR_LED: JUMPER-SMT_2_NC_TRACE_SILK; SMT-JUMPER_2_NC_TRACE_SILK
R7, R8: 5.1k; 0603
R9: 4.7k; 0603
R11, R12: 2.2k; 0603
S1, S2: MOMENTARY-SWITCH-SPST-2-SMD-5.2MM; TACTILE_SWITCH_SMD_5.2MM
SHLD: JUMPER-SMT_2_NC_TRACE_SILK; SMT-JUMPER_2_NC_TRACE_SILK
U1: XM125; XM125_ACC
U2: RT9080-33GJ5; SOT23-5
U3: RT9080-18GJ5; SOT23-5
U4: CH340C; SO016
U5: ESD Diode; SOT-23-6
WU: JUMPER-SMT_2_NC_TRACE_SILK; SMT-JUMPER_2_NC_TRACE_SILK

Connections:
1.8V: C3.1, J14.7, U1.3 (1V8), U3.5 (OUT)
3.3V: ADDR.3, C8.1, C15.1, C17.1, I2C.2, J2.2, J3.2, J13.1 (VCC), J14.8, J15.4, PWR_LED.2, S1.3, S1.4, U1.1 (VIN), U2.5 (OUT), U3.1 (IN), U3.3 (EN), U4.4 (V3), U4.16 (VCC), WU.2
!XM125_INT: J14.9, U1.28 (!MCU_INT)
!XM125_RESET: C1.2, J13.10 (!RESET), J14.1, S2.1, S2.2, U1.14 (!RESET)
CH340-CTS: U1.9 (UART_RTS), U4.9 (!CTS)
CH340-RTS: U1.8 (UART_CTS), U4.14 (!RTS)
CH340-RX: U1.5 (UART_TX), U4.3 (RXI)
CH340-TX: U1.6 (UART_RX), U4.2 (TXO)
DEBUG_UART-RX: J15.7, U1.21 (DEBUG_UART_RX)
DEBUG_UART-TX: J15.8, U1.23 (DEBUG_UART_TX)
GND: ADDR.1, C1.1, C3.2, C8.2, C14.2, C15.2, C16.2, C17.2, D1.C, J1.GND, J1.GND2 (GND), J2.1, J3.1, J13.3 (GND), J13.5 (GND), J13.9 (GND), J14.4, J14.5, J15.5, R7.1, R8.1, S2.3, S2.4, SHLD.1, U1.2 (GND), U1.4 (GND), U1.7 (GND), U1.10 (GND), U1.13 (GND), U1.16 (GND), U1.19 (GND), U1.22 (GND), U1.27 (GND), U2.2 (GND), U3.2 (GND), U4.1 (GND), U5.2 (VSS)
unnamed: J1.A6 (D+), J1.B6 (D+), U4.5 (UD+), U5.4 (IO3)
unnamed: J1.A7 (D-), J1.B7 (D-), U4.6 (UD-), U5.6 (IO4)
unnamed: J1.SHLD1 (SHLD), J1.SHLD2 (SHLD), J1.SHLD3 (SHLD), J1.SHLD4 (SHLD), SHLD.2
unnamed: J1.B5 (CC2), R8.2
unnamed: J1.A5 (CC1), R7.2
unnamed: PWR_LED.1, R9.2
unnamed: D1.A, R9.1
unnamed: I2C.3, R11.2
unnamed: I2C.1, R12.2
SCL: J2.4, J3.4, J15.2, R12.1, U1.17 (SCL)
SDA: J2.3, J3.3, J15.3, R11.1, U1.18 (SDA)
SWD_CLK: J13.4 (SWDCLK), J14.2, U1.12 (SWD_CLK)
SWD_IO: J13.2 (SWDIO), J14.3, U1.11 (SWD_IO)
V_USB: C14.1, C16.1, J1.VBUS1 (VBUS), J1.VBUS2 (VBUS), J14.6, U2.1 (IN), U2.3 (EN), U5.5 (VCC)
WAKE_UP: J15.1, U1.15 (WAKE_UP), WU.1
XM125_GPIO0: J15.9, U1.24 (MISC_GPIO0)
XM125_GPIO1: J15.10, U1.25 (MISC_GPIO1)
XM125_GPIO2/BOOT0: J15.11, S1.1, S1.2, U1.26 (MISC_GPIO2_BOOT0)
XM125_I2C_ADDRESS: ADDR.2, J15.6, U1.20 (I2C_ADDRESS)

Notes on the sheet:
USB-to-Serial Converter CH340C
1.8V LDO Regulator - RT9080-15GJS
3.3V LDO Regulator - RT9080-33GJS
XM125 - A121 Radar Sensor Breakout
Qwiic Connector
Power LED
Breakout Headers
I²C Pullup
Cut trace to remove pullup
Boot Button
Cut trace to disconnect LED
I2C Address: 0x52
JTAG Breakout
Part left unpopulated
Wake-Up Jumper
I2C Address Jumper
Reset Button
V_USB: 6V max
Cut trace to enter low power mode
I2C Jumper funcitonality to be implemented in the future
Cut SHLD to disconnect the SHLD from GND

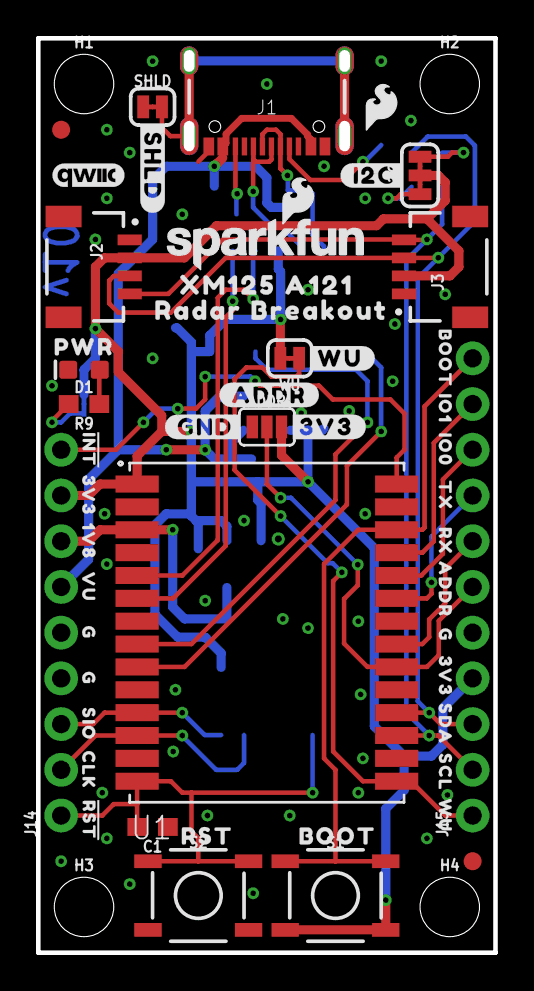
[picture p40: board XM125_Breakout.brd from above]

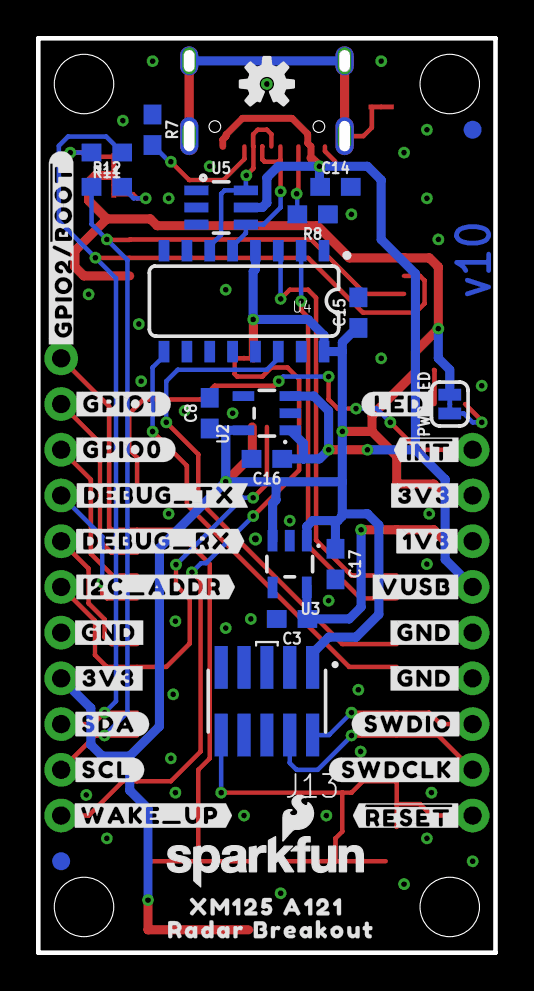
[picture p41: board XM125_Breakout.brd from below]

Board: 2 copper layers, 25.4 x 50.8 mm, 100 parts (43 on the bottom side), 30 nets.

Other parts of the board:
U$1: #INT143
U$2: ##INT#2
U$3: #LED#139
U$4, U$30, U$31: #GND#141
U$5: RST1630063003525
U$6: RX1152
U$7: #SWDIO#4
U$8: #VUSB#1
U$9: #3V3#17
U$10: #SCL#8
U$11: BOOT21630063003532
U$12: PWR21630063003533
U$13: #SDA#9
U$14, U$33: 3V3144
U$15: 1V8144
U$16: #1V8#141
U$17: RADAR_BREAKOUT1163
U$18: WU9
U$19: #RST6
U$20: #GPIO0#5
U$21: #GPIO1#5
U$22: #WU#14
U$23, U$32: #3V3#141
U$24: XM125_A1211163
U$25: #ADDR#16
U$26: #I2C#126
U$27: #GPIO2##BOOT#141
U$28: #DEBUG_RX#19
U$29: #SHLD#129
U$34, U$35, U$36: G144
U$38: VU146
U$39: IO0147
U$40: IO1148
U$41: BOOT1149
U$42: CLK1150
U$43: #SWDCLK#1151
U$44: TX1153
U$45: ADDR1154
U$46: SDA1155
U$47: SCL1157
U$48: #I2C_ADDR#12
U$49: SIO1159
U$50: #GND#17
U$51: #DEBUG_TX#18
U$53: RADAR_BREAKOUT1166
U$54: XM125_A1211167
U$55: #WAKE_UP#12
U$56: ##RESET#13

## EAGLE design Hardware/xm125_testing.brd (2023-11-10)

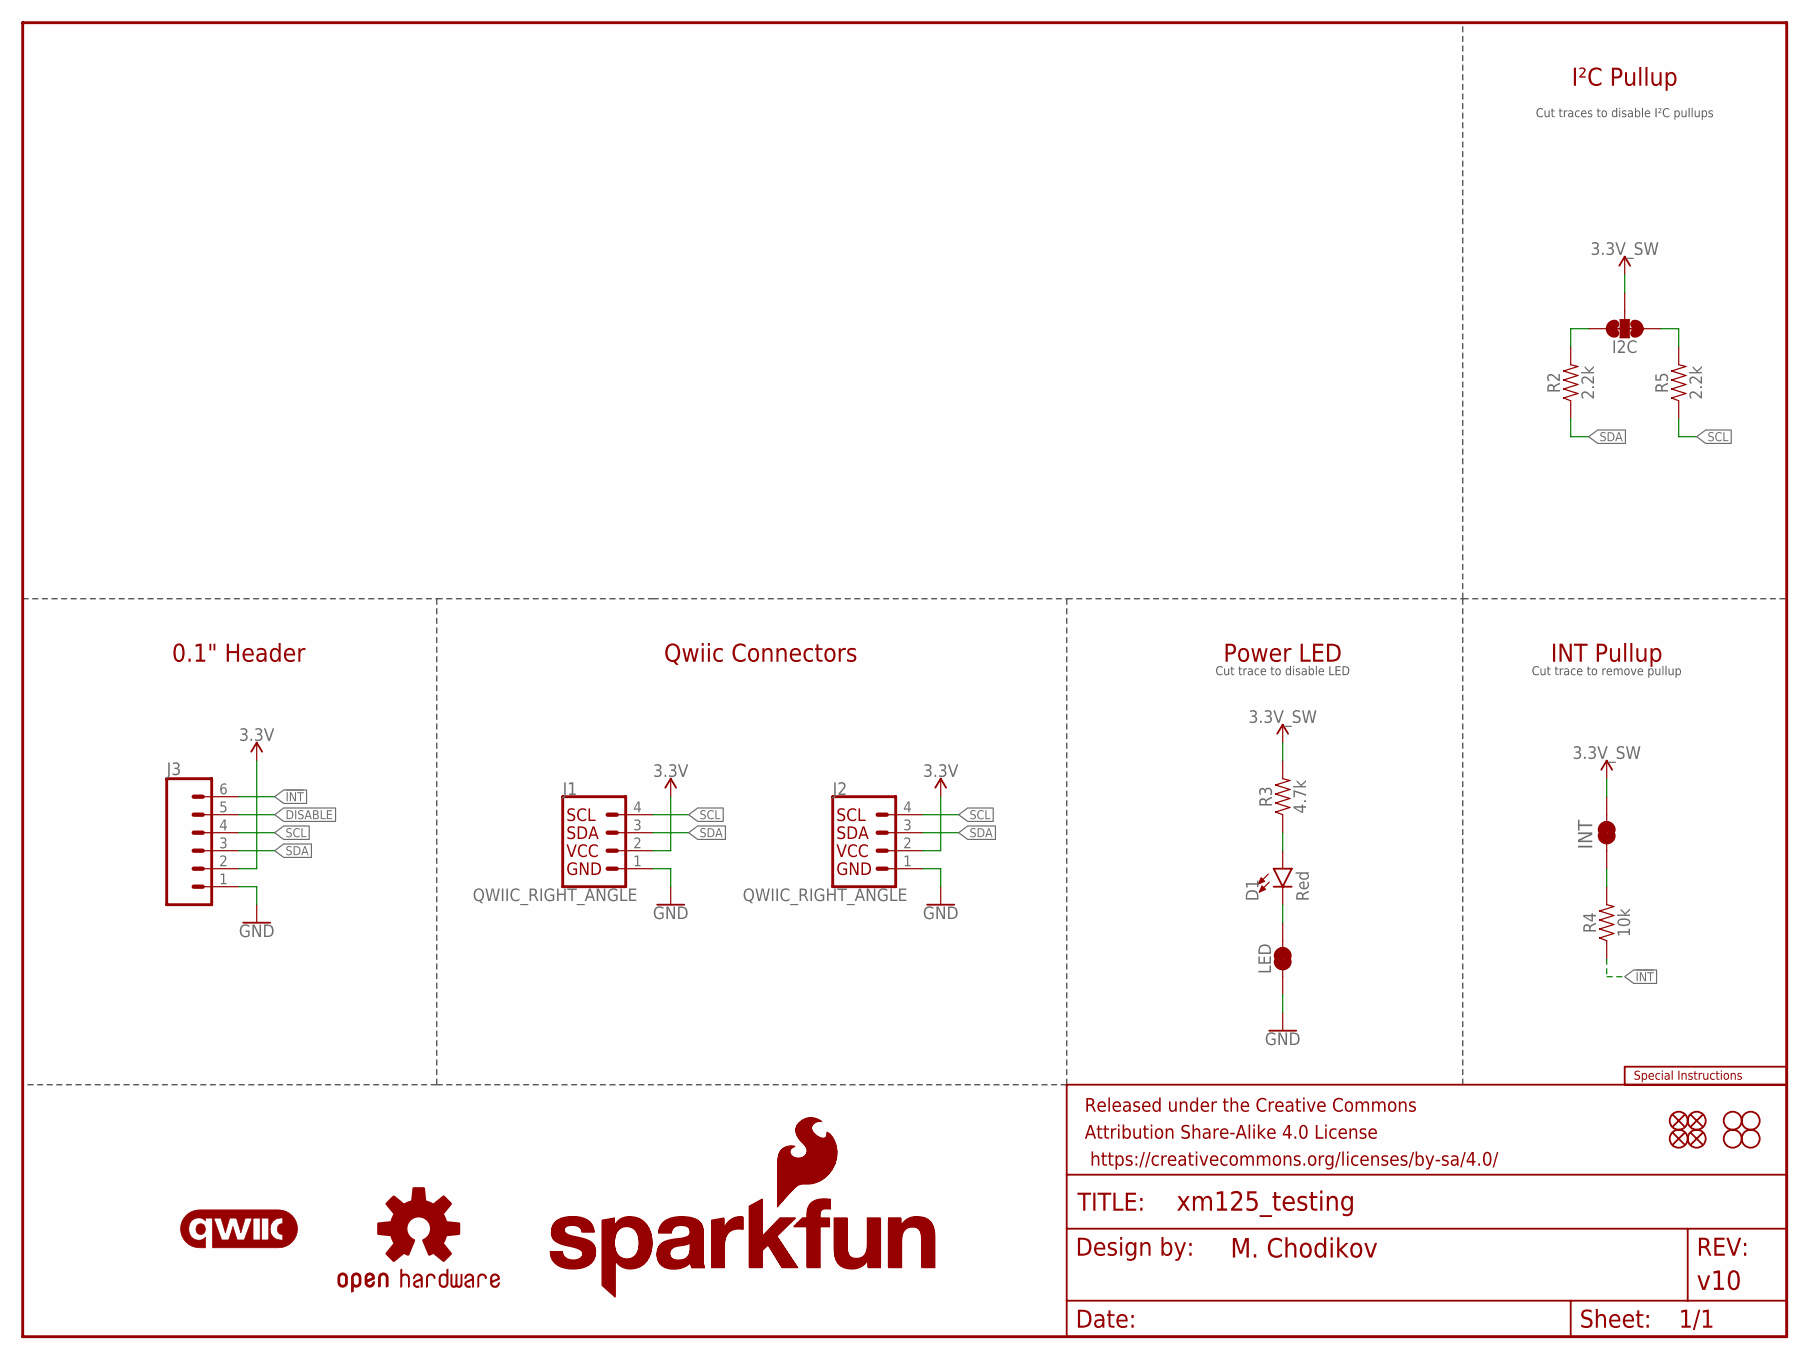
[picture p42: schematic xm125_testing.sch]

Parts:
D1: Red; LED-0603
FD1, FD2, FD3, FD4: FIDUCIAL1X2; FIDUCIAL-1X2
FRAME1: FRAME-LETTER; CREATIVE_COMMONS
H1, H2, H3, H4: STAND-OFF
I2C: JUMPER-SMT_3_2-NC_TRACE_SILK; SMT-JUMPER_3_2-NC_TRACE_SILK
J1, J2: QWIIC_RIGHT_ANGLE; JST04_1MM_RA
J3: CONN_06NO_SILK_FEMALE_PTH; 1X06_NO_SILK
JP2: JUMPER-SMT_2_NC_TRACE_SILK; SMT-JUMPER_2_NC_TRACE_SILK
LED: JUMPER-SMT_2_NC_TRACE_SILK; SMT-JUMPER_2_NC_TRACE_SILK
LOGO1: OSHW-LOGOS; OSHW-LOGO-S
LOGO2: SFE_LOGO_NAME_FLAME.1_INCH; SFE_LOGO_NAME_FLAME_.1
LOGO3: QWIIC_LOGO_4MM; QWIIC_4MM
LOGO4: SFE_LOGO_NAME8_MM; SFE_LOGO_NAME_8MM
LOGO5: SPECIAL_INSTRUCTIONS-ORDERING; ORDERING_INSTRUCTIONS
LOGO6: SFE_LOGO_FLAME.1_INCH; SFE_LOGO_FLAME_.1
R2, R5: 2.2k; 0603
R3: 4.7k; 0603
R4: 10k; 0603

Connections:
3.3V: J1.2, J2.2, J3.2
3.3V_SW: I2C.2, JP2.2, R3.2
!INT: J3.6, R4.1
DISABLE: J3.5
GND: J1.1, J2.1, J3.1, LED.1
unnamed: D1.C, LED.2
unnamed: I2C.3, R2.2
unnamed: D1.A, R3.1
unnamed: JP2.1, R4.2
unnamed: I2C.1, R5.2
SCL: J1.4, J2.4, J3.4, R5.1
SDA: J1.3, J2.3, J3.3, R2.1

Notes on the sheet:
I²C Pullup
Cut traces to disable I²C pullups
Cut trace to disable LED
Power LED
Cut trace to remove pullup
INT Pullup
0.1" Header
Qwiic Connectors
INT

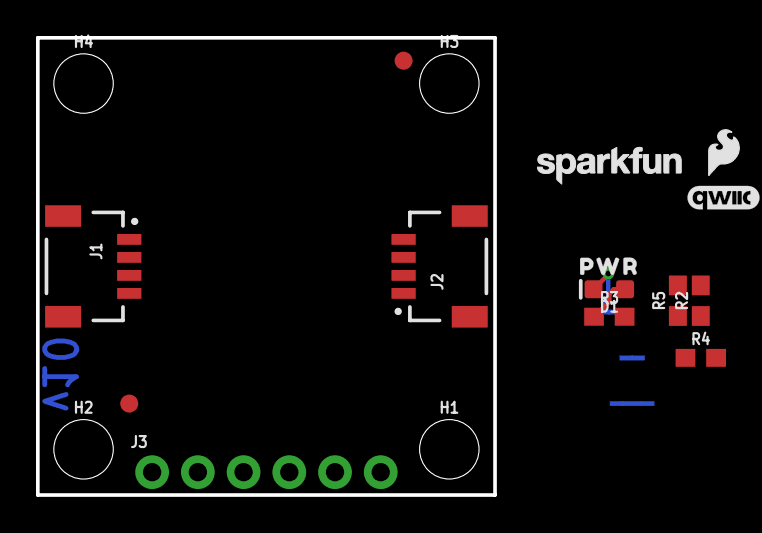
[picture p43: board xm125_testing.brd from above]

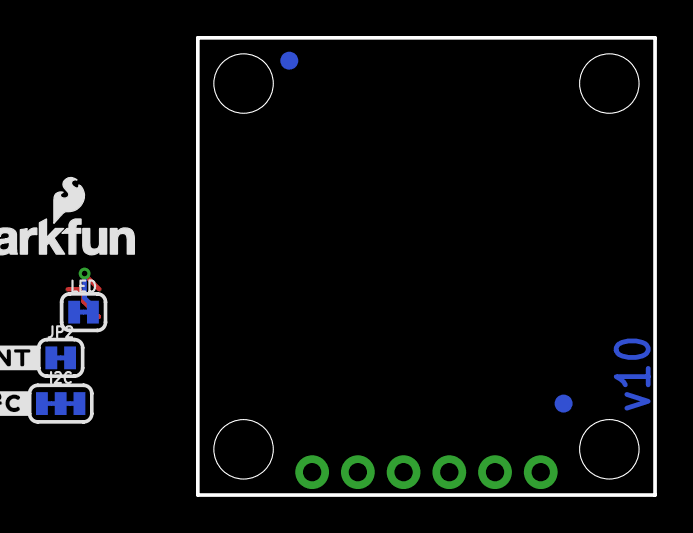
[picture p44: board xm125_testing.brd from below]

Board: 2 copper layers, 25.4 x 25.4 mm, 29 parts (9 on the bottom side), 11 nets.

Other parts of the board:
U$6: #INT#5289
U$7: PWR41
U$10: #I�C#0

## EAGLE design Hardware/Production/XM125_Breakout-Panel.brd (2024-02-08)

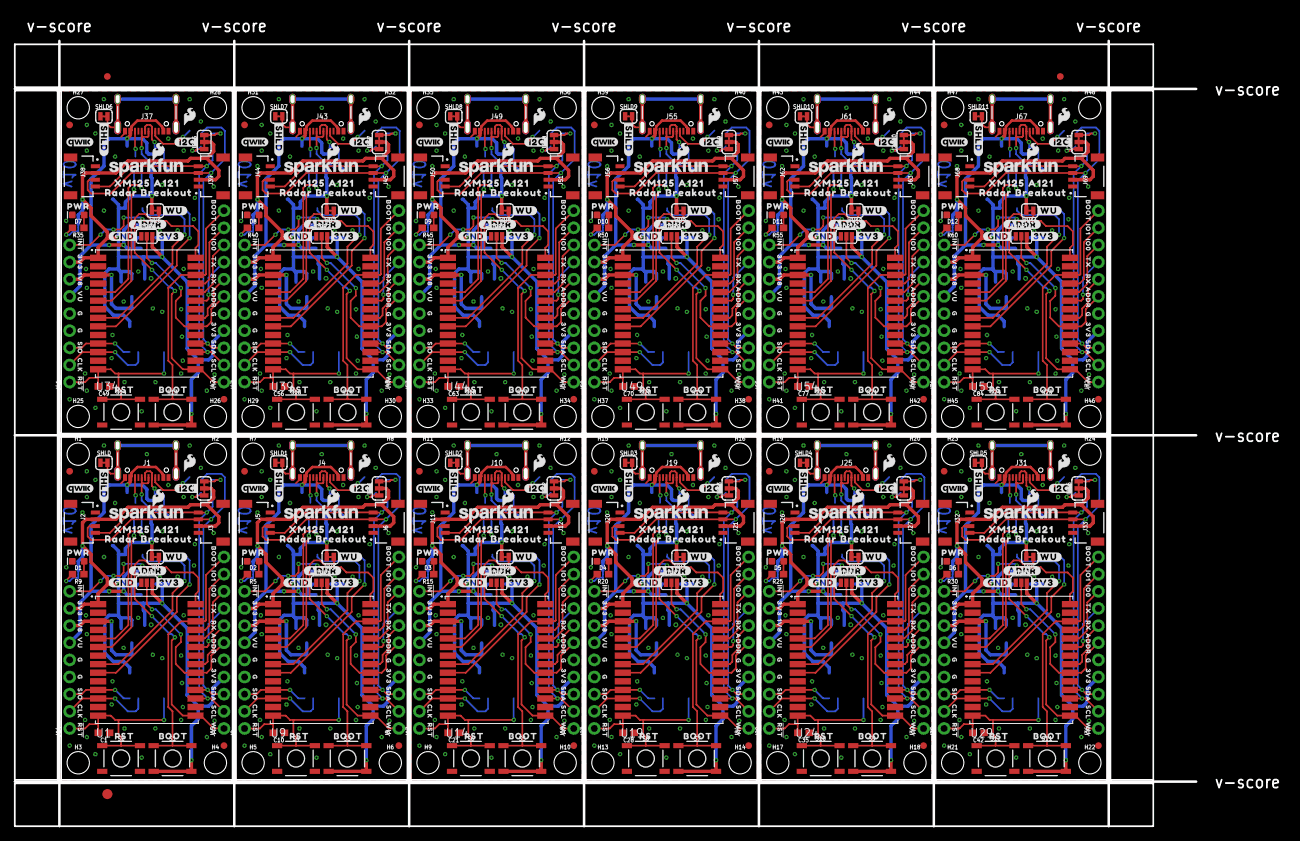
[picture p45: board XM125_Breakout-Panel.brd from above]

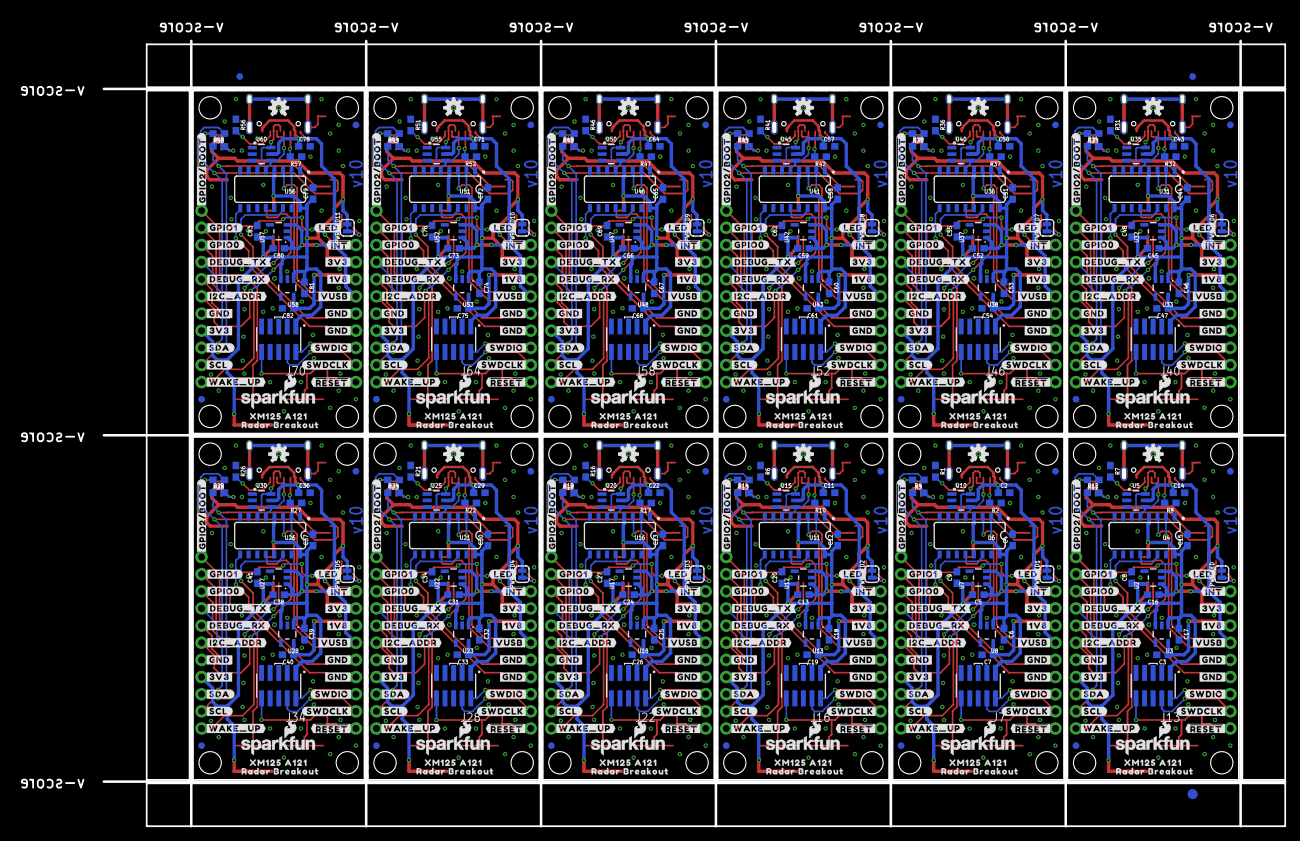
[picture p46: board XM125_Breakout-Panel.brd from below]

Board: 2 copper layers, 175.0 x 116.3 mm, 1182 parts (519 on the bottom side), 360 nets.

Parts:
ADDR, ADDR1, ADDR2, ADDR3, ADDR4, ADDR5, ADDR6, ADDR7, ADDR8, ADDR9, ADDR10, ADDR11: JUMPER-SMT_3_NO_SILK; SMT-JUMPER_3_NO_SILK
C1, C2, C4, C10, C11, C12, C14, C15, C21, C22, C23, C28, C29, C30, C35, C36, C37, C42, C43, C44, C49, C50, C51, C56, C57, C58, C63, C64, C65, C70, C71, C72, C77, C78, C79, C84: 0.1uF; 0603
C3, C7, C8, C9, C19, C20, C26, C27, C33, C34, C40, C41, C47, C48, C54, C55, C61, C62, C68, C69, C75, C76, C82, C83: 22uF; 0603
C5, C6, C13, C16, C17, C18, C24, C25, C31, C32, C38, C39, C45, C46, C52, C53, C59, C60, C66, C67, C73, C74, C80, C81: 2.2uF; 0603
D1, D2, D3, D4, D5, D6, D7, D8, D9, D10, D11, D12: Red; LED-0603
E$1, E$2, E$3, E$4: FIDUCIAL-1X2
E$5, E$6: FIDUCIAL-1.5X3
FD1, FD2, FD3, FD4, FD5, FD6, FD7, FD8, FD9, FD10, FD11, FD12, FD13, FD14, FD15, FD16, FD17, FD18, FD19, FD20, FD21, FD22, FD23, FD24, FD25, FD26, FD27, FD28, FD29, FD30, FD31, FD32, FD33, FD34, FD35, FD36, FD37, FD38, FD39, FD40, FD41, FD42, FD43, FD44, FD45, FD46, FD47, FD48: FIDUCIAL1X2; FIDUCIAL-1X2
H1, H2, H3, H4, H5, H6, H7, H8, H9, H10, H11, H12, H13, H14, H15, H16, H17, H18, H19, H20, H21, H22, H23, H24, H25, H26, H27, H28, H29, H30, H31, H32, H33, H34, H35, H36, H37, H38, H39, H40, H41, H42, H43, H44, H45, H46, H47, H48: STAND-OFF
I2C, I2C1, I2C2, I2C3, I2C4, I2C5, I2C6, I2C7, I2C8, I2C9, I2C10, I2C11: JUMPER-SMT_3_2-NC_TRACE_SILK; SMT-JUMPER_3_2-NC_TRACE_SILK
J1, J4, J10, J19, J25, J31, J37, J43, J49, J55, J61, J67: USB-C-16P-2LAYER-PADS
J2, J3, J5, J6, J11, J12, J20, J21, J26, J27, J32, J33, J38, J39, J44, J45, J50, J51, J56, J57, J62, J63, J68, J69: RIGHT_ANGLE; JST04_1MM_RA
J7, J13, J16, J22, J28, J34, J40, J46, J52, J58, J64, J70: SWD (DNP); 2X5-SMD-UNSHROUDED_DNP_NO_PASTE
J8, J14, J17, J23, J29, J35, J41, J47, J53, J59, J65, J71: 1X09_NO_SILK
J9, J15, J18, J24, J30, J36, J42, J48, J54, J60, J66, J72: 1X11_NO_SILK
LOGO1, LOGO2, LOGO11, LOGO16, LOGO21, LOGO26, LOGO31, LOGO36, LOGO41, LOGO46, LOGO51, LOGO56: QWIIC_LOGO_4MM; QWIIC_4MM
LOGO3, LOGO6, LOGO7, LOGO10, LOGO12, LOGO15, LOGO17, LOGO20, LOGO22, LOGO25, LOGO27, LOGO30, LOGO32, LOGO35, LOGO37, LOGO40, LOGO42, LOGO45, LOGO47, LOGO50, LOGO52, LOGO55, LOGO57, LOGO60: SFE_LOGO_NAME_FLAME.1_INCH; SFE_LOGO_NAME_FLAME_.1
LOGO4, LOGO8, LOGO13, LOGO18, LOGO23, LOGO28, LOGO33, LOGO38, LOGO43, LOGO48, LOGO53, LOGO58: OSHW-LOGOS; OSHW-LOGO-S
LOGO5, LOGO9, LOGO14, LOGO19, LOGO24, LOGO29, LOGO34, LOGO39, LOGO44, LOGO49, LOGO54, LOGO59: SFE_LOGO_FLAME.1_INCH; SFE_LOGO_FLAME_.1
PWR_LED, PWR_LED1, PWR_LED2, PWR_LED3, PWR_LED4, PWR_LED5, PWR_LED6, PWR_LED7, PWR_LED8, PWR_LED9, PWR_LED10, PWR_LED11: JUMPER-SMT_2_NC_TRACE_SILK; SMT-JUMPER_2_NC_TRACE_SILK
R1, R2, R6, R7, R8, R10, R16, R17, R21, R22, R26, R27, R31, R32, R36, R37, R41, R42, R46, R47, R51, R52, R56, R57: 5.1k; 0603
R3, R4, R11, R12, R13, R14, R18, R19, R23, R24, R28, R29, R33, R34, R38, R39, R43, R44, R48, R49, R53, R54, R58, R59: 2.2k; 0603
R5, R9, R15, R20, R25, R30, R35, R40, R45, R50, R55, R60: 4.7k; 0603
S1, S2, S3, S4, S5, S6, S7, S8, S9, S10, S11, S12, S13, S14, S15, S16, S17, S18, S19, S20, S21, S22, S23, S24: TACTILE_SWITCH_SMD_5.2MM
SHLD, SHLD1, SHLD2, SHLD3, SHLD4, SHLD5, SHLD6, SHLD7, SHLD8, SHLD9, SHLD10, SHLD11: JUMPER-SMT_2_NC_TRACE_SILK; SMT-JUMPER_2_NC_TRACE_SILK
U1, U9, U14, U19, U24, U29, U34, U39, U44, U49, U54, U59: XM125; XM125_ACC
U2, U7, U12, U17, U22, U27, U32, U37, U42, U47, U52, U57: RT9080-33GJ5; SOT23-5
U3, U8, U13, U18, U23, U28, U33, U38, U43, U48, U53, U58: RT9080-18GJ5; SOT23-5
U4, U6, U11, U16, U21, U26, U31, U36, U41, U46, U51, U56: CH340C; SO016
U5, U10, U15, U20, U25, U30, U35, U40, U45, U50, U55, U60: ESD Diode; SOT-23-6
U$1, U$72, U$126, U$180, U$234, U$288, U$342, U$396, U$450, U$504, U$558, U$612: #INT143
U$2, U$96, U$150, U$204, U$258, U$312, U$366, U$420, U$474, U$528, U$582, U$636: ##INT#2
U$3, U$64, U$118, U$172, U$226, U$280, U$334, U$388, U$442, U$496, U$550, U$604: #LED#139
U$4, U$30, U$31, U$68, U$69, U$70, U$122, U$123, U$124, U$176, U$177, U$178, U$230, U$231, U$232, U$284, U$285, U$286, U$338, U$339, U$340, U$392, U$393, U$394, U$446, U$447, U$448, U$500, U$501, U$502, U$554, U$555, U$556, U$608, U$609, U$610: #GND#141
U$5, U$52, U$110, U$164, U$218, U$272, U$326, U$380, U$434, U$488, U$542, U$596: RST1630063003525
U$6, U$85, U$139, U$193, U$247, U$301, U$355, U$409, U$463, U$517, U$571, U$625: RX1152
U$7, U$97, U$151, U$205, U$259, U$313, U$367, U$421, U$475, U$529, U$583, U$637: #SWDIO#4
U$8, U$95, U$149, U$203, U$257, U$311, U$365, U$419, U$473, U$527, U$581, U$635: #VUSB#1
U$9, U$105, U$159, U$213, U$267, U$321, U$375, U$429, U$483, U$537, U$591, U$645: #3V3#17
U$10, U$58, U$112, U$166, U$220, U$274, U$328, U$382, U$436, U$490, U$544, U$598: #SCL#8
U$11, U$37, U$109, U$163, U$217, U$271, U$325, U$379, U$433, U$487, U$541, U$595: BOOT21630063003532
U$12, U$57, U$111, U$165, U$219, U$273, U$327, U$381, U$435, U$489, U$543, U$597: PWR21630063003533
U$13, U$59, U$113, U$167, U$221, U$275, U$329, U$383, U$437, U$491, U$545, U$599: #SDA#9
U$14, U$33, U$73, U$75, U$127, U$129, U$181, U$183, U$235, U$237, U$289, U$291, U$343, U$345, U$397, U$399, U$451, U$453, U$505, U$507, U$559, U$561, U$613, U$615: 3V3144
U$15, U$74, U$128, U$182, U$236, U$290, U$344, U$398, U$452, U$506, U$560, U$614: 1V8144
U$16, U$67, U$121, U$175, U$229, U$283, U$337, U$391, U$445, U$499, U$553, U$607: #1V8#141
U$17, U$91, U$145, U$199, U$253, U$307, U$361, U$415, U$469, U$523, U$577, U$631: RADAR_BREAKOUT1163
U$18, U$99, U$153, U$207, U$261, U$315, U$369, U$423, U$477, U$531, U$585, U$639: WU9
U$19, U$98, U$152, U$206, U$260, U$314, U$368, U$422, U$476, U$530, U$584, U$638: #RST6
U$20, U$60, U$114, U$168, U$222, U$276, U$330, U$384, U$438, U$492, U$546, U$600: #GPIO0#5
U$21, U$61, U$115, U$169, U$223, U$277, U$331, U$385, U$439, U$493, U$547, U$601: #GPIO1#5
U$22, U$103, U$157, U$211, U$265, U$319, U$373, U$427, U$481, U$535, U$589, U$643: #WU#14
U$23, U$32, U$66, U$71, U$120, U$125, U$174, U$179, U$228, U$233, U$282, U$287, U$336, U$341, U$390, U$395, U$444, U$449, U$498, U$503, U$552, U$557, U$606, U$611: #3V3#141
U$24, U$92, U$146, U$200, U$254, U$308, U$362, U$416, U$470, U$524, U$578, U$632: XM125_A1211163
U$25, U$104, U$158, U$212, U$266, U$320, U$374, U$428, U$482, U$536, U$590, U$644: #ADDR#16
U$26, U$62, U$116, U$170, U$224, U$278, U$332, U$386, U$440, U$494, U$548, U$602: #I2C#126
U$27, U$65, U$119, U$173, U$227, U$281, U$335, U$389, U$443, U$497, U$551, U$605: #GPIO2##BOOT#141
U$28, U$108, U$162, U$216, U$270, U$324, U$378, U$432, U$486, U$540, U$594, U$648: #DEBUG_RX#19
U$29, U$63, U$117, U$171, U$225, U$279, U$333, U$387, U$441, U$495, U$549, U$603: #SHLD#129
U$34, U$35, U$36, U$76, U$77, U$78, U$130, U$131, U$132, U$184, U$185, U$186, U$238, U$239, U$240, U$292, U$293, U$294, U$346, U$347, U$348, U$400, U$401, U$402, U$454, U$455, U$456, U$508, U$509, U$510, U$562, U$563, U$564, U$616, U$617, U$618: G144
U$38, U$79, U$133, U$187, U$241, U$295, U$349, U$403, U$457, U$511, U$565, U$619: VU146
U$39, U$80, U$134, U$188, U$242, U$296, U$350, U$404, U$458, U$512, U$566, U$620: IO0147
U$40, U$81, U$135, U$189, U$243, U$297, U$351, U$405, U$459, U$513, U$567, U$621: IO1148
U$41, U$82, U$136, U$190, U$244, U$298, U$352, U$406, U$460, U$514, U$568, U$622: BOOT1149
U$42, U$83, U$137, U$191, U$245, U$299, U$353, U$407, U$461, U$515, U$569, U$623: CLK1150
U$43, U$84, U$138, U$192, U$246, U$300, U$354, U$408, U$462, U$516, U$570, U$624: #SWDCLK#1151
U$44, U$86, U$140, U$194, U$248, U$302, U$356, U$410, U$464, U$518, U$572, U$626: TX1153
U$45, U$87, U$141, U$195, U$249, U$303, U$357, U$411, U$465, U$519, U$573, U$627: ADDR1154
U$46, U$88, U$142, U$196, U$250, U$304, U$358, U$412, U$466, U$520, U$574, U$628: SDA1155
U$47, U$89, U$143, U$197, U$251, U$305, U$359, U$413, U$467, U$521, U$575, U$629: SCL1157
U$48, U$100, U$154, U$208, U$262, U$316, U$370, U$424, U$478, U$532, U$586, U$640: #I2C_ADDR#12
U$49, U$90, U$144, U$198, U$252, U$306, U$360, U$414, U$468, U$522, U$576, U$630: SIO1159
U$50, U$106, U$160, U$214, U$268, U$322, U$376, U$430, U$484, U$538, U$592, U$646: #GND#17
U$51, U$107, U$161, U$215, U$269, U$323, U$377, U$431, U$485, U$539, U$593, U$647: #DEBUG_TX#18
U$53, U$93, U$147, U$201, U$255, U$309, U$363, U$417, U$471, U$525, U$579, U$633: RADAR_BREAKOUT1166
U$54, U$94, U$148, U$202, U$256, U$310, U$364, U$418, U$472, U$526, U$580, U$634: XM125_A1211167
U$55, U$101, U$155, U$209, U$263, U$317, U$371, U$425, U$479, U$533, U$587, U$641: #WAKE_UP#12
U$56, U$102, U$156, U$210, U$264, U$318, U$372, U$426, U$480, U$534, U$588, U$642: ##RESET#13
WU, WU1, WU2, WU3, WU4, WU5, WU6, WU7, WU8, WU9, WU10, WU11: JUMPER-SMT_2_NC_TRACE_SILK; SMT-JUMPER_2_NC_TRACE_SILK

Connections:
1.8V: C3.1, J14.7, U1.3, U3.5
1.8V1: C7.1, J8.7, U8.5, U9.3
1.8V2: C19.1, J17.7, U13.5, U14.3
1.8V3: C26.1, J23.7, U18.5, U19.3
1.8V4: C33.1, J29.7, U23.5, U24.3
1.8V5: C40.1, J35.7, U28.5, U29.3
1.8V6: C47.1, J41.7, U33.5, U34.3
1.8V7: C54.1, J47.7, U38.5, U39.3
1.8V8: C61.1, J53.7, U43.5, U44.3
1.8V9: C68.1, J59.7, U48.5, U49.3
1.8V10: C75.1, J65.7, U53.5, U54.3
1.8V11: C82.1, J71.7, U58.5, U59.3
3.3V: ADDR.3, C8.1, C15.1, C17.1, I2C.2, J2.2, J3.2, J13.1, J14.8, J15.4, PWR_LED.2, S1.3, S1.4, U1.1, U2.5, U3.1, U3.3, U4.4, U4.16, WU.2
3.3V1: ADDR1.3, C4.1, C6.1, C9.1, I2C1.2, J5.2, J6.2, J7.1, J8.8, J9.4, PWR_LED1.2, S3.3, S3.4, U6.4, U6.16, U7.5, U8.1, U8.3, U9.1, WU1.2
3.3V2: ADDR2.3, C12.1, C18.1, C20.1, I2C2.2, J11.2, J12.2, J16.1, J17.8, J18.4, PWR_LED2.2, S5.3, S5.4, U11.4, U11.16, U12.5, U13.1, U13.3, U14.1, WU2.2
3.3V3: ADDR3.3, C23.1, C25.1, C27.1, I2C3.2, J20.2, J21.2, J22.1, J23.8, J24.4, PWR_LED3.2, S7.3, S7.4, U16.4, U16.16, U17.5, U18.1, U18.3, U19.1, WU3.2
3.3V4: ADDR4.3, C30.1, C32.1, C34.1, I2C4.2, J26.2, J27.2, J28.1, J29.8, J30.4, PWR_LED4.2, S9.3, S9.4, U21.4, U21.16, U22.5, U23.1, U23.3, U24.1, WU4.2
3.3V5: ADDR5.3, C37.1, C39.1, C41.1, I2C5.2, J32.2, J33.2, J34.1, J35.8, J36.4, PWR_LED5.2, S11.3, S11.4, U26.4, U26.16, U27.5, U28.1, U28.3, U29.1, WU5.2
3.3V6: ADDR6.3, C44.1, C46.1, C48.1, I2C6.2, J38.2, J39.2, J40.1, J41.8, J42.4, PWR_LED6.2, S13.3, S13.4, U31.4, U31.16, U32.5, U33.1, U33.3, U34.1, WU6.2
3.3V7: ADDR7.3, C51.1, C53.1, C55.1, I2C7.2, J44.2, J45.2, J46.1, J47.8, J48.4, PWR_LED7.2, S15.3, S15.4, U36.4, U36.16, U37.5, U38.1, U38.3, U39.1, WU7.2
3.3V8: ADDR8.3, C58.1, C60.1, C62.1, I2C8.2, J50.2, J51.2, J52.1, J53.8, J54.4, PWR_LED8.2, S17.3, S17.4, U41.4, U41.16, U42.5, U43.1, U43.3, U44.1, WU8.2
3.3V9: ADDR9.3, C65.1, C67.1, C69.1, I2C9.2, J56.2, J57.2, J58.1, J59.8, J60.4, PWR_LED9.2, S19.3, S19.4, U46.4, U46.16, U47.5, U48.1, U48.3, U49.1, WU9.2
3.3V10: ADDR10.3, C72.1, C74.1, C76.1, I2C10.2, J62.2, J63.2, J64.1, J65.8, J66.4, PWR_LED10.2, S21.3, S21.4, U51.4, U51.16, U52.5, U53.1, U53.3, U54.1, WU10.2
3.3V11: ADDR11.3, C79.1, C81.1, C83.1, I2C11.2, J68.2, J69.2, J70.1, J71.8, J72.4, PWR_LED11.2, S23.3, S23.4, U56.4, U56.16, U57.5, U58.1, U58.3, U59.1, WU11.2
!XM125_INT: J14.9, U1.28
!XM125_INT1: J8.9, U9.28
!XM125_INT2: J17.9, U14.28
!XM125_INT3: J23.9, U19.28
!XM125_INT4: J29.9, U24.28
!XM125_INT5: J35.9, U29.28
!XM125_INT6: J41.9, U34.28
!XM125_INT7: J47.9, U39.28
!XM125_INT8: J53.9, U44.28
!XM125_INT9: J59.9, U49.28
!XM125_INT10: J65.9, U54.28
!XM125_INT11: J71.9, U59.28
!XM125_RESET: C1.2, J13.10, J14.1, S2.1, S2.2, U1.14
!XM125_RESET1: C10.2, J7.10, J8.1, S4.1, S4.2, U9.14
!XM125_RESET2: C21.2, J16.10, J17.1, S6.1, S6.2, U14.14
!XM125_RESET3: C28.2, J22.10, J23.1, S8.1, S8.2, U19.14
!XM125_RESET4: C35.2, J28.10, J29.1, S10.1, S10.2, U24.14
!XM125_RESET5: C42.2, J34.10, J35.1, S12.1, S12.2, U29.14
!XM125_RESET6: C49.2, J40.10, J41.1, S14.1, S14.2, U34.14
!XM125_RESET7: C56.2, J46.10, J47.1, S16.1, S16.2, U39.14
!XM125_RESET8: C63.2, J52.10, J53.1, S18.1, S18.2, U44.14
!XM125_RESET9: C70.2, J58.10, J59.1, S20.1, S20.2, U49.14
!XM125_RESET10: C77.2, J64.10, J65.1, S22.1, S22.2, U54.14
!XM125_RESET11: C84.2, J70.10, J71.1, S24.1, S24.2, U59.14
CH340-CTS: U1.9, U4.9
CH340-CTS1: U6.9, U9.9
CH340-CTS2: U11.9, U14.9
CH340-CTS3: U16.9, U19.9
CH340-CTS4: U21.9, U24.9
CH340-CTS5: U26.9, U29.9
CH340-CTS6: U31.9, U34.9
CH340-CTS7: U36.9, U39.9
CH340-CTS8: U41.9, U44.9
CH340-CTS9: U46.9, U49.9
CH340-CTS10: U51.9, U54.9
CH340-CTS11: U56.9, U59.9
CH340-RTS: U1.8, U4.14
CH340-RTS1: U6.14, U9.8
CH340-RTS2: U11.14, U14.8
CH340-RTS3: U16.14, U19.8
CH340-RTS4: U21.14, U24.8
CH340-RTS5: U26.14, U29.8
CH340-RTS6: U31.14, U34.8
CH340-RTS7: U36.14, U39.8
CH340-RTS8: U41.14, U44.8
CH340-RTS9: U46.14, U49.8
CH340-RTS10: U51.14, U54.8
CH340-RTS11: U56.14, U59.8
CH340-RX: U1.5, U4.3
CH340-RX1: U6.3, U9.5
CH340-RX2: U11.3, U14.5
CH340-RX3: U16.3, U19.5
CH340-RX4: U21.3, U24.5
CH340-RX5: U26.3, U29.5
CH340-RX6: U31.3, U34.5
CH340-RX7: U36.3, U39.5
CH340-RX8: U41.3, U44.5
CH340-RX9: U46.3, U49.5
CH340-RX10: U51.3, U54.5
CH340-RX11: U56.3, U59.5
CH340-TX: U1.6, U4.2
CH340-TX1: U6.2, U9.6
CH340-TX2: U11.2, U14.6
CH340-TX3: U16.2, U19.6
CH340-TX4: U21.2, U24.6
CH340-TX5: U26.2, U29.6
CH340-TX6: U31.2, U34.6
CH340-TX7: U36.2, U39.6
CH340-TX8: U41.2, U44.6
CH340-TX9: U46.2, U49.6
CH340-TX10: U51.2, U54.6
CH340-TX11: U56.2, U59.6
DEBUG_UART-RX: J15.7, U1.21
DEBUG_UART-RX1: J9.7, U9.21
DEBUG_UART-RX2: J18.7, U14.21
DEBUG_UART-RX3: J24.7, U19.21
DEBUG_UART-RX4: J30.7, U24.21
DEBUG_UART-RX5: J36.7, U29.21
DEBUG_UART-RX6: J42.7, U34.21
DEBUG_UART-RX7: J48.7, U39.21
DEBUG_UART-RX8: J54.7, U44.21
DEBUG_UART-RX9: J60.7, U49.21
DEBUG_UART-RX10: J66.7, U54.21
DEBUG_UART-RX11: J72.7, U59.21
DEBUG_UART-TX: J15.8, U1.23
DEBUG_UART-TX1: J9.8, U9.23
DEBUG_UART-TX2: J18.8, U14.23
DEBUG_UART-TX3: J24.8, U19.23
DEBUG_UART-TX4: J30.8, U24.23
DEBUG_UART-TX5: J36.8, U29.23
DEBUG_UART-TX6: J42.8, U34.23
DEBUG_UART-TX7: J48.8, U39.23
DEBUG_UART-TX8: J54.8, U44.23
DEBUG_UART-TX9: J60.8, U49.23
DEBUG_UART-TX10: J66.8, U54.23
DEBUG_UART-TX11: J72.8, U59.23
GND: ADDR.1, C1.1, C3.2, C8.2, C14.2, C15.2, C16.2, C17.2, D1.C, J1.GND, J1.GND2, J2.1, J3.1, J13.3, J13.5, J13.9, J14.4, J14.5, J15.5, R7.1, R8.1, S2.3, S2.4, SHLD.1, U1.2, U1.4, U1.7, U1.10, U1.13, U1.16, U1.19, U1.22, U1.27, U2.2, U3.2, U4.1, U5.2
GND1: ADDR1.1, C2.2, C4.2, C5.2, C6.2, C7.2, C9.2, C10.1, D2.C, J4.GND, J4.GND2, J5.1, J6.1, J7.3, J7.5, J7.9, J8.4, J8.5, J9.5, R1.1, R2.1, S4.3, S4.4, SHLD1.1, U6.1, U7.2, U8.2, U9.2, U9.4, U9.7, U9.10, U9.13, U9.16, U9.19, U9.22, U9.27, U10.2
GND2: ADDR2.1, C11.2, C12.2, C13.2, C18.2, C19.2, C20.2, C21.1, D3.C, J10.GND, J10.GND2, J11.1, J12.1, J16.3, J16.5, J16.9, J17.4, J17.5, J18.5, R6.1, R10.1, S6.3, S6.4, SHLD2.1, U11.1, U12.2, U13.2, U14.2, U14.4, U14.7, U14.10, U14.13, U14.16, U14.19, U14.22, U14.27, U15.2
GND3: ADDR3.1, C22.2, C23.2, C24.2, C25.2, C26.2, C27.2, C28.1, D4.C, J19.GND, J19.GND2, J20.1, J21.1, J22.3, J22.5, J22.9, J23.4, J23.5, J24.5, R16.1, R17.1, S8.3, S8.4, SHLD3.1, U16.1, U17.2, U18.2, U19.2, U19.4, U19.7, U19.10, U19.13, U19.16, U19.19, U19.22, U19.27, U20.2
GND4: ADDR4.1, C29.2, C30.2, C31.2, C32.2, C33.2, C34.2, C35.1, D5.C, J25.GND, J25.GND2, J26.1, J27.1, J28.3, J28.5, J28.9, J29.4, J29.5, J30.5, R21.1, R22.1, S10.3, S10.4, SHLD4.1, U21.1, U22.2, U23.2, U24.2, U24.4, U24.7, U24.10, U24.13, U24.16, U24.19, U24.22, U24.27, U25.2
GND5: ADDR5.1, C36.2, C37.2, C38.2, C39.2, C40.2, C41.2, C42.1, D6.C, J31.GND, J31.GND2, J32.1, J33.1, J34.3, J34.5, J34.9, J35.4, J35.5, J36.5, R26.1, R27.1, S12.3, S12.4, SHLD5.1, U26.1, U27.2, U28.2, U29.2, U29.4, U29.7, U29.10, U29.13, U29.16, U29.19, U29.22, U29.27, U30.2
GND6: ADDR6.1, C43.2, C44.2, C45.2, C46.2, C47.2, C48.2, C49.1, D7.C, J37.GND, J37.GND2, J38.1, J39.1, J40.3, J40.5, J40.9, J41.4, J41.5, J42.5, R31.1, R32.1, S14.3, S14.4, SHLD6.1, U31.1, U32.2, U33.2, U34.2, U34.4, U34.7, U34.10, U34.13, U34.16, U34.19, U34.22, U34.27, U35.2
GND7: ADDR7.1, C50.2, C51.2, C52.2, C53.2, C54.2, C55.2, C56.1, D8.C, J43.GND, J43.GND2, J44.1, J45.1, J46.3, J46.5, J46.9, J47.4, J47.5, J48.5, R36.1, R37.1, S16.3, S16.4, SHLD7.1, U36.1, U37.2, U38.2, U39.2, U39.4, U39.7, U39.10, U39.13, U39.16, U39.19, U39.22, U39.27, U40.2
GND8: ADDR8.1, C57.2, C58.2, C59.2, C60.2, C61.2, C62.2, C63.1, D9.C, J49.GND, J49.GND2, J50.1, J51.1, J52.3, J52.5, J52.9, J53.4, J53.5, J54.5, R41.1, R42.1, S18.3, S18.4, SHLD8.1, U41.1, U42.2, U43.2, U44.2, U44.4, U44.7, U44.10, U44.13, U44.16, U44.19, U44.22, U44.27, U45.2
GND9: ADDR9.1, C64.2, C65.2, C66.2, C67.2, C68.2, C69.2, C70.1, D10.C, J55.GND, J55.GND2, J56.1, J57.1, J58.3, J58.5, J58.9, J59.4, J59.5, J60.5, R46.1, R47.1, S20.3, S20.4, SHLD9.1, U46.1, U47.2, U48.2, U49.2, U49.4, U49.7, U49.10, U49.13, U49.16, U49.19, U49.22, U49.27, U50.2
GND10: ADDR10.1, C71.2, C72.2, C73.2, C74.2, C75.2, C76.2, C77.1, D11.C, J61.GND, J61.GND2, J62.1, J63.1, J64.3, J64.5, J64.9, J65.4, J65.5, J66.5, R51.1, R52.1, S22.3, S22.4, SHLD10.1, U51.1, U52.2, U53.2, U54.2, U54.4, U54.7, U54.10, U54.13, U54.16, U54.19, U54.22, U54.27, U55.2
GND11: ADDR11.1, C78.2, C79.2, C80.2, C81.2, C82.2, C83.2, C84.1, D12.C, J67.GND, J67.GND2, J68.1, J69.1, J70.3, J70.5, J70.9, J71.4, J71.5, J72.5, R56.1, R57.1, S24.3, S24.4, SHLD11.1, U56.1, U57.2, U58.2, U59.2, U59.4, U59.7, U59.10, U59.13, U59.16, U59.19, U59.22, U59.27, U60.2
unnamed: J1.A6, J1.B6, U4.5, U5.4
unnamed: J1.A7, J1.B7, U4.6, U5.6
unnamed: J4.A6, J4.B6, U6.5, U10.4
unnamed: J4.A7, J4.B7, U6.6, U10.6
unnamed: J4.SHLD1, J4.SHLD2, J4.SHLD3, J4.SHLD4, SHLD1.2
unnamed: J4.B5, R2.2
unnamed: J4.A5, R1.2
unnamed: PWR_LED1.1, R5.2
unnamed: J1.SHLD1, J1.SHLD2, J1.SHLD3, J1.SHLD4, SHLD.2
unnamed: J1.B5, R8.2
unnamed: J1.A5, R7.2
unnamed: D2.A, R5.1
unnamed: I2C1.3, R3.2
unnamed: PWR_LED.1, R9.2
unnamed: D1.A, R9.1
unnamed: I2C.3, R11.2
unnamed: I2C.1, R12.2
unnamed: I2C1.1, R4.2
unnamed: J10.A6, J10.B6, U11.5, U15.4
unnamed: J10.A7, J10.B7, U11.6, U15.6
unnamed: J10.SHLD1, J10.SHLD2, J10.SHLD3, J10.SHLD4, SHLD2.2
unnamed: J10.B5, R10.2
unnamed: J10.A5, R6.2
unnamed: PWR_LED2.1, R15.2
unnamed: D3.A, R15.1
unnamed: I2C2.3, R13.2
unnamed: I2C2.1, R14.2
unnamed: J19.A6, J19.B6, U16.5, U20.4
unnamed: J19.A7, J19.B7, U16.6, U20.6
unnamed: J19.SHLD1, J19.SHLD2, J19.SHLD3, J19.SHLD4, SHLD3.2
unnamed: J19.B5, R17.2
unnamed: J19.A5, R16.2
unnamed: PWR_LED3.1, R20.2
unnamed: D4.A, R20.1
unnamed: I2C3.3, R18.2
unnamed: I2C3.1, R19.2
unnamed: J25.A6, J25.B6, U21.5, U25.4
unnamed: J25.A7, J25.B7, U21.6, U25.6
unnamed: J25.SHLD1, J25.SHLD2, J25.SHLD3, J25.SHLD4, SHLD4.2
unnamed: J25.B5, R22.2
unnamed: J25.A5, R21.2
unnamed: PWR_LED4.1, R25.2
unnamed: D5.A, R25.1
unnamed: I2C4.3, R23.2
unnamed: I2C4.1, R24.2
unnamed: J31.A6, J31.B6, U26.5, U30.4
unnamed: J31.A7, J31.B7, U26.6, U30.6
unnamed: J31.SHLD1, J31.SHLD2, J31.SHLD3, J31.SHLD4, SHLD5.2
unnamed: J31.B5, R27.2
unnamed: J31.A5, R26.2
unnamed: PWR_LED5.1, R30.2
unnamed: D6.A, R30.1
unnamed: I2C5.3, R28.2
unnamed: I2C5.1, R29.2
unnamed: J37.A6, J37.B6, U31.5, U35.4
unnamed: J37.A7, J37.B7, U31.6, U35.6
unnamed: J37.SHLD1, J37.SHLD2, J37.SHLD3, J37.SHLD4, SHLD6.2
unnamed: J37.B5, R32.2
unnamed: J37.A5, R31.2
unnamed: PWR_LED6.1, R35.2
unnamed: D7.A, R35.1
unnamed: I2C6.3, R33.2
unnamed: I2C6.1, R34.2
unnamed: J43.A6, J43.B6, U36.5, U40.4
unnamed: J43.A7, J43.B7, U36.6, U40.6
unnamed: J43.SHLD1, J43.SHLD2, J43.SHLD3, J43.SHLD4, SHLD7.2
unnamed: J43.B5, R37.2
unnamed: J43.A5, R36.2
unnamed: PWR_LED7.1, R40.2
unnamed: D8.A, R40.1
unnamed: I2C7.3, R38.2
unnamed: I2C7.1, R39.2
unnamed: J49.A6, J49.B6, U41.5, U45.4
unnamed: J49.A7, J49.B7, U41.6, U45.6
unnamed: J49.SHLD1, J49.SHLD2, J49.SHLD3, J49.SHLD4, SHLD8.2
unnamed: J49.B5, R42.2
unnamed: J49.A5, R41.2
unnamed: PWR_LED8.1, R45.2
unnamed: D9.A, R45.1
unnamed: I2C8.3, R43.2
unnamed: I2C8.1, R44.2
unnamed: J55.A6, J55.B6, U46.5, U50.4
unnamed: J55.A7, J55.B7, U46.6, U50.6
unnamed: J55.SHLD1, J55.SHLD2, J55.SHLD3, J55.SHLD4, SHLD9.2
unnamed: J55.B5, R47.2
unnamed: J55.A5, R46.2
unnamed: PWR_LED9.1, R50.2
unnamed: D10.A, R50.1
unnamed: I2C9.3, R48.2
unnamed: I2C9.1, R49.2
unnamed: J61.A6, J61.B6, U51.5, U55.4
unnamed: J61.A7, J61.B7, U51.6, U55.6
unnamed: J61.SHLD1, J61.SHLD2, J61.SHLD3, J61.SHLD4, SHLD10.2
unnamed: J61.B5, R52.2
unnamed: J61.A5, R51.2
unnamed: PWR_LED10.1, R55.2
unnamed: D11.A, R55.1
unnamed: I2C10.3, R53.2
unnamed: I2C10.1, R54.2
unnamed: J67.A6, J67.B6, U56.5, U60.4
unnamed: J67.A7, J67.B7, U56.6, U60.6
unnamed: J67.SHLD1, J67.SHLD2, J67.SHLD3, J67.SHLD4, SHLD11.2
unnamed: J67.B5, R57.2
unnamed: J67.A5, R56.2
unnamed: PWR_LED11.1, R60.2
unnamed: D12.A, R60.1
unnamed: I2C11.3, R58.2
unnamed: I2C11.1, R59.2
SCL: J2.4, J3.4, J15.2, R12.1, U1.17
SCL1: J5.4, J6.4, J9.2, R4.1, U9.17
SCL2: J11.4, J12.4, J18.2, R14.1, U14.17
SCL3: J20.4, J21.4, J24.2, R19.1, U19.17
SCL4: J26.4, J27.4, J30.2, R24.1, U24.17
SCL5: J32.4, J33.4, J36.2, R29.1, U29.17
SCL6: J38.4, J39.4, J42.2, R34.1, U34.17
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

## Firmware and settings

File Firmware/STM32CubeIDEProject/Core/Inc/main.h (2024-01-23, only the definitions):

#define USART_TX_Pin GPIO_PIN_2
#define USART_TX_GPIO_Port GPIOA
#define USART_RX_Pin GPIO_PIN_3
#define USART_RX_GPIO_Port GPIOA
#define TMS_Pin GPIO_PIN_13
#define TMS_GPIO_Port GPIOA
#define TCK_Pin GPIO_PIN_14
#define TCK_GPIO_Port GPIOA

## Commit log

2023-11-03 Added binaries needed for software
    This is simply a download of the software needed to run the evaluation board
2023-11-10 Addition of XM125 SDK files
    Pulled from Acconeer's website as a download - full credits will be given where due.
    [xm125_testing.brd, xm125_testing.sch]
2023-11-15 Addition of initial Hardware files for breakout
    We will be doing a breakout with this board, no need for 1x1 and thing+ breakout files. Will be keeping until official product definition is given
    [SparkFun_Thing_XM125.brd, SparkFun_Thing_XM125.sch, Thing_Plus_ESP32_C6.sch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]
2023-11-15 Library part completed
    Adjusted the file structure name to no longer have a space in it. Finished the library part for the schematic
    [XM125_Breakout.brd, XM125_Breakout.sch]
2023-12-05 Removed uneeded board files; updates to breakout board
    Removed the 1x1 and Thing+ board options; updated the schematic and layout - grouped together the needed sections in the layout
    [SparkFun_Thing_XM125.brd, SparkFun_Thing_XM125.sch, XM125_Breakout.brd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]
2023-12-06 Addition of further documentation; initial schematic ready for review
    Fixed small issues on schematic; added I2C documentation to the repo
    [XM125_Breakout.brd, XM125_Breakout.sch]
2023-12-11 Updates as per schematic review
    For full detailed list of changes, see XM125 Schematic review document
    [XM125_Breakout.brd, XM125_Breakout.sch]
2023-12-18 Updated files for design review
    Nearing completion and ready for design review - completed layout, added measures, added labels, name, logos
    [XM125_Breakout.brd, XM125_Breakout.sch]
2023-12-18 Slight aesthetic change - ready for review!
    Ready for protos review
    [XM125_Breakout.brd]
2023-12-19 Changes from design review
    Final changes made - ready for re-review one last time before ordering protos
    For full list of changes, see Protos Review document
    [XM125_Breakout.brd, XM125_Breakout.sch]
2023-12-21 Production files added
    [XM125_Breakout.GBL, XM125_Breakout.GBO, XM125_Breakout.GBP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]
2024-01-18 Added specific firmware for presence and distance sensing
    All of the XM125 firmware was broken up into presence and distance - will be uploading distance sensing onto device initially
    [Thing_Plus_ESP32_C6.sch, XM125_Breakout.brd]
2024-01-23 Initial commit for v10 red boards; adjusted firmware files
    Small changes made for board - removed EN pullups, changed button part number; no need for distance and presence file differentiation - just run with binaries in the original SDK; added STM32CubeIDEP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
    [XM125_Breakout.brd, XM125_Breakout.sch]
2024-02-07 Changes for reds review completed; panel files added
    Changes for review have been made; panelized files have been added
    [XM125_Breakout-Panel.GBL, XM125_Breakout-Panel.GBO, XM125_Breakout-Panel.GBP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]
2024-02-08 Cleanup repo; design review changes
    Check design review document for full list of changes/details.
    [XM125_Breakout-Panel.GBL, XM125_Breakout-Panel.GBO, XM125_Breakout-Panel.GBP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]
2024-02-08 Final changes; reds ready for ordering!
    Finished up Dryw's comments: see google doc for more information on specific changes made; panelized files updated and ready for ordering
    [XM125_Breakout-Panel.brd, XM125_Breakout.brd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]
2024-04-02 Add notes for clarification on range in Arduino Examples
2024-04-11 Add Additional Step, Troubleshooting Tips, and CSS fix
    - Move troubleshooting tip from STM32CubeProgrammer Section to Troubleshooting section
    - Add additional step to configure COM port when connecting Acconeer Exploration Tool
    - Add errors in Troubleshooting section
    - Add Wes' fix to enable word/line wrap in code blocks

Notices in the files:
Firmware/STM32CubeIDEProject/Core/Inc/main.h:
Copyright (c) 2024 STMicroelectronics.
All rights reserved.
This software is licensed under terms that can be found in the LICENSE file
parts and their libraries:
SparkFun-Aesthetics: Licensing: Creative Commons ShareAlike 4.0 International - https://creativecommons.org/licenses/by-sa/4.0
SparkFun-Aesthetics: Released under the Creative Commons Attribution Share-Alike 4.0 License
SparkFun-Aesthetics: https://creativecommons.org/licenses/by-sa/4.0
